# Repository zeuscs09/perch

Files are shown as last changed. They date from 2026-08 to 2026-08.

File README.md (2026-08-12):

<p align="center">
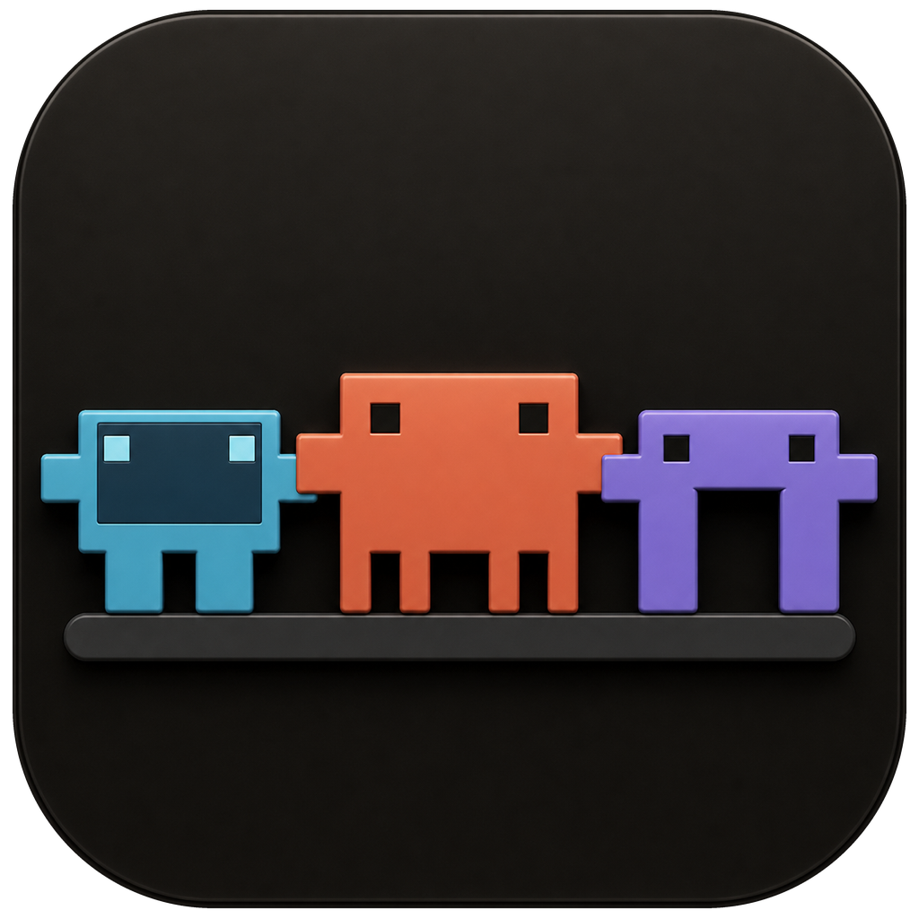
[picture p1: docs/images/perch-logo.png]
  
</p>

<h1 align="center">Perch</h1>

<p align="center">
  <strong>A little screen that perches on your desk</strong> — what your coding agents are
  doing, without giving up a window for it.
</p>

<p align="center">
  
  
  
  
  
  
</p>

<p align="center">
  🌐 <strong>English</strong> · <a href="README.th.md">ไทย</a>
</p>

<p align="center">
  <a href="#what-the-screen-says">What the screen says</a> ·
  <a href="#what-you-need">What you need</a> ·
  <a href="#1-get-the-repository-and-the-swift-compiler">Getting started</a> ·
  <a href="#the-case">The case</a> ·
  <a href="#on-the-go">On the go</a> ·
  <a href="#troubleshooting">Troubleshooting</a>
</p>

<p align="center">
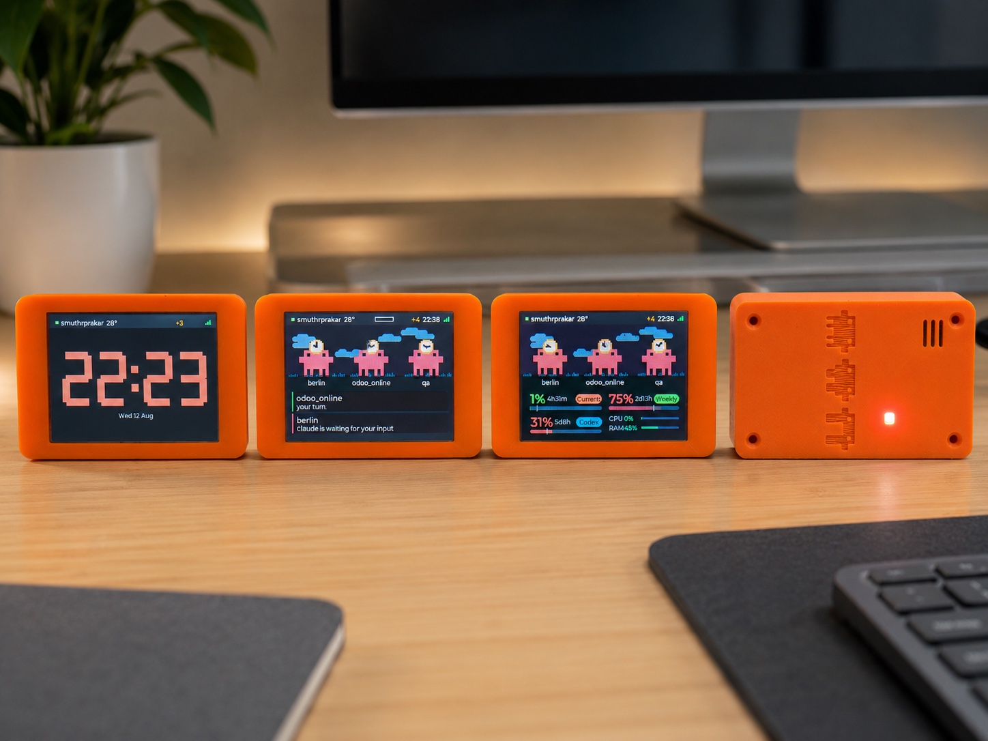
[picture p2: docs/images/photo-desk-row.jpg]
Four Perch units side by side on a desk: the clock, two sessions with status cards, the quota screen, and the back cover with its engraved mascots and status LED
  
</p>

<p align="center"><sub>Left to right: the clock it becomes after 21:00 · sessions that need
you · quota and machine load · the back, with the status LED and the three species engraved.</sub></p>

> **Before you start**
> - **macOS only.** The app that talks to Claude Code is a Swift menu bar app for macOS 14
>   or newer. There is no Linux or Windows build, and the firmware alone does nothing
>   without it.
> - **Unofficial.** A personal hobby project, not affiliated with or endorsed by Anthropic.
>   "Claude" and "Claude Code" belong to them.
> - **As-is.** Flashing firmware overwrites whatever is on the board, and you do it at your
>   own risk. No warranty — see [LICENSE](LICENSE).
> - Reading your quota from claude.ai is optional and needs an account credential. Read
>   [step 5](#5-quota-on-the-board) before you turn it on.

A desk device that shows what your coding agents are doing right now. Blocky little
creatures live on a small screen next to your keyboard — one per session, a different
species per agent: they type when the agent types, wave when a session needs your answer,
and celebrate when a build finishes. The bars at the bottom are your usage quota, the top
strip is the time and the weather, and after 21:00 the whole thing turns into a clock.

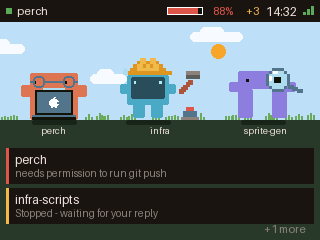
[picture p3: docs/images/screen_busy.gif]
Three sessions working, cards stacked on the right, quota bars at the bottom
 The menu bar panel: session usage, weekly usage, and the board's state

*The board, and the menu bar app that feeds it.*

Nothing leaves your network. A menu bar app on your Mac reads Claude Code's hooks and
pushes a small snapshot to the board over Bluetooth LE — and, if you set up Wi-Fi, over
your own LAN as a sealed fallback when Bluetooth goes quiet. The board never talks to
claude.ai.

## What the screen says

**While a session runs**

| Busy | Waiting for you | Done |
|:--|:--|:--|
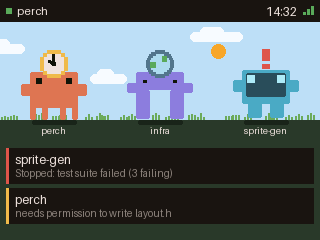
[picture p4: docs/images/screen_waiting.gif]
waiting
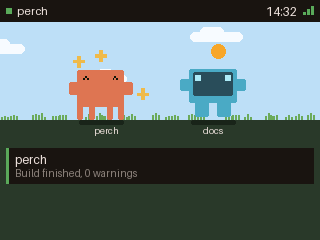
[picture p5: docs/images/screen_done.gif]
done
| busy |  |  |
| Up to three sessions and the tool each one is using. | A session stopped and wants an answer. | The mascot celebrates a finished turn. |

**When nothing is happening**

| Idle | No sessions | Offline |
|:--|:--|:--|
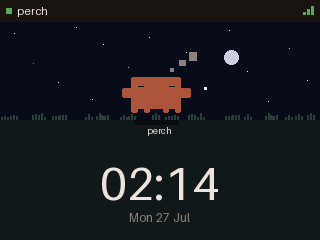
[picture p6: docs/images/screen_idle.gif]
idle
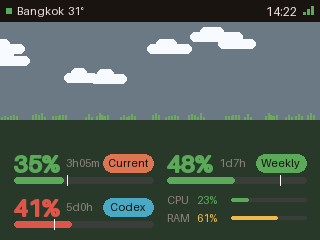
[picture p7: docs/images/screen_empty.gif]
empty
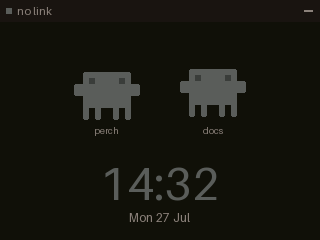
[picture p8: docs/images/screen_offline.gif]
offline
|  |  |  |
| One session, sleeping. Night sky and clock. | The mascot strolls. Clock and date. | The Mac is out of range or the app is not running. |

**Quota**

| Normal | Running hot | Unknown |
|:--|:--|:--|
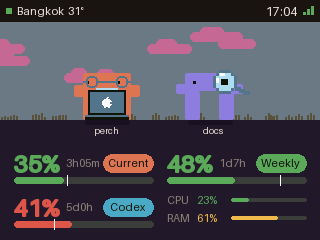
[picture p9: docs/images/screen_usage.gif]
usage
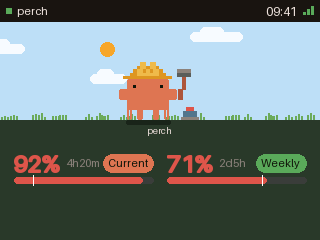
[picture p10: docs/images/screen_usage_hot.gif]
usage hot
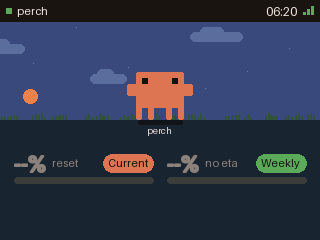
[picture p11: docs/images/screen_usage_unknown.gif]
usage unknown
|  |  |  |
| The current 5-hour window and the weekly one. | Near the limit; the tick marks your pace against the clock. | `--`, never a guess, when no number has arrived. |

**Over Wi-Fi**

| Still live | Nobody feeding it |
|:--|:--|
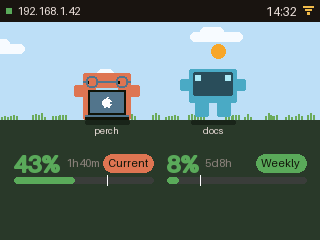
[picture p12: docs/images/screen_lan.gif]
lan
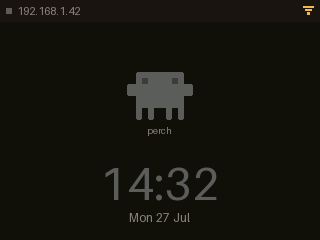
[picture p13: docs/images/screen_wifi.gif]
wifi
|  |  |
| Bluetooth is gone, so the label is the board's IP and the icon is a wave — but the snapshot still arrives, sealed, over the network. | The board is on the network with nothing to show: the Mac is asleep or the app is not running. |

**At night, and when you touch it**

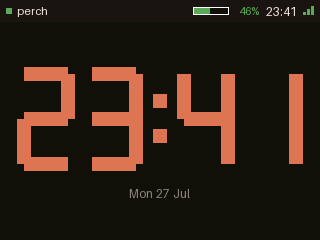
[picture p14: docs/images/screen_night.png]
The screen at night: a large seven-segment clock in the mascot's own orange, the date below it, and nothing else


From 21:00 to 07:00 the screen becomes a clock and nothing else: no mascot, no sky, no grass,
no alerts, and the onboard LED goes dark. Sessions keep running and alerts keep arriving —
they simply wait until morning. This is for a bedroom: a status display that lights up the
room at 3am is a status display you unplug. Touch the screen and it comes back to normal for
15 seconds, then settles again.

The digits are the mascot's own orange rather than white, and not only because it is the
project's colour — a warm colour carries far less blue, which is the part of the spectrum
that disrupts sleep most. Same brightness, different light.

Outside those hours the backlight fades down after a minute of no touching and wakes
instantly when you tap. Tapping also pages to the quota panel.

## Three agents, three species

Perch does not ask which agent you use — it watches for all three and shows whatever it finds.
The silhouettes differ, not just the colours, because from across a room you read a shape long
before you read a colour.

| | Looks like | Found by | Setup |
|:--|:--|:--|:--|
| **Claude Code** | Blocky, four legs, orange | Its hook system | One click in the gear menu |
| **Codex CLI** | A screen on two legs, blue | Reading its rollout files as they are written | **None** |
| **Antigravity** (`agy`) | An arch you can see through, purple | Reading `~/.gemini/antigravity-cli` | **None** |

Codex and Antigravity have no hook system to install into, so Perch reads the files they
already write. Nothing is configured, nothing of theirs is modified, and neither is asked to
report anything — if the tool is on the machine and running, it appears on the screen.

## What you need

**Hardware**

- An **ESP32-2432S028R** board — the "Cheap Yellow Display", 2.8" 320x240, roughly 300 baht.
  Tested against ESP32-D0WD-V3 rev 3.1, 4 MB flash, no PSRAM.
- A **USB data cable** for the board's micro-USB port. Charge-only cables do not enumerate.

<a href="https://s.shopee.co.th/4qEXaCOFvu">Buy the ESP32 2.8" board on Shopee</a>

<sub>That button is a Shopee affiliate link — buying through it costs you nothing extra and
sends a small commission here. Any seller's ESP32-2432S028R works just as well.</sub>

**Mac**

- macOS 14 or newer, with Bluetooth.
- [Claude Code](https://claude.com/claude-code) installed and logged in.

The Mac app is always built from source. The firmware you can either download or build —
step 2 has both routes.

A case is optional — the board works fine bare. If you have a printer or a print shop,
[the case](#the-case) is two parts and needs no supports.

## The case

Two printed parts, no supports, no screws beyond the four that come with the board. The
front is a bezel the board drops into; the back carries the three mascots and lets the
status LED through.

| Part | What it is | |
|---|---|---|
| **[front_case_v4_slot.stl](hardware/case/front_case_v4_slot.stl)** | the bezel — one long slot covers both the USB-C and micro-USB ports | [**⬇ download**](hardware/case/front_case_v4_slot.stl?raw=1) |
| **[back_cover.stl](hardware/case/back_cover.stl)** | the back — mascots engraved on the outside, vents for the LED | [**⬇ download**](hardware/case/back_cover.stl?raw=1) |
| **[PRINT_NOTE.txt](hardware/case/PRINT_NOTE.txt)** | settings that matter, in Thai and worth reading | [**⬇ download**](hardware/case/PRINT_NOTE.txt?raw=1) |

<sub>Click a filename and GitHub renders the STL as a model you can spin before you commit
a print; the download column gives you the file straight away.</sub>

<p align="center">
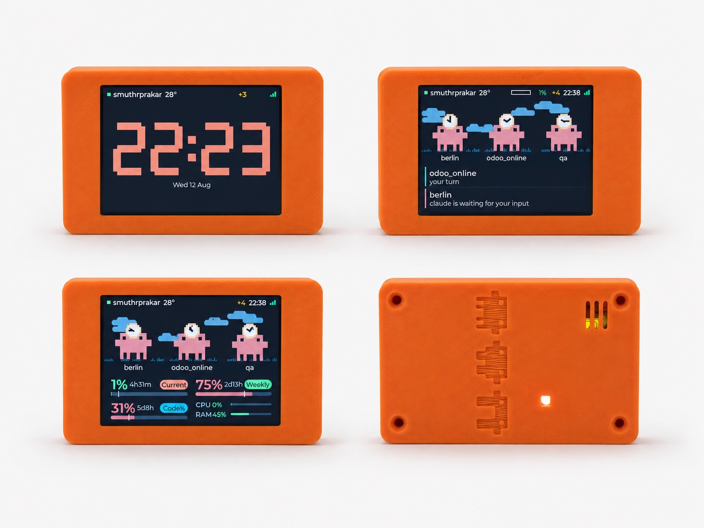
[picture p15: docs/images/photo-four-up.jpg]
Studio view of all four faces: clock, session cards, quota, and the engraved back cover
  
</p>

**Two settings decide whether it looks good**, and neither is the one people reach for
first. Print it in **4–5 perimeters with 5–6 solid top layers** — thin walls let the
screen's backlight glow through the plastic at night, and no amount of infill fixes it
(40% is plenty). A darker filament helps for the same reason.

Print the front face-down on the bed and the back engraving-side up. The engraving floor
is a top surface, so give it those solid layers or it comes out furry.

<p align="center">
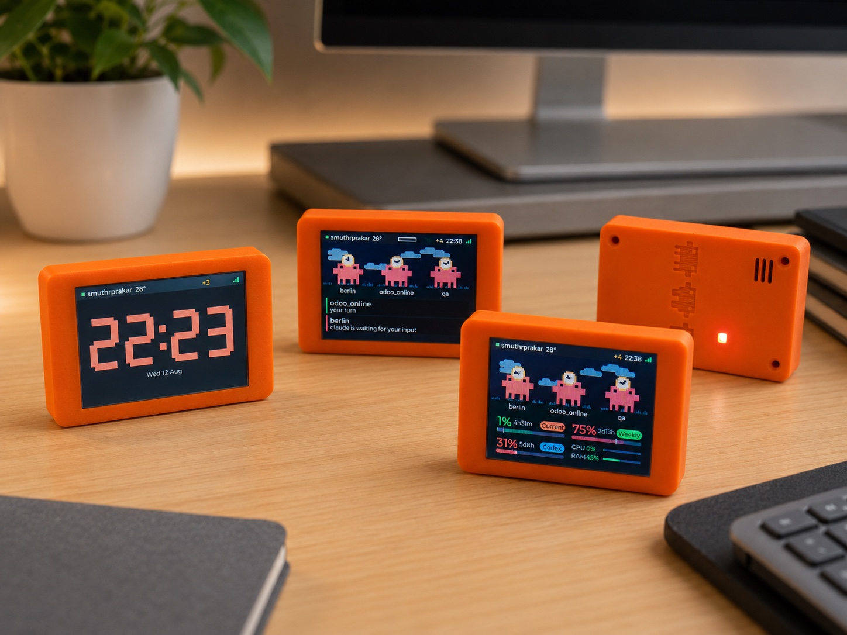
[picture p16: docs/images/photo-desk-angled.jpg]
Three units angled on a desk with the back cover behind them
  
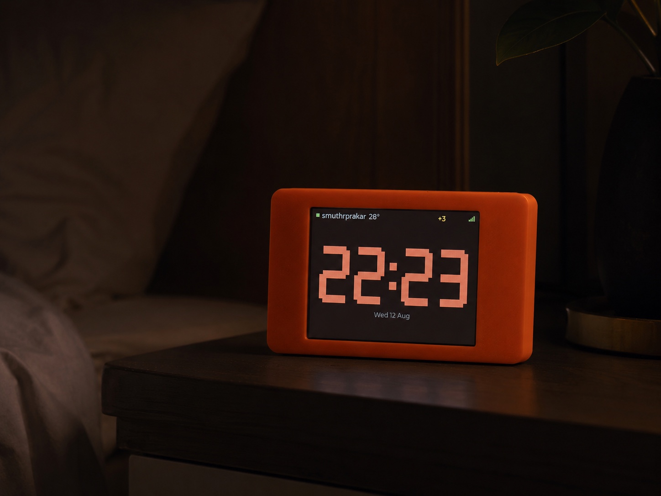
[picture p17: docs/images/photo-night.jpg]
A single unit on a nightstand at night, showing the clock face
  
</p>

<sub>These STLs are what we print and test-fit ourselves. They fit the ESP32-2432S028R
listed above; other boards with the same screen are not guaranteed to match.</sub>

## 1. Get the repository and the Swift compiler

```bash
xcode-select --install
git clone https://github.com/zeuscs09/perch.git
cd perch
```

## 2. Put the firmware on the board

Plug the board in and put its serial port into a variable, so the commands below work
as written:

```bash
PORT=$(ls /dev/cu.usbserial-* | head -1)
echo "$PORT"
```

That should print one path, something like `/dev/cu.usbserial-1420` — the number differs
from board to board and from port to port, which is why nothing below spells it out. If
it prints nothing, see [Troubleshooting](#troubleshooting).

`PORT` only exists in the terminal window you typed it in; if you open a new one, set it
again.

### Option A — flash a ready-made image (no ESP-IDF)

Download `perch-esp32-*.bin` from the
[latest release](https://github.com/zeuscs09/perch/releases/latest). It is one file,
about 1 MB, containing the bootloader, the partition table and the app.

```bash
python3 -m pip install esptool
python3 -m esptool --chip esp32 --port "$PORT" \
    write_flash 0x0 ~/Downloads/perch-esp32-1.0.4.bin
```

That is the whole toolchain: about 10 MB of Python, no compiler. Skip to step 3.

### Option B — build it yourself

Take this route if you want to change the firmware, or if your board turns out to need
different panel settings.

Build tools:

```bash
brew install cmake ninja dfu-util python3
```

ESP-IDF — this is the big one, roughly 2 GB. v5.5 is what this firmware is built and
tested against; the component manifest accepts 5.4 and newer:

```bash
mkdir -p ~/esp && cd ~/esp
git clone -b v5.5 --recursive https://github.com/espressif/esp-idf.git
cd esp-idf && ./install.sh esp32
```

Then, from the repository, load the toolchain into your shell and flash:

```bash
cd firmware
. $HOME/esp/esp-idf/export.sh
idf.py -p "$PORT" flash monitor
```

The `export.sh` line is per-shell and is not permanent; open a new terminal and you run
it again. The first build takes several minutes. If anything here goes wrong, Espressif's
own [getting-started guide](https://docs.espressif.com/projects/esp-idf/en/v5.5/esp32/get-started/)
is the authority.

### Either way

The screen lights up and the board starts announcing itself over Bluetooth as
`perch-3f7a` — the last part comes from its MAC address, so you can tell two boards
apart. With `idf.py monitor` running you can watch it happen; press `Ctrl+]` to leave.

## 3. Install the Mac app

```bash
cd ../host
./Scripts/make-app.sh --install
```

This builds `Perch.app`, copies it to `/Applications`, and launches it. macOS asks
for Bluetooth permission the first time — say yes, or the app can never see the board.

A small mascot icon appears in your menu bar. Click it for the quota panel; click the
gear for settings. The foot of the panel tells you whether the board is connected and
what each session is doing.

The badge next to the icon is your session usage, and it turns red when you are burning
through the window faster than the clock is.

## 4. Connect it to Claude Code

Everything below is in **gear ▸ Settings… ▸ General**:

- **Install hooks in settings.json** — this is the one that matters. It teaches
  Claude Code to tell the app what it is doing. Nothing appears on the board without it.
  Your existing settings are kept, and a backup is written beside the file.
- **Board** — pick your board by name, or leave it on *Any board*.
- **Brightness** — the slider drives the screen's backlight.
- **Weather** — type a city, press Search, pick from the results. The sky above the mascots
  then follows the real one: cloud, rain, fog, and the time of day. Leave it off and the sky
  is a plain gradient that still tracks morning, day, dusk and night.
- **Launch at login** — so it is running before you start work.

Start a Claude Code session in any terminal — or `codex`, or `agy`. Within a second or two
something should start moving.

## 5. Quota on the board

The bars at the bottom of the screen have two independent sources, both optional:

- **Read quota from the statusline** (Settings ▸ General) installs a Claude Code statusline
  that hands the app your current usage. It needs no password, but it only updates while
  Claude Code is running.
- **Set session key…** (Settings ▸ General) lets the app ask claude.ai directly, so the
  number keeps moving even with Claude Code closed. **Refresh quota** then chooses how
  often (Off / 60s / 5 min).

> **About the session key.** It is the `sessionKey` cookie of a logged-in claude.ai
> browser session, and it is a **full-account credential** — anyone holding it can act as
> your account. The app stores it in `~/.perch/session-key` with mode 600 and never
> puts it in a command line, an environment variable, or a log. Take it out at any time
> by deleting that file, and revoke it by logging out of claude.ai in the browser you
> copied it from. If you would rather not, skip this — the statusline route above still
> shows a number.
>
> To get one: in your browser, open claude.ai while logged in → DevTools → Application →
> Cookies → `claude.ai` → copy the value of `sessionKey`.

Taking over the statusline slot never changes what you see: your own statusline command is
handed the same input and its output is printed as is. If you never had one, the app draws
this instead — the same elements, colours, and `~/.claude/statusline-config.txt` as the
statusline that ships with Claude Usage.

The statusline the app draws: directory, branch, model, changed lines, token count, then the 5-hour and weekly quota bars with a pace mark and a reset countdown

## 6. Wi-Fi, so the screen survives Bluetooth (optional)

Bluetooth is the main path and always wins. It also drops — you walk past the board, the
Mac half-sleeps — and until now that left a frozen screen. Put the board on your network
and the app keeps feeding it when Bluetooth has been quiet for ten seconds.

**gear ▸ Settings… ▸ Wi-Fi**, with the board in Bluetooth range:

1. The list fills in as the *board* scans — not your Mac, so what you see is what the
   board can actually reach. It is 2.4 GHz only; a 5 GHz-only network will not appear.
2. Pick a network, type the password, **Connect**. macOS pairs with the board the first
   time; there is no six-digit code to enter.
3. It says `Connected to <name>` with the board's address. The board remembers up to five
   networks and comes back on its own after a power cut.

You do not have to configure anything on the Mac side. The snapshot is sealed with
AES-256-GCM under a key the app generates and pushes to the board over the same encrypted
channel as your Wi-Fi password, and the board is found over mDNS — the address box at the
bottom of the tab is only for networks that filter it.

The board still never talks to claude.ai; your session key never leaves the Mac.

## On the go

Both links so far assume the Mac and the board can reach each other: Bluetooth wants about
ten metres, and the LAN path wants the same network. Step outside either and the screen
stops moving. If you want it on a hotel desk or in a café, there are two routes — at very
different stages of proof.

Public Wi-Fi is not one of them. Captive portals need a browser the board does not have.
Use your phone's hotspot instead, which has no login page. And bring power: the case has
no battery, so a USB power bank is what keeps it alive.

**Route 1 — Tailscale.** Your phone shares a hotspot, the board joins it, the phone runs
Tailscale as a subnet router advertising that hotspot's subnet, and the Mac runs with
`--accept-routes`. The Mac then reaches the board at its hotspot address as though it were
sitting on your LAN — nothing to run, nothing to host. Two catches: **the phone has to be
Android**, because iOS cannot act as a subnet router, and the hotspot subnet must not
collide with your home one. Tested on foot a long way from home, with the screen still
updating.

**Route 2 — a relay you run.** The board dials *out* to a relay, the Mac dials *out* to the
same relay, and they meet in the middle, so NAT stops being a problem for either side. Any
phone's hotspot works and Tailscale is not involved.

The relay holds no key. The payload is sealed with AES-256-GCM before it leaves either
end, so the relay only ever moves ciphertext and needs no TLS of its own — which is what
makes this fit at all: a TLS handshake wants 20–40 KB, the board's lowest measured free
heap is 26.8 KB, and an outbound TCP socket costs 556 bytes. [`relay/perch-relay.py`](relay/perch-relay.py)
is about 140 lines with no dependencies.

```bash
defaults write com.perch.daemon relayHost <your relay's address>
defaults write com.perch.daemon relayPort -int 7333
```

There is no default address, and an empty one disables the route. A relay is somebody's
server; shipping one as a factory default would point every board cloned from this repo at
a machine whose owner never agreed to it.

> **Where route 2 actually stands.** The board half is proven — it dialled out from a phone
> hotspot on a mobile IP, and the address survives reflashing firmware built without it.
> The Mac half has never once executed, because the direct LAN path won every time it was
> tested. The code is written and reads correctly, which is not the same as working. If you
> try it, [issue #1](https://github.com/zeuscs09/perch/issues/1) is where to say what
> happened.

## Troubleshooting

**No `/dev/cu.usbserial-*` when the board is plugged in.**
Usually the cable — many micro-USB cables carry power only. Failing that, the board's
USB-serial chip (CH340) may need a driver on older macOS releases.

**Flashing stops at "Connecting........".**
Hold the **BOOT** button on the board, start `idf.py flash`, and release it once the log
says `Connecting`. Also close any serial monitor still holding the port.

**The screen is on but the colours are wrong, or the image is mirrored.**
Some batches of this board ship a different panel than the one this firmware was measured
against. Run the probe project in `firmware/probe/` to read out what your panel actually
reports, then change the two constants it disagrees with in `firmware/main/pch_lcd.c`:
the `0x36` (MADCTL) value for orientation and mirroring, and `0x20` (inversion off) versus
`0x21` (inversion on) for inverted colours.

**The board never shows up in the Board menu.**
Check that the app has Bluetooth permission in System Settings → Privacy & Security →
Bluetooth, that the board is powered, and that nothing else is connected to it — the
firmware accepts exactly one connection at a time.

**macOS asks for Bluetooth permission again after every rebuild.**
Expected. The app is signed ad-hoc, so each build is a new identity as far as macOS is
concerned. There is no way around it without an Apple Developer ID.

**The mascot never moves.**
The hooks are probably not installed — Settings ▸ General → *Install hooks in
settings.json*. Sessions already open when you install them keep the old settings; start
a new one. *Open log* in the same tab shows what the app is receiving.

**The Wi-Fi list stays empty, or the spinner never stops.**
Wi-Fi is set up over Bluetooth, so the board has to be connected first — the tab says so
when it is not. The list only ever holds 2.4 GHz networks.

**The board is on the network and pings, but the screen still freezes when Bluetooth
goes.**
macOS 15 and newer ask for Local Network permission separately, and a refusal silences
both mDNS and direct connections with no error at all. System Settings ▸ Privacy &
Security ▸ Local Network.

## Known limits

- **macOS only.** The app that talks to Claude Code is a Swift menu bar app; there is no
  Linux or Windows build.
- **No over-the-air updates.** New firmware means plugging the USB cable back in.
- **The speaker is unused.** The board has a speaker pin; nothing is wired up to it yet.
- **Ad-hoc signing.** The app is not notarised, so it is built per-machine rather than
  handed around.

## Credit

Perch is a fork of [TamaClaude](https://github.com/thaitop/tamaclaude) by Uthai Moolpak,
which is where the board bring-up, the rectangle renderer, and the BLE protocol came from.
It was renamed because what it does drifted a long way from raising a virtual pet: it is
now a status display, a clock, and a weather panel that happens to know about your agents.
Fixes that apply to both projects still go upstream as pull requests.

## License

MIT — see [LICENSE](LICENSE).

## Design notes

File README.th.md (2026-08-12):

<p align="center">
  
</p>

<h1 align="center">Perch</h1>

<p align="center">
  <strong>จอเล็กๆ ที่เกาะอยู่บนโต๊ะ</strong> — คอยบอกว่า agent ที่รันอยู่กำลังทำอะไร
  โดยไม่ต้องเสียพื้นที่หน้าจอให้มัน
</p>

<p align="center">
  
  
  
  
  
  
</p>

<p align="center">
  🌐 <a href="README.md">English</a> · <strong>ไทย</strong>
</p>

<p align="center">
  <a href="#จอบอกอะไรบ้าง">จอบอกอะไรบ้าง</a> ·
  <a href="#ของที่ต้องมี">ของที่ต้องมี</a> ·
  <a href="#1-เอา-repo-กับคอมไพเลอร์-swift-มาก่อน">เริ่มใช้งาน</a> ·
  <a href="#เคส">เคส</a> ·
  <a href="#พาออกนอกบ้าน">พาออกนอกบ้าน</a> ·
  <a href="#แก้ปัญหา">แก้ปัญหา</a>
</p>

<p align="center">
  Perch สี่ตัวเรียงกันบนโต๊ะ: หน้าปัดนาฬิกา · การ์ดของ session ที่รอคำตอบ · โควตากับภาระเครื่อง · ฝาหลังที่มีลายมาสคอตกับไฟสถานะ
</p>

<p align="center"><sub>ซ้ายไปขวา: หน้านาฬิกาที่มันกลายเป็นหลังสามทุ่ม · session ที่รอคำตอบจากคุณ ·
โควตากับภาระเครื่อง · ฝาหลังที่มีไฟสถานะและลายสามสายพันธุ์เซาะไว้</sub></p>

> **อ่านก่อนเริ่ม**
> - **ใช้ได้บน macOS เท่านั้น** ตัวที่คุยกับ Claude Code เป็นแอปแถบเมนูภาษา Swift สำหรับ macOS 14 ขึ้นไป
>   ไม่มีตัวสำหรับ Linux หรือ Windows และ firmware เพียงลำพังทำอะไรไม่ได้ถ้าไม่มีแอปนี้
> - **ไม่ใช่ของทางการ** เป็นโปรเจกต์งานอดิเรกส่วนตัว ไม่ได้สังกัดหรือได้รับการรับรองจาก Anthropic
>   ชื่อ "Claude" และ "Claude Code" เป็นของพวกเขา
> - **ใช้ตามสภาพ** การแฟลชจะเขียนทับทุกอย่างที่อยู่บนบอร์ด และคุณทำด้วยความเสี่ยงของตัวเอง
>   ไม่มีการรับประกันใดๆ ดู [LICENSE](LICENSE)
> - การดึงโควตาจาก claude.ai เป็นทางเลือก และต้องใช้ credential ของบัญชี
>   อ่าน [ขั้นที่ 5](#5-โควตาบนจอ) ให้จบก่อนเปิดใช้

อุปกรณ์ตั้งโต๊ะที่บอกว่า agent ที่คุณรันอยู่กำลังทำอะไร ตัวเหลี่ยมๆ อาศัยอยู่บนจอเล็กๆ ข้างคีย์บอร์ด
ตัวละหนึ่ง session และคนละสายพันธุ์ตามแต่ละ agent — พิมพ์ตามตอนมันพิมพ์ โบกมือตอนมี session
รอคำตอบจากคุณ และดีใจตอนบิลด์เสร็จ แถบล่างคือโควตาการใช้งาน แถบบนคือเวลากับสภาพอากาศ
และหลังสามทุ่มทั้งจอจะกลายเป็นนาฬิกา

สาม session กำลังทำงาน การ์ดเรียงทางขวา แถบโควตาด้านล่าง แผงบนแถบเมนู: โควตาของหน้าต่างปัจจุบัน โควตารายสัปดาห์ และสถานะของบอร์ด

*บอร์ด กับแอปแถบเมนูที่ป้อนข้อมูลให้มัน*

ไม่มีอะไรวิ่งออกนอกวงเน็ตของคุณ แอปบนแถบเมนูของ Mac อ่าน hook ของ Claude Code แล้วส่งข้อมูล
ก้อนเล็กๆ ไปที่บอร์ดผ่าน Bluetooth LE — และถ้าตั้ง Wi-Fi ไว้ ก็เดินทางบน LAN ของคุณเองแบบเข้ารหัส
ตอน Bluetooth เงียบ ส่วนบอร์ดไม่เคยคุยกับ claude.ai เลย

## จอบอกอะไรบ้าง

**ตอนมี session ทำงานอยู่**

| กำลังยุ่ง | รอคุณอยู่ | เสร็จแล้ว |
|:--|:--|:--|
| กำลังยุ่ง | รอคุณอยู่ | เสร็จแล้ว |
| มากสุดสาม session พร้อมเครื่องมือที่แต่ละตัวใช้อยู่ | session หยุดแล้วรอคำตอบจากคุณ | มาสคอตดีใจกับเทิร์นที่เพิ่งจบ |

**ตอนไม่มีอะไรเกิดขึ้น**

| ว่าง | ไม่มี session | ออฟไลน์ |
|:--|:--|:--|
| ว่าง | ไม่มี session | ออฟไลน์ |
| มี session เดียวและมันหลับอยู่ ฟ้ากลางคืนกับนาฬิกา | มาสคอตเดินเล่น มีนาฬิกาและวันที่ | Mac อยู่ไกลเกินไป หรือแอปไม่ได้เปิดอยู่ |

**โควตา**

| ปกติ | ใกล้เต็ม | ยังไม่รู้ค่า |
|:--|:--|:--|
| โควตาปกติ | ใกล้เต็ม | ยังไม่รู้ค่า |
| หน้าต่าง 5 ชั่วโมงปัจจุบันกับรายสัปดาห์ | ใกล้ชนเพดาน ขีดเล็กๆ บอกจังหวะการใช้เทียบกับเวลา | ขึ้น `--` ไม่เดาค่าให้ ตอนที่ยังไม่มีตัวเลขมาถึง |

**ตอนเดินบน Wi-Fi**

| ยังทำงานอยู่ | ไม่มีใครป้อน |
|:--|:--|
| บน LAN | อยู่บนเน็ตเฉยๆ |
| Bluetooth หลุดไปแล้ว ป้ายบนแถบจึงเปลี่ยนเป็น IP ของบอร์ดและไอคอนเป็นคลื่น แต่ snapshot ยังเดินทางมาถึงอยู่ เข้ารหัสมาทางเครือข่าย | บอร์ดอยู่บนเน็ตแต่ไม่มีอะไรจะแสดง — Mac Sleep หรือแอปไม่ได้เปิดอยู่ |

**ตอนกลางคืน และตอนที่คุณแตะมัน**

จอตอนกลางคืน: นาฬิกาเจ็ดขีดตัวใหญ่สีเดียวกับลำตัวมาสคอต มีวันที่อยู่ข้างล่าง และไม่มีอะไรอีกเลย

สามทุ่มถึงเจ็ดโมงเช้า จอเหลือแค่นาฬิกา ไม่มีมาสคอต ไม่มีท้องฟ้า ไม่มีสนามหญ้า ไม่มีการเตือน
และไฟ LED บนบอร์ดดับสนิท — session ยังทำงานอยู่และการเตือนยังมาถึงตามปกติ มันแค่รอจนเช้า
ที่เป็นแบบนี้เพราะมันไว้ตั้งในห้องนอน จอบอกสถานะที่ส่องสว่างทั้งห้องตอนตีสามคือจอที่จะถูกถอดปลั๊ก
แตะจอแล้วมันกลับมาเป็นปกติ 15 วินาที แล้วค่อยกลับไปนอนต่อ

ตัวเลขเป็นสีเดียวกับลำตัวมาสคอตแทนที่จะเป็นสีขาว ไม่ใช่แค่เพราะมันเป็นสีประจำโครงการ —
สีอุ่นมีองค์ประกอบสีน้ำเงินน้อยกว่ามาก ซึ่งเป็นช่วงคลื่นที่รบกวนการนอนมากที่สุด
ความสว่างเท่ากัน แต่เป็นแสงคนละแบบ

นอกช่วงนั้น ไฟหลังจอจะหรี่ลงเองหลังไม่มีใครแตะหนึ่งนาที และสว่างขึ้นทันทีที่แตะ
การแตะยังใช้พลิกไปดูหน้าโควตาได้ด้วย

## สาม agent สามสายพันธุ์

Perch ไม่ถามว่าคุณใช้ agent ตัวไหน — มันเฝ้าดูทั้งสามตัวแล้วแสดงตัวที่เจอ
ซิลลูเอ็ตต่างกันไม่ใช่แค่สีต่างกัน เพราะมองจากอีกฝั่งห้อง สายตาอ่าน *รูปทรง* ออกก่อนอ่าน *สี*

| | หน้าตา | ตรวจเจอด้วย | ต้องตั้งค่าไหม |
|:--|:--|:--|:--|
| **Claude Code** | ตัวเหลี่ยม สี่ขา สีส้ม | ระบบ hook ของมัน | กดครั้งเดียวในเมนูเฟือง |
| **Codex CLI** | จอบนสองขา สีฟ้า | อ่านไฟล์ rollout ที่มันเขียนอยู่แล้ว | **ไม่ต้อง** |
| **Antigravity** (`agy`) | ซุ้มโค้งที่มองทะลุได้ สีม่วง | อ่าน `~/.gemini/antigravity-cli` | **ไม่ต้อง** |

Codex กับ Antigravity ไม่มีระบบ hook ให้ติดตั้ง Perch จึงไปอ่านไฟล์ที่มันเขียนไว้อยู่แล้ว
ไม่ต้องตั้งค่าอะไร ไม่แตะของของมันสักไฟล์ และไม่ได้ขอให้มันรายงานอะไรทั้งนั้น —
ถ้าเครื่องมือนั้นอยู่ในเครื่องและกำลังทำงาน มันจะโผล่บนจอเอง

## ของที่ต้องมี

**ฮาร์ดแวร์**

- บอร์ด **ESP32-2432S028R** หรือที่เรียกกันว่า "Cheap Yellow Display" จอ 2.8" 320x240
  ราคาราวๆ 300 บาท ทดสอบกับ ESP32-D0WD-V3 rev 3.1 แฟลช 4 MB ไม่มี PSRAM
- **สาย USB ที่ส่งข้อมูลได้** สำหรับพอร์ต micro-USB ของบอร์ด สายชาร์จอย่างเดียวจะไม่ขึ้นพอร์ต

<a href="https://s.shopee.co.th/4qEXaCOFvu">สั่งซื้อบอร์ด ESP32 2.8 นิ้ว บน Shopee</a>

<sub>ปุ่มนี้เป็นลิงก์ affiliate ของ Shopee — กดซื้อผ่านลิงก์นี้ราคาเท่าเดิม
แต่มีค่าคอมมิชชันเล็กน้อยกลับมาที่โปรเจกต์ ถ้าจะซื้อจากร้านไหนก็ได้เหมือนกัน
ขอแค่เป็น ESP32-2432S028R</sub>

**เครื่อง Mac**

- macOS 14 ขึ้นไป และมี Bluetooth
- ติดตั้ง [Claude Code](https://claude.com/claude-code) และล็อกอินแล้ว

แอปฝั่ง Mac บิลด์เองเสมอ ส่วน firmware เลือกได้ว่าจะโหลดไฟล์สำเร็จรูปหรือบิลด์เอง — ขั้นที่ 2 มีทั้งสองทาง

เคสเป็นของเสริม บอร์ดเปล่าก็ใช้ได้ปกติ ถ้ามีเครื่องพิมพ์หรือร้านรับพิมพ์ [เคส](#เคส) มีสองชิ้น ไม่ต้องใช้ support

## เคส

พิมพ์สองชิ้น ไม่ต้อง support ไม่ต้องใช้สกรูเพิ่มนอกจากสี่ตัวที่ติดมากับบอร์ด ฝาหน้าเป็นกรอบให้บอร์ดวางลงไป
ฝาหลังมีลายมาสคอตกับช่องให้ไฟสถานะลอดออกมา

| ชิ้นส่วน | คืออะไร | |
|---|---|---|
| **[front_case_v4_slot.stl](hardware/case/front_case_v4_slot.stl)** | ฝาหน้า — ช่องพอร์ตเป็นช่องยาวช่องเดียว ครอบทั้ง USB-C และ micro-USB | [**⬇ โหลด**](hardware/case/front_case_v4_slot.stl?raw=1) |
| **[back_cover.stl](hardware/case/back_cover.stl)** | ฝาหลัง — ลายมาสคอตเซาะที่ผิวนอก มีช่องระบายให้ไฟ LED | [**⬇ โหลด**](hardware/case/back_cover.stl?raw=1) |
| **[PRINT_NOTE.txt](hardware/case/PRINT_NOTE.txt)** | ค่าที่ต้องตั้ง อ่านก่อนสั่งพิมพ์ | [**⬇ โหลด**](hardware/case/PRINT_NOTE.txt?raw=1) |

<sub>กดที่ชื่อไฟล์ GitHub จะเรนเดอร์ STL เป็นโมเดลให้หมุนดูก่อนตัดสินใจพิมพ์
ส่วนช่องขวาคือโหลดไฟล์ตรงๆ เลย</sub>

<p align="center">
  ภาพสตูดิโอครบสี่ด้าน: นาฬิกา · การ์ด session · โควตา · ฝาหลังที่เซาะลาย
</p>

**สองค่านี้ตัดสินว่าจะออกมาสวยไหม** และไม่ใช่ค่าที่คนส่วนใหญ่นึกถึงก่อน — ตั้ง **perimeter 4-5 ชั้น
กับ top solid 5-6 ชั้น** เพราะผนังบางจะมีแสงจากจอลอดผ่านเนื้อพลาสติกตอนกลางคืน และเพิ่ม infill ไม่ช่วย
(40% พอแล้ว) ใช้เส้นสีเข้มช่วยได้ด้วยเหตุผลเดียวกัน

วางฝาหน้าคว่ำหน้าจอลงเตียงพิมพ์ ส่วนฝาหลังหงายด้านลายขึ้น — ก้นร่องที่เซาะลายเป็น top surface
ถ้าไม่ให้ solid layer พอ มันจะออกมาเป็นขนๆ

<p align="center">
  สามตัววางเอียงบนโต๊ะ มีฝาหลังตั้งอยู่ด้านหลัง
  ตัวเดียวบนโต๊ะข้างเตียงตอนกลางคืน โชว์หน้านาฬิกา
</p>

<sub>STL ชุดนี้คือชุดที่เราพิมพ์และลองประกอบเอง พอดีกับ ESP32-2432S028R ที่ระบุไว้ข้างบน
บอร์ดอื่นที่ใช้จอเดียวกันไม่รับประกันว่าจะพอดี</sub>

## 1. เอา repo กับคอมไพเลอร์ Swift มาก่อน

```bash
xcode-select --install
git clone https://github.com/zeuscs09/perch.git
cd perch
```

## 2. เอา firmware ลงบอร์ด

เสียบบอร์ดแล้วเก็บชื่อพอร์ตอนุกรมของมันไว้ในตัวแปร เพื่อให้คำสั่งข้างล่างก๊อปไปใช้ได้ตรงๆ:

```bash
PORT=$(ls /dev/cu.usbserial-* | head -1)
echo "$PORT"
```

ควรได้หนึ่งบรรทัด หน้าตาประมาณ `/dev/cu.usbserial-1420` — ตัวเลขท้ายต่างกันไปตามบอร์ดและตามพอร์ตที่เสียบ
ข้างล่างจึงไม่เขียนชื่อพอร์ตตรงๆ สักที่ ถ้าไม่ขึ้นอะไรเลยดูหัวข้อ [แก้ปัญหา](#แก้ปัญหา)

ตัวแปร `PORT` มีอยู่เฉพาะหน้าต่างเทอร์มินัลที่คุณพิมพ์ ถ้าเปิดหน้าต่างใหม่ต้องตั้งใหม่

### ทาง A — แฟลชไฟล์สำเร็จรูป (ไม่ต้องลง ESP-IDF)

โหลด `perch-esp32-*.bin` จาก
[release ล่าสุด](https://github.com/zeuscs09/perch/releases/latest) เป็นไฟล์เดียวราว 1 MB
รวม bootloader, partition table และตัวแอปไว้ครบแล้ว

```bash
python3 -m pip install esptool
python3 -m esptool --chip esp32 --port "$PORT" \
    write_flash 0x0 ~/Downloads/perch-esp32-1.0.4.bin
```

เท่านี้จบ — Python ราว 10 MB ไม่ต้องมีคอมไพเลอร์ ข้ามไปขั้นที่ 3 ได้เลย

### ทาง B — บิลด์เอง

เลือกทางนี้ถ้าอยากแก้ firmware เอง หรือบอร์ดของคุณต้องใช้ค่าจอคนละชุด

เครื่องมือสำหรับบิลด์:

```bash
brew install cmake ninja dfu-util python3
```

ESP-IDF — ตัวใหญ่สุด ราว 2 GB v5.5 คือตัวที่ firmware นี้บิลด์และทดสอบด้วย
ส่วน manifest ของคอมโพเนนต์รับตั้งแต่ 5.4 ขึ้นไป:

```bash
mkdir -p ~/esp && cd ~/esp
git clone -b v5.5 --recursive https://github.com/espressif/esp-idf.git
cd esp-idf && ./install.sh esp32
```

จากนั้นกลับมาที่ repo โหลด toolchain เข้าเชลล์แล้วแฟลช:

```bash
cd firmware
. $HOME/esp/esp-idf/export.sh
idf.py -p "$PORT" flash monitor
```

บรรทัด `export.sh` มีผลเฉพาะเชลล์ที่รัน ไม่ถาวร เปิดเทอร์มินัลใหม่ก็ต้องรันใหม่ บิลด์ครั้งแรกใช้เวลาหลายนาที
ถ้าติดขั้นตอนไหน เอกสาร
[getting started ของ Espressif](https://docs.espressif.com/projects/esp-idf/en/v5.5/esp32/get-started/)
คือตัวจริง

### ไม่ว่าจะทางไหน

จอจะติดและบอร์ดจะเริ่มประกาศตัวบน Bluetooth ในชื่อ `perch-3f7a` — ส่วนท้ายมาจาก MAC address
ของมัน จึงใช้แยกบอร์ดสองตัวออกจากกันได้ ถ้าเปิด `idf.py monitor` ค้างไว้จะเห็นตอนมันเกิดขึ้น
กด `Ctrl+]` เพื่อออก

## 3. ติดตั้งแอปบน Mac

```bash
cd ../host
./Scripts/make-app.sh --install
```

คำสั่งนี้บิลด์ `Perch.app` ก๊อปไป `/Applications` แล้วเปิดให้เลย macOS จะขอสิทธิ์ Bluetooth
ครั้งแรก — ต้องอนุญาต ไม่งั้นแอปจะมองไม่เห็นบอร์ดตลอดไป

ไอคอนมาสคอตเล็กๆ จะโผล่บนแถบเมนู คลิกเพื่อดูแผงโควตา คลิกรูปเฟืองเพื่อตั้งค่า
ท้ายแผงบอกว่าบอร์ดต่ออยู่หรือเปล่า และแต่ละ session กำลังทำอะไร

ตัวเลขข้างไอคอนคือโควตาของหน้าต่างปัจจุบัน และจะเปลี่ยนเป็นสีแดงเมื่อคุณใช้เร็วกว่าที่เวลาเดิน

## 4. ต่อเข้ากับ Claude Code

ทั้งหมดนี้อยู่ใน **เฟือง ▸ Settings… ▸ General**:

- **Install hooks in settings.json** — ตัวที่สำคัญที่สุด มันสอนให้ Claude Code
  บอกแอปว่ากำลังทำอะไรอยู่ ถ้าไม่กดอันนี้จอจะไม่มีอะไรขึ้นเลย ค่าที่คุณตั้งไว้เดิมยังอยู่ครบ
  และมีไฟล์สำรองเขียนไว้ข้างๆ ให้ด้วย
- **Board** — เลือกบอร์ดตามชื่อ หรือปล่อยไว้ที่ *Any board*
- **Brightness** — สไลเดอร์คุมไฟหลังจอ
- **Weather** — พิมพ์ชื่อเมือง กด Search แล้วเลือกจากรายการ ท้องฟ้าเหนือมาสคอตจะเดินตามของจริง
  ทั้งเมฆ ฝน หมอก และช่วงเวลาของวัน ถ้าไม่เปิดใช้ ฟ้าจะเป็นไล่เฉดเรียบๆ ที่ยังเปลี่ยนตาม
  เช้า/กลางวัน/เย็น/กลางคืนอยู่ดี
- **Launch at login** — ให้แอปเปิดรออยู่ก่อนเริ่มงาน

เปิด session ในเทอร์มินัลไหนก็ได้ — จะเป็น Claude Code, `codex` หรือ `agy` ก็ได้
ไม่เกินหนึ่งสองวินาทีจะมีอะไรเริ่มขยับ

## 5. โควตาบนจอ

แถบด้านล่างของจอมีสองท่อที่เป็นอิสระต่อกัน และเป็นทางเลือกทั้งคู่:

- **Read quota from the statusline** (Settings ▸ General) ติดตั้ง statusline ของ Claude Code
  ที่ส่งค่าการใช้งานปัจจุบันให้แอป ไม่ต้องใช้รหัสผ่านใดๆ แต่ค่าจะขยับเฉพาะตอนที่ Claude Code เปิดอยู่
- **Set session key…** (Settings ▸ General) ให้แอปถาม claude.ai ตรงๆ ตัวเลขจึงเดินต่อแม้ปิด Claude Code
  ไปแล้ว จากนั้น **Refresh quota** เลือกความถี่ (Off / 60s / 5 min)

> **เรื่อง session key** มันคือคุกกี้ `sessionKey` ของเบราว์เซอร์ที่ล็อกอิน claude.ai อยู่ และเป็น
> **รหัสผ่านระดับทั้งบัญชี** — ใครถือไปก็ทำอะไรในนามบัญชีคุณได้ แอปเก็บมันไว้ที่
> `~/.perch/session-key` โหมด 600 และไม่เคยใส่มันลงบรรทัดคำสั่ง ตัวแปรสภาพแวดล้อม
> หรือไฟล์ล็อก ถอนออกเมื่อไหร่ก็ได้ด้วยการลบไฟล์นั้น และเพิกถอนตัวคีย์ด้วยการล็อกเอาต์ claude.ai
> จากเบราว์เซอร์ที่คุณก๊อปมา ถ้าไม่สบายใจก็ข้ามไปได้ — ท่อ statusline ด้านบนก็มีตัวเลขให้ดูอยู่แล้ว
>
> วิธีเอามา: เปิด claude.ai ในเบราว์เซอร์ตอนล็อกอินอยู่ → DevTools → Application → Cookies →
> `claude.ai` → ก๊อปค่าของ `sessionKey`

การยึดช่อง statusline ไม่เปลี่ยนสิ่งที่คุณเห็น — คำสั่ง statusline เดิมของคุณได้ข้อมูลก้อนเดิมไปวาด
แล้วผลของมันถูกพิมพ์ออกไปตรงๆ ส่วนคนที่ไม่เคยมี statusline มาก่อน แอปจะวาดแบบนี้ให้ ชิ้นส่วน สี
และไฟล์ตั้งค่า `~/.claude/statusline-config.txt` ชุดเดียวกับ statusline ที่มากับ Claude Usage

statusline ที่แอปวาด: โฟลเดอร์ branch โมเดล จำนวนบรรทัดที่แก้ จำนวน token แล้วต่อด้วยแถบโควตา 5 ชั่วโมงและรายสัปดาห์ พร้อมขีดบอกจังหวะและเวลานับถอยหลังถึงรีเซ็ต

## 6. Wi-Fi เพื่อให้จอรอดตอน Bluetooth หาย (ทางเลือก)

Bluetooth เป็นทางหลักและชนะเสมอ แต่มันก็หลุดได้ — คุณเดินผ่านบอร์ด Mac หลับไปครึ่งตัว
ซึ่งที่ผ่านมาแปลว่าจอค้าง เอาบอร์ดขึ้นเน็ตของคุณแล้วแอปจะป้อนต่อให้เองเมื่อ Bluetooth เงียบครบสิบวินาที

**เฟือง ▸ Settings… ▸ Wi-Fi** ตอนที่บอร์ดยังอยู่ในระยะ Bluetooth:

1. รายการทยอยขึ้นตามที่*บอร์ด*สแกนเจอ ไม่ใช่ที่ Mac เจอ สิ่งที่เห็นจึงเป็นวงที่บอร์ดเข้าถึงได้จริง
   บอร์ดรับได้แค่ 2.4GHz วงที่เป็น 5GHz ล้วนจะไม่โผล่
2. เลือกวง พิมพ์รหัส กด **Connect** ครั้งแรก macOS จะจับคู่กับบอร์ดเอง ไม่มีเลขหกหลักให้กรอก
3. จะขึ้น `Connected to <ชื่อวง>` พร้อมที่อยู่ของบอร์ด · บอร์ดจำได้ห้าวง และกลับขึ้นเน็ตเองหลังไฟดับ

ฝั่ง Mac ไม่ต้องตั้งอะไรเพิ่ม snapshot ถูกเข้ารหัสด้วย AES-256-GCM ด้วยกุญแจที่แอปสุ่มขึ้นเอง
แล้วผลักไปบอร์ดทางช่องที่เข้ารหัสอยู่แล้ว — ช่องเดียวกับรหัส Wi-Fi ของคุณ ส่วนการหาบอร์ดใช้ mDNS
ช่องกรอกที่อยู่ตรงท้ายแท็บมีไว้เผื่อเน็ตที่กรอง multicast เท่านั้น

บอร์ดยังไม่คุยกับ claude.ai อยู่ดี และ session key ไม่เคยออกจาก Mac

## พาออกนอกบ้าน

ทางเดินทั้งสองทางที่ผ่านมาตั้งอยู่บนสมมติฐานเดียวกัน คือ Mac กับบอร์ดต้องหากันเจอ — Bluetooth ขอราวสิบเมตร
ส่วนทาง LAN ขอให้อยู่วงเดียวกัน ก้าวออกจากสองอย่างนี้เมื่อไหร่จอก็หยุดขยับ ถ้าอยากเอาไปวางบนโต๊ะโรงแรม
หรือในคาเฟ่ มีสองทาง แต่ระดับความมั่นใจต่างกันมาก

**Wi-Fi สาธารณะไม่ใช่หนึ่งในนั้น** เพราะหน้า login (captive portal) ต้องใช้เบราว์เซอร์ซึ่งบอร์ดไม่มี
ให้ใช้ hotspot จากมือถือแทน มันไม่มีหน้า login และอย่าลืมไฟเลี้ยง — เคสไม่มีที่ใส่แบต ต้องพก power bank

**ทางที่ 1 — Tailscale** มือถือปล่อย hotspot บอร์ดเกาะ แล้วให้มือถือรัน Tailscale เป็น subnet router
ประกาศ subnet ของ hotspot นั้น ส่วน Mac เปิด `--accept-routes` จากนั้น Mac จะเห็นบอร์ดที่ที่อยู่ใน hotspot
เหมือนอยู่วง LAN บ้านเลย ไม่ต้องรันเซิร์ฟเวอร์อะไรเอง ติดสองข้อ: **มือถือต้องเป็น Android** เพราะ iOS
เป็น subnet router ไม่ได้ และ subnet ของ hotspot ต้องไม่ชนกับวงที่บ้าน — ทางนี้ทดสอบด้วยการเดินออกไปไกลมาก
แล้วจอยังเดินอยู่

**ทางที่ 2 — relay ที่เรารันเอง** บอร์ดวิ่ง *ออก* ไปหา relay ฝั่ง Mac ก็วิ่ง *ออก* ไปที่ relay ตัวเดียวกัน
แล้วมาเจอกันตรงกลาง NAT จึงไม่เป็นปัญหาของทั้งสองฝั่ง ใช้ hotspot มือถือรุ่นไหนก็ได้ ไม่ต้องยุ่งกับ Tailscale

**relay ไม่ถือกุญแจอะไรเลย** payload ถูกปิดผนึกด้วย AES-256-GCM ตั้งแต่ก่อนออกจากปลายทั้งสอง relay จึงเห็นแต่
ข้อมูลที่ถอดไม่ได้ และไม่ต้องมี TLS ของตัวเอง — ซึ่งเป็นเหตุผลที่เรื่องนี้ทำได้จริง เพราะ TLS handshake
ขอ 20-40 KB ส่วน heap ว่างต่ำสุดที่วัดได้บนบอร์ดคือ 26.8 KB และซ็อกเก็ต TCP ขาออกกินแค่ 556 ไบต์
ตัว [`relay/perch-relay.py`](relay/perch-relay.py) ยาวราว 140 บรรทัด ไม่มี dependency

```bash
defaults write com.perch.daemon relayHost <ที่อยู่ relay ของคุณ>
defaults write com.perch.daemon relayPort -int 7333
```

ไม่มีที่อยู่เริ่มต้น และค่าว่างคือปิดทางนี้ทิ้ง — relay คือเซิร์ฟเวอร์ของใครสักคน การใส่ที่อยู่ไว้เป็นค่าโรงงาน
แปลว่าบอร์ดของทุกคนที่ clone repo นี้ไปจะวิ่งไปหาเครื่องนั้นโดยเจ้าของไม่ได้ตกลงด้วย

> **ทางที่ 2 ยืนอยู่ตรงไหนจริงๆ** ฝั่งบอร์ดพิสูจน์แล้ว — มันวิ่งออกจาก hotspot มือถือบน IP มือถือได้จริง
> และค่าที่ตั้งไว้อยู่รอดข้ามการ flash เฟิร์มแวร์ที่ไม่มีธงนี้ **ส่วนฝั่ง Mac ยังไม่เคยถูกรันเลยสักครั้ง**
> เพราะทาง LAN ตรงชนะทุกครั้งที่ทดสอบ โค้ดเขียนไว้แล้วและอ่านดูเข้าท่า ซึ่งไม่ใช่เรื่องเดียวกับใช้ได้จริง
> ถ้าใครลองแล้วเป็นยังไง เขียนไว้ที่ [issue #1](https://github.com/zeuscs09/perch/issues/1) ได้เลย

## แก้ปัญหา

**เสียบบอร์ดแล้วไม่มี `/dev/cu.usbserial-*`**
ส่วนใหญ่เป็นที่สาย — สาย micro-USB จำนวนมากต่อแต่ไฟ ไม่ต่อข้อมูล ถ้าไม่ใช่สาย ชิป USB-serial
ของบอร์ด (CH340) อาจต้องลงไดรเวอร์บน macOS รุ่นเก่า

**แฟลชแล้วค้างที่ "Connecting........"**
กดปุ่ม **BOOT** บนบอร์ดค้างไว้ สั่ง `idf.py flash` แล้วปล่อยตอนล็อกขึ้นคำว่า `Connecting`
และปิด serial monitor ที่ยังจับพอร์ตอยู่ด้วย

**จอติดแต่สีเพี้ยน หรือภาพกลับด้าน**
บอร์ดรุ่นนี้บางล็อตมาพร้อมจอคนละตัวกับที่ firmware นี้วัดค่าไว้ ให้รันโปรเจกต์ probe ใน
`firmware/probe/` เพื่ออ่านว่าจอของคุณตอบอะไรจริง แล้วแก้ค่าสองตัวที่ไม่ตรงใน
`firmware/main/pch_lcd.c` — ค่าของคำสั่ง `0x36` (MADCTL) สำหรับทิศทางและการกลับด้าน
และ `0x20` (ปิด inversion) กับ `0x21` (เปิด inversion) สำหรับสีที่กลับกัน

**บอร์ดไม่โผล่ในเมนู Board สักที**
เช็กว่าแอปได้สิทธิ์ Bluetooth ใน System Settings → Privacy & Security → Bluetooth
ว่าบอร์ดมีไฟเข้า และไม่มีอะไรอื่นต่ออยู่กับมัน — firmware รับการเชื่อมต่อได้ทีละหนึ่งเท่านั้น

**macOS ขอสิทธิ์ Bluetooth ใหม่ทุกครั้งที่บิลด์**
เป็นเรื่องปกติ แอปเซ็นแบบ adhoc ทุกการบิลด์จึงเป็นคนละตัวตนในสายตา macOS
ไม่มีทางเลี่ยงถ้าไม่มี Apple Developer ID

**มาสคอตไม่ขยับเลย**
น่าจะยังไม่ได้ติดตั้ง hook — Settings ▸ General → *Install hooks in settings.json*
session ที่เปิดค้างอยู่ก่อนหน้าจะยังใช้ค่าเดิม ให้เปิด session ใหม่ ส่วน *Open log* ในแท็บเดียวกัน
จะบอกว่าแอปได้รับอะไรมาบ้าง

**รายการ Wi-Fi ว่างเปล่า หรือสปินเนอร์หมุนไม่หยุด**
การตั้ง Wi-Fi เดินทางบน Bluetooth บอร์ดจึงต้องต่ออยู่ก่อน — ถ้าไม่ต่อ ในแท็บจะบอกไว้แล้ว
และรายการมีแต่วง 2.4GHz เท่านั้นเสมอ

**บอร์ดอยู่บนเน็ตและ ping ผ่าน แต่พอ Bluetooth หลุดจอก็ยังค้าง**
macOS 15 ขึ้นไปขอสิทธิ์ Local Network แยกอีกตัว และถ้าถูกปฏิเสธ ทั้ง mDNS และการต่อไปหา IP ตรงๆ
จะเงียบไปโดยไม่มี error ให้เห็นเลย ดูที่ System Settings ▸ Privacy & Security ▸ Local Network

## ข้อจำกัดที่รู้อยู่

- **macOS เท่านั้น** แอปที่คุยกับ Claude Code เป็นแอปแถบเมนูภาษา Swift ยังไม่มีตัวสำหรับ Linux หรือ Windows
- **ไม่มีอัปเดตผ่านอากาศ** firmware ตัวใหม่แปลว่าต้องเสียบสาย USB อีกครั้ง
- **ลำโพงยังไม่ได้ใช้** บอร์ดมีขาลำโพงมาให้ แต่ยังไม่ได้ต่ออะไรเข้าไป
- **เซ็นแบบ adhoc** แอปไม่ได้ notarise จึงเป็นของที่บิลด์ทีละเครื่อง ไม่ใช่ของที่ส่งต่อกันได้

## เครดิต

Perch แยกตัวออกมาจาก [TamaClaude](https://github.com/thaitop/tamaclaude) ของ Uthai Moolpak
ซึ่งเป็นที่มาของการปลุกบอร์ด ตัววาดสี่เหลี่ยม และโพรโทคอล BLE

ที่เปลี่ยนชื่อเพราะสิ่งที่มันทำห่างจาก "เลี้ยงสัตว์เลี้ยงเสมือน" ไปไกลมากแล้ว
ตอนนี้มันคือจอบอกสถานะ นาฬิกา และแผงพยากรณ์อากาศ ที่บังเอิญรู้ว่า agent ของเรากำลังทำอะไรอยู่

ส่วนที่แก้แล้วใช้ได้กับทั้งสองโครงการยังส่งกลับไปเป็น pull request ให้ต้นทางเหมือนเดิม

## สัญญาอนุญาต

MIT — ดู [LICENSE](LICENSE)

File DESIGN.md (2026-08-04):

# Perch (CYD) — ข้อตกลงการออกแบบ

อุปกรณ์ตั้งโต๊ะที่แสดงสถานะ Claude Code session แบบเรียลไทม์ผ่านมาสคอต Claude
ฮาร์ดแวร์: ESP32-2432S028R ("Cheap Yellow Display")

เอกสารนี้บันทึก **สภาพปัจจุบัน + เหตุผลที่มองไม่เห็นจากโค้ด** เท่านั้น
ประวัติว่าอะไรเคยเป็นอะไรอยู่ใน git log — ไม่ต้องเขียนซ้ำที่นี่
เขียนเพิ่มเมื่อ *กลับคำ* ข้อตกลงเดิม หรือเจอข้อจำกัดที่โค้ดไม่ได้บอก

## ตัดสินใจแล้ว

| หัวข้อ | ผล |
|---|---|
| Firmware | ESP-IDF เขียนใหม่ทั้งหมด (ไม่ fork upstream) |
| Transport | BLE (NimBLE) เป็นทางหลัก + WiFi station เป็นทางสำรองบน LAN (ดู "WiFi") |
| จอ | ILI9341 320x240 แนวนอน |
| กราฟิกสแตก | LVGL v9 + custom draw widget 1 ตัวต่อ 1 slot |
| มาสคอต | ตัวละคร Claude สีส้ม `#D97757` บล็อคสี่เหลี่ยม |
| ผลิตกราฟิก | สคริปต์ Python generate แบบ procedural |
| รูปแบบ asset | rect list `{x,y,w,h,color}` — ไม่มีบิตแมป ไม่มี sprite pipeline |
| สื่อสถานะ | props (ตามเครื่องมือ) + eye state/ลำตัว (ตามอารมณ์) แยก 2 มิติ |
| ฝั่ง Mac | Swift binary เดียว: `--hook` / `--daemon` / menu bar app |
| tool → animation | daemon แปล (config file แก้ได้) firmware รู้แค่ enum คงที่ |
| โปรโตคอล | JSON snapshot ก้อนเดียว เขียนเข้า GATT characteristic |
| สถานะว่าง | มาสคอตนอน + นาฬิกา (ความสว่างคงที่ — ไม่หรี่อัตโนมัติ) |
| BLE หลุด | มาสคอตเปลี่ยนเป็นสีเทา (ไม่มีไอคอน ไม่มีข้อความ) |
| เกณฑ์เตือน | `Notification`/`StopFailure` = การ์ดแดง · `Stop` ที่เงียบเกิน ~45 วิ = การ์ด `done` |
| Slot | สูงสุด 3 ระยะห่างคงที่ 106px ยกทั้งกลุ่มไว้กึ่งกลาง เกินนับ "+N" แต่ alert ยังทะลุถึงได้ |
| Dev loop | Python เรนเดอร์จอทั้งใบเป็น PNG/GIF · layout constants gen จากไฟล์เดียว |
| โควตา | สองแหล่ง: ท่อ statusline (ไม่ต้องมี credential) + ท่อ poll (`sessionKey`) |
| พื้นที่ล่าง | ลำดับ: การ์ด > โควตา > นาฬิกาใหญ่ · การ์ดสูงสุด 2 ใบ ที่เหลือเป็น "+N more" · หลุดลิงก์ = เหลือนาฬิกา |
| ท้องฟ้า | ฟ้า 22..119 + พื้นดิน 120..240 (ครึ่งจอ) · กอหญ้าเกาะเส้นขอบฟ้าแถวเดียว |
| ช่วงเวลา | 4 ช่วงกระโดดที่ขอบ: night 19–05 · dawn 05–07 · day 07–17 · dusk 17–19 |
| แหล่งเวลา | parse ชั่วโมงจาก `snapshot.clock` ที่มีอยู่แล้ว — ไม่มีอะไรเพิ่มบนสาย BLE |
| ฟ้าตอนหลุดลิงก์ | ไม่วาดเลย กลับเป็นพื้น `bg` เรียบ — clock ที่ค้างไม่ใช่เวลาจริงอีกต่อไป |

## v1 scope

**อยู่ใน**: hooks → daemon → BLE → มาสคอตขยับตามเครื่องมือ · multi-session 3 ตัว ·
notification card · auto-reconnect · RGB LED กระพริบ · macOS menu bar app · config ผ่าน BLE ·
นาฬิกา sync จาก host

**ไม่อยู่ใน**: simulator SDL2 · เสียง · microSD · OTA · flash encryption

touch เคยอยู่ในรายการนี้ — **กลับคำแล้ว** แต่เอาแค่ "มีนิ้วไหม" ไม่เอาพิกัด: มันตอบสอง
คำถามที่คุ้มค่าทันที (หรี่จอตอนไม่มีใครดูเพื่อยืดแบต และเรียกดูแผงโควตาที่ปกติโผล่เฉพาะ
ตอนไม่มีการ์ด) โดยไม่ต้องคาลิเบรตและไม่ต้องมีปุ่มบนจอ ดูหัวข้อ "การแตะจอ"

WiFi เคยอยู่ในรายการนี้ — **กลับคำแล้ว** เพราะ BLE หายทันทีที่เดินออกจากโต๊ะ ทำให้จอค้าง
ทั้งที่ Mac ยังทำงานอยู่ ดูหัวข้อ "WiFi" ว่าเปิดแค่ไหนและไม่เปิดอะไร

**ยังไม่ได้ทำ**: เก็บสถานะข้ามการรีสตาร์ท daemon · ปรับ session timeout จากเมนู ·
แจกแบบ notarized (ต้องมีบัญชีนักพัฒนา)

## WiFi

**บอร์ดไม่เคยยิง claude.ai เอง** — WiFi มีไว้ให้ Mac ส่ง snapshot ผ่าน LAN เมื่อ BLE
ไกลเกินไป ไม่ใช่ให้บอร์ดไปดึงโควตาเอง เหตุผลคือ `sessionKey` เป็น credential เต็มบัญชี
ส่วนแฟลชบนบอร์ดไม่ได้เข้ารหัสและดัมพ์ออกได้ด้วยสาย USB (`esptool read_flash`) การย้าย
กุญแจไปไว้ที่นั่นคือการเปลี่ยนของที่หายแล้วต้องเปลี่ยนรหัสผ่านให้กลายเป็นของที่หยิบไปได้

ผลที่ตามมาที่ต้องยอมรับ: **Mac หลับ = จอค้างเหมือนเดิม** ทั้ง BLE และ LAN เงียบพร้อมกัน
ไอคอนบนแถบบนบอกสถานะนี้ตรงๆ แทนที่จะปล่อยให้ภาพเก่าดูเหมือนของสด

| หัวข้อ | ผล |
|---|---|
| ใครสแกนหาเครือข่าย | บอร์ด ไม่ใช่ Mac — ESP32 รับได้แค่ 2.4GHz และตั้งอยู่คนละที่กับ Mac รายการของ Mac จะมีวงที่บอร์ดเข้าไม่ได้ปนมา และ CoreWLAN ยังต้องขอสิทธิ์ Location เพิ่มอีกตัว |
| รายการเดินทางยังไง | หนึ่ง SSID ต่อหนึ่ง notification ปิดท้ายด้วย `{"t":"ap_end"}` — ไม่มี reassembly ไม่มีหมายเลขชิ้น ไม่มี timeout ให้พัง |
| คำสั่งเดินทางยังไง | config characteristic ซึ่งประกาศ `BLE_GATT_CHR_F_WRITE_ENC` — รหัส WiFi ของผู้ใช้ผ่านทางนั้น การจับคู่เป็น Just Works (บอร์ดไม่มีปุ่มให้ยืนยันเลขหกหลัก) กันคนดักฟังผ่านๆ ได้ ไม่กัน MITM ที่อยู่ตรงนั้นพอดีตอนกด Connect |
| จำได้กี่วง | 5 เลือกตัวที่สัญญาณแรงที่สุดในบรรดาที่จำไว้ เต็มแล้วตัวเก่าสุดหลุด |
| ต่อไม่ติด | ลองใหม่เรื่อยๆ backoff 1→60 วิ ไม่มีการเลิก — บอร์ดอยู่บนโต๊ะทั้งวันและไม่มีใครมากดปุ่ม |
| แฟลชไม่เข้ารหัส | ยอมรับ ไม่เปิด flash encryption: มัน burn eFuse ถาวรและทำให้ flash ผ่าน USB ยุ่ง ซึ่งเป็นช่องอัปเดตเดียวที่มี (ไม่มี OTA) ของที่เสียหากบอร์ดหาย = รหัส WiFi กับ PSK ที่เพิกถอนได้ |
| IRAM | `CONFIG_ESP_WIFI_IRAM_OPT=n` + `..._RX_IRAM_OPT=n` — IRAM ของ ESP32 มีก้อนเดียวและ BLE controller จองไปเกือบหมด ไม่ปิดสองตัวนี้แล้วลิงก์ไม่ผ่าน (`iram0_0_seg overflowed`) |

### ทางเดินที่สอง: snapshot บน LAN

BLE ยังเป็นทางหลักเสมอ ทาง LAN เปิดต่อเมื่อ BLE เงียบเกิน **10 วินาที** — การหลุดสั้นๆ
เกิดเป็นปกติ (เดินผ่านตัวเครื่อง, Mac หลับครึ่งหนึ่ง) และ CoreBluetooth ต่อกลับเองได้
การกระโดดไป LAN ทุกครั้งแปลว่าเปิดปิดซ็อกเก็ตทั้งวันเพื่อสิ่งที่หายเองอยู่แล้ว

| หัวข้อ | ผล |
|---|---|
| ใครเปิด server | บอร์ด (พอร์ต 7333) Mac เป็นฝ่ายต่อเข้า — Mac ย้ายที่/เปลี่ยน IP บ่อยกว่าบอร์ดที่นั่งอยู่บนโต๊ะ |
| หาบอร์ดยังไง | ที่อยู่ที่ผู้ใช้กรอกเอง → mDNS `_perch._tcp` → IP ล่าสุดที่บอร์ดรายงานมาทาง BLE · สามชั้นเพราะ mDNS เป็นสิ่งแรกที่หายเมื่อมี VLAN แขกหรือเราเตอร์กรอง multicast |
| รูปเฟรม | `[4B len BE][12B nonce][ciphertext][16B tag]` AES-256-GCM · nonce = ศูนย์ 4 ไบต์ + ตัวนับ 8 ไบต์ BE |
| ทำไมต้องเข้ารหัสบน LAN ตัวเอง | WPA2 ปิดแค่ช่วงอากาศ ทุกเครื่องบนเราเตอร์เดียวกันอ่านและ**เขียน**ได้ · snapshot มีชื่อโปรเจกต์กับชื่อไฟล์อยู่ข้างใน และช่องที่เขียนอะไรลงจอบนโต๊ะได้โดยไม่ต้องพิสูจน์ตัวคือช่องที่ไม่ควรมี |
| กุญแจมาจากไหน | Mac สุ่ม 32 ไบต์เก็บที่ `~/.perch/lan-key` (mode 600) แล้วผลักไปบอร์ดทาง config characteristic ที่บังคับเข้ารหัสอยู่แล้ว — ที่เดียวกับรหัส WiFi · ไม่ให้ผู้ใช้ตั้งเอง เพราะรหัสที่คนตั้งเองสั้นพอให้เดาได้ทุกครั้ง |
| รู้ได้ไงว่ากุญแจตรงกัน | บอร์ดส่งลายนิ้วมือ (8 hex แรกของ SHA-256) มากับสถานะ WiFi · ไม่ตรงเมื่อไร Mac ผลักของใหม่ไปเองทันที ผู้ใช้ไม่มีทางรู้ว่าตัวเลขสองชุดนี้ต่างกันอยู่ |
| กันเล่นซ้ำ | ตัวนับใน nonce ต้องมากกว่าตัวที่รับไปแล้วเสมอ · **บอร์ดบอกเลขนั้นให้ Mac ตอนรับสาย** (คำทักทาย 13 ไบต์) Mac จึงไม่ต้องเก็บไฟล์ตัวนับเอง — ไฟล์แบบนั้นหายเมื่อไรก็แปลว่าต่อไม่ได้อีกจนกว่าจะเปลี่ยนกุญแจ ซึ่งเป็นความพังที่ไม่มีอาการให้เห็น · คำทักทายไม่ได้ถูกยืนยันตัว แต่การโกหกมันทำได้แค่ดันตัวนับให้สูงขึ้น ไม่เปิดทางให้เฟรมเก่าผ่าน |
| จด NVS ทุกกี่เฟรม | ทุก 256 (`FLOOR_STRIDE`) ไม่ใช่ทุกเฟรม — snapshot เดินทางทุกไม่กี่วินาที การเขียน flash ทุกครั้งกินอายุเซกเตอร์หมดในไม่กี่เดือน ราคาคือหลังไฟดับตัวนับกระโดดไปข้างหน้าไม่เกิน 256 |
| เฟรมยืนยันตัวไม่ผ่าน | ตัดสาย ไม่ใช่ข้ามเฟรมนั้น — ความยาวที่อ่านผิดไปหนึ่งไบต์ทำให้ทุกเฟรมหลังจากนั้นเพี้ยนหมด และ Mac ต่อกลับเองพร้อมรับคำทักทายใหม่ ตัวนับจึงซิงก์ตัวเองโดยไม่มีใครต้องทำอะไร |
| เพดานขนาด | คง 500 ไบต์เท่า BLE — สายเส้นเดียวสองทางเดินที่บีบข้อความคนละเกณฑ์แปลว่าจอแสดงคนละอย่างขึ้นกับว่าตอนนั้นเดินทางไหน |
| ทิศทาง | ทางเดียว (Mac → บอร์ด) ยกเว้นคำทักทาย · ผลสแกน WiFi กับสถานะยังเดินทางบน BLE เท่านั้น เพราะมันมีความหมายก็ต่อเมื่อผู้ใช้กางหน้าตั้งค่าอยู่ ซึ่งเป็นตอนที่ BLE ต้องติดอยู่แล้ว |
| จอบอกอะไร | เหลือแต่ WiFi = ป้ายบนแถบเปลี่ยนจากชื่อบอร์ดเป็น **IP** — เป็นตอนเดียวที่ผู้ใช้ต้องใช้เลขนั้น (Mac หาไม่เจอ ต้องกรอกเอง) และเป็นตอนที่เขาอ่านจากหน้าจอ Mac ไม่ได้แล้ว |
| Local Network | `NSLocalNetworkUsageDescription` + `NSBonjourServices` ใน Info.plist · macOS 15 ขึ้นไปขออนุญาตแยกจาก Bluetooth และการขาดคีย์ทำให้ทั้ง Bonjour และการต่อไปหา IP ตรงๆ เงียบไปโดยไม่มี error |

## ฮาร์ดแวร์ (วัดจากบอร์ดจริง)

ESP32-D0WD-V3 rev 3.1 · 4MB flash · ไม่มี PSRAM · พอร์ต `/dev/cu.usbserial-*`
MAC 2 ไบต์ท้ายคือชื่อที่บอร์ดใช้โฆษณาบน BLE

ผลตรวจจอด้วย `firmware/probe/`:

```
MADCTL          0x28   = MV | BGR   -> แนวนอน 320x240 origin มุมบนซ้าย
ลำดับสี         BGR    ไม่ใช่ RGB
Inversion       ปิด    (INVOFF)
COLMOD          0x55   16 bit/pixel
```

```
TFT (SPI2):   MOSI 13  MISO 12  SCLK 14  CS 15  DC 2  RST -1  BL 21   [ยืนยันแล้ว]
RGB LED:      R 4   G 16   B 17          (active low)                  [ยืนยันแล้ว]
Touch XPT2046 (SPI3):     CLK 25  MOSI 32  MISO 39  CS 33  IRQ 36     [ยืนยันแล้ว]
microSD:      CS 5  MOSI 23  MISO 19  SCK 18                          [ไม่ใช้]
Speaker:      GPIO 26 (DAC1)                                          [v2]
```

RAM ที่เหลือจริงตอนทำงาน (BLE + WiFi + LAN + mDNS + LVGL ขึ้นครบ อยู่บนทาง LAN สิบนาที):

```
idf.py size      DRAM static เหลือ 24060 · IRAM เหลือ 22105
esp_get_free_heap_size()          ~30 KB
esp_get_minimum_free_heap_size()  ~23 KB   <- ก้นจริง ถึงตอนนาทีที่ 3 แล้วไม่ลงอีก
```

**กรอบที่ต้องคิดคือ 23KB ไม่ใช่ 61KB ที่ `heap_init` โฆษณาตอนบูต** — WiFi กับ LAN จอง
หลังบรรทัดนั้น ตัวเลขตอนบูตจึงมองโลกในแง่ดีเกินจริงเกือบสามเท่า ของที่จองก้อนโตกว่านี้
ต้องวัดใหม่ ไม่ใช่เดาจาก `idf.py size` อย่างเดียว · `main.c` จึงพ่น `heap`/`min` นาทีละ
บรรทัดไว้ถาวร: ที่รั่วช้าๆ ไม่มีอาการอะไรเลยจนกว่าจะจองไม่ผ่านแล้วบอร์ดรีบูตทิ้ง

**เลขรุ่นชิปพิสูจน์ไม่ได้ และไม่จำเป็นต้องพิสูจน์** — จอล็อกการอ่าน ID (`0x04`, `0xD3`,
`0xDA/DB/DC` คืนศูนย์) มีแต่ `0x0A` ที่ตอบ `0x98` ซึ่งเหมือนกันทั้ง ILI9341 และ ST7789
พฤติกรรมชี้ไป ILI9341 (inversion ต้องปิด ส่วน ST7789 เกือบทั้งหมดต้องเปิด)
**firmware ใช้ค่าคอนฟิกด้านบน ไม่ใช่เลขรุ่น**

## การแตะจอ

รู้แค่ "มีนิ้วไหม" ไม่รู้ว่าแตะตรงไหน — และนั่นเป็นการตัดสินใจ ไม่ใช่ข้อจำกัด

พิกัดไม่ได้ตอบคำถามที่บอร์ดนี้ถามเพิ่มเลย แต่พาการคาลิเบรต ปุ่มบนจอ 2.8 นิ้ว และ
โอกาสชนกับ SPI ของจอเข้ามาทั้งชุด ส่วน "มีคนอยู่ตรงหน้าไหม" ตอบได้ด้วยขาเดียว

**แตะหนึ่งครั้งได้สองอย่างพร้อมกัน** ซึ่งเป็นสองสิ่งที่คนเดินมาถึงโต๊ะอยากได้พร้อมกันพอดี:

1. **ปลุกไฟหลัง** — สว่างทันทีไม่ไล่ขึ้น (คนที่เพิ่งแตะกำลังรอดู)
2. **เรียกดูแผงโควตา 8 วินาที** — ปกติแผงนี้โผล่เฉพาะตอนไม่มีการ์ดค้าง ซึ่งเป็นจังหวะ
   ที่ผู้ใช้เลือกไม่ได้ อยากรู้ว่าเหลือโควตาเท่าไรตอนไหนก็ต้องรอให้การ์ดหมดไปเอง

### กับดักที่เสียเวลาไปกับมัน

**XPT2046 ไม่ปล่อยสัญญาณ PENIRQ มาตั้งแต่เปิดเครื่อง** มันปล่อยเมื่ออยู่ในโหมด
power-down ที่เปิด PENIRQ ซึ่งเกิดหลังจบการแปลงค่าที่สั่งด้วย `PD1=PD0=0` เท่านั้น
ถ้าไม่เคยส่งคำสั่งอะไรเลย ขาจะค้างสูงตลอดกาลและการแตะเงียบสนิท (วัดได้ `low=0/50`
ทุกรอบไม่ว่าจะแตะหรือไม่) จึงต้องส่ง `0x90` ครั้งเดียวตอนบูตเพื่อปลุกชิป —
เป็นเหตุผลเดียวที่โมดูลนี้ต้องแตะ SPI เลย หลังจากนั้นอ่านแต่ขา GPIO

**GPIO 36 ไม่มี pull-up ในชิป** (ขา 34-39 ของ ESP32 ไม่มีทั้ง pull-up และ pull-down)
ต้องพึ่งตัวบนบอร์ด มีตัวตรวจตอนบูตที่ร้องออกมาถ้าขาลอย

### จอไม่หรี่จนกว่าจะแตะติดสักครั้ง

อย่าดับสิ่งที่ตัวเองเปิดคืนไม่ได้ บอร์ดที่ pull-up หายหรือคนละล็อตที่ไม่มีตัวควบคุมสัมผัส
จะได้จอที่หรี่แล้วสว่างกลับไม่ได้ ซึ่งแยกไม่ออกจากเครื่องพัง การรอให้เห็นการแตะจริง
ก่อนคือการพิสูจน์ว่ามีทางกลับ

## ตัดสินใจเชิงเทคนิค

- **NimBLE** ไม่ใช่ Bluedroid — เล็กกว่า และต้องการแค่ BLE peripheral
- **ไม่มี OTA ใน v1** — partition เป็น factory app ก้อนเดียว + NVS ได้ app เต็ม ~3.5MB
  จาก 4MB (มี OTA จะเหลือ slot ละ ~1.7MB) แฟลชผ่าน USB อยู่แล้วตอนพัฒนา
- **LVGL partial buffer** 2 ก้อน ก้อนละ 1/10 จอ (~15KB) ไม่ใช่ full framebuffer 150KB
- **daemon truncate ทุก string** ก่อนส่ง ให้ snapshot พอดี 1 MTU — ไม่มี chunking
- **ฟอนต์บนบอร์ดไม่มี em dash และไม่มีอักขระไทย** — daemon ต้องกรองข้อความให้เหลือ
  เฉพาะชุดอักขระที่ฟอนต์มีจริงก่อนส่ง (`Text.swift`) ไม่งั้นได้กล่องสี่เหลี่ยม

## ภาพบนจอ

หลักที่ใช้ตัดสินทุกข้อ: เรนเดอร์จอ 320x240 จริงแล้วดู ไม่ตัดสินจากการคิดเอา

**สัดส่วน**

- **สัดส่วนตัวมาสคอตมาจากตาราง 12 x 8 ช่องของภาพอ้างอิงตรงๆ** ช่องละ 1.5 unit
  (ลำตัว 8x8 · แขนข้างละ 2x2 · ตา 1x1 · ขากว้าง 1 สูง 2 ที่ช่อง 0/2/5/7) — เดิมเป็นตัวเลข
  ที่ปรับทีละส่วนจนลำตัวกว้างเกินสัดส่วน (82% ของซิลลูเอ็ต แทนที่จะเป็น 67%) และแขนสั้นเกินครึ่ง
  ทุกค่าจึงต้องมาจาก `CELL` ไม่ใช่ตัวเลขดิบ ไม่งั้นความเพี้ยนกลับมาสะสมอีก
  · **ข้อเดียวที่จงใจเบี่ยงคือแขน: 1.5 ช่อง ไม่ใช่ 2** — ที่ 4 px/unit แขนเต็มสองช่องยื่นออก
  12 px ต่อข้าง อ่านเป็นแขนยาวเก้งก้าง ไม่ใช่ตอแขนแบบต้นฉบับ (ต้นฉบับถูกดูที่ขนาดใหญ่กว่านี้มาก)
- ซิลลูเอ็ต 16.5 unit + พื้นที่ prop ถึง 23.4 unit ที่ `unit_px = 4` = 95.6px ใน slot 106px
  prop ที่ล้นเกินนี้จะไปตกบนพื้นหลัง slot ถัดไปแล้วอ่านเป็นของตัวข้างๆ · ที่โตได้แค่นี้เพราะ
  **แนวนอนคือด้านที่ตัน ไม่ใช่แนวตั้ง** — ช่อง prop ที่ถือกิน 6.2 unit ตายตัว โตกว่านี้ต้องแลกกับมัน
- **3 slot ไม่ใช่ 4** — 4 ตัวบนจอ 320px แปลว่าตัวละไม่เกิน 80px ซึ่งเล็กเกินกว่าจะดูออก
  จากอีกฝั่งโต๊ะ ทั้งที่ session ที่ 4 ถูกนับ "+N" ให้อยู่แล้ว · `unit_px = 4` คือค่าสูงสุด
  ที่ยังวาง 3 ตัวเรียงได้ และ outline 0.34 unit ยังปัดเป็น 1px
- **slot ยกทั้งกลุ่มไว้กึ่งกลาง** ระยะห่างคงที่ 80px ไม่ยืดหดตามจำนวน
  สิ่งที่ต้องนิ่งคือ **ลำดับซ้าย→ขวา** ไม่ใช่พิกัดสัมบูรณ์ การจัดกลุ่มกึ่งกลางไม่เคยสลับลำดับ
- **ไม่มีเส้นคั่น slot และไม่สลับสีพื้นหลัง slot** — เส้นตั้งเต็มความสูงอ่านเป็นเสาและตัดฉาก
  ผืนเดียวเป็นสามชิ้น ส่วนพื้นหลังสลับสีทำให้ prop อ่านเป็นของ slot ข้างๆ
  หน้าที่กันความสับสนตกเป็นของ **เงาใต้เท้า** ซึ่งบอกว่าแต่ละตัวยืนตรงไหน
- **เส้นขอบฟ้าอยู่กลางจอพอดี (y=120)** — ฟ้าสูง 98px เหนือกรอบวาดมาสคอตโล่ง 28px
  คือทางที่ดวงอาทิตย์เดินโดยไม่โดนบัง (`arc_peak` 82)

**มาสคอต**

- **แยก mood (ตา/ลำตัว) ออกจาก prop (ของที่ถือ) เป็นคนละมิติ** — นี่คือสิ่งที่ทำให้
  11 สถานะแยกออกจากกันได้ทั้งหมดโดยไม่ต้องวาดทีละท่า
- `waiting` = นาฬิกาเหลือง · `alert` = "!" แดง — คนละความหมาย ("รอคุณตอบ" ≠ "พัง")
  ต้องต่างทั้งรูปทรงและสี · `celebrate` ตาเป็น `^ ^` ไม่ใช่ขีดแบน (ซ้ำตาหลับของ `sleeping`)
- **กะพริบตาเดินด้วยนาฬิกาที่ช้ากว่าลูปอนิเมชัน** (`cycle` แยกจาก `phase`) 1 เฟรมทุก 4 ลูป
  ≈ 4.3 วิ — กะพริบทุกวินาทีอ่านเป็นกระวนกระวาย
- **ทุกชิ้นตั้งฉาก** — เส้นทแยงบางๆ ที่ความละเอียดนี้เละเป็นขั้นบันได
- **แว่นขยาย: กระจกกับวงแหวนต้องผ่านทรานส์ฟอร์มชุดเดียวกัน** — กระจกวาดก่อนตา ส่วนวงแหวน
  วาดหลังตา จึงอยู่คนละท่อนของ `build()` แต่มันคือของชิ้นเดียวกัน · กระจกเคยถูก `_squashed()`
  ตามลำตัวขณะที่วงแหวน (เป็น prop) ไม่ถูกยุบ ท่าที่ squash > 0 จึงดันกระจกลง ~1.5px
  แล้วเห็นเนื้อลำตัวโผล่ใต้ขอบบนของวง · **ขนาดเลนส์กับความหนาขอบต้องลงตารางพิกเซลทั้งคู่
  รวมถึงมุมที่ตัด `s/4` และ `s/4 - t`** ไม่งั้นบันไดมุมของสองชิ้นเหลื่อมกันเป็นร่อง
- **ลูกโลก (`searching`) อยู่บนหัว 6.5 unit และลอยนิ่งไม่เด้งตามลำตัว** — ของที่ถือข้างตัว
  อ่านเป็นของที่วางอยู่ข้างๆ ไม่ใช่สิ่งที่มาสคอตกำลังทำ · ตัวเด้งผ่านลูกที่ลอยนิ่งจึงอ่านเป็น
  ลูกโลกลอยจริง · ทรงกลมประกอบจากแถบแนวนอน 13 แถบ (0.5 unit) กว้างตามสมการวงกลม
  **วัดที่กึ่งกลางแถบ ไม่ใช่ขอบ** (วัดที่ขอบได้โดมแบน) · ฟ้า/เขียวคือรหัสสีที่ไม่ต้องอธิบาย
  · ทวีปที่ล้นขอบเล็มเฉพาะส่วนที่ล้น ไม่ซ่อนทั้งก้อน (ก้อนที่หายวับอ่านเป็นกะพริบ)
  · **ลูกมีขอบสี `steel` หนา 2 px** — น้ำสี `glass` (#A8D8EA) กับฟ้ากลางวัน (#B8DCF5)
  ห่างกันไม่ถึงหนึ่งสเต็ป ลูกโลกจึงกลืนหายไปทั้งลูกตอนกลางวัน · แก้ด้วยการเปลี่ยนสีน้ำไม่ได้
  เพราะฟ้ามีสี่ช่วงตั้งแต่ #0B0F1A ถึง #B8DCF5 ไม่มีสีเดียวที่ตัดกับทั้งสี่ · ขอบเข้มกับไส้สว่าง
  ตัดกันคนละทาง อย่างน้อยหนึ่งอย่างจึงเห็นเสมอ (ไส้ได้ 12.5:1 กับกลางคืน ขอบได้ 3.4:1 กับ
  กลางวัน) — **prop ทุกชิ้นที่ลอยอยู่บนฟ้าต้องมีคู่เข้ม/สว่างแบบนี้ ไม่ใช่สีเดียว** · ขอบเป็น
  `steel` ไม่ใช่ `ink`: สีหมึกบนลูกฟ้าอ่อนอ่านเป็นเส้นขีดดำ ไม่ใช่ขอบของทรงกลม และขอบ 1 px
  ขาดๆ หายๆ ตามขั้นบันไดของแถบ ต้อง 2 px = ความสูงของแถบพอดี ขอบจึงหนาเท่ากันทุกด้าน
- **`conducting` (prop `crew`, priority 22)** — subagent ยิง hook ด้วย `session_id` เดียวกับพ่อ
  สล็อตพ่อจึงกระพริบเป็นงานที่ไม่ใช่ของมัน · `subagents > 0` ชนะ tool ทั้งหมด แต่แพ้
  `error`/`waiting` · **priority ต้อง > tool (20)** เพราะ session ที่คุม subagent เงียบสนิท
  ถ้าเท่ากันจะแพ้ tie-break ที่ `lastActivity` แล้วหลุดจอ · ตัวนับต้องรีเซ็ตที่
  `Stop`/`SessionStart`/`SessionEnd`/`UserPromptSubmit` — `SubagentStop` ที่หายไปตอน
  daemon ไม่ได้รันจะทำให้ท่าค้างตลอดกาล · prop เป็นมาสคอตจิ๋วสองตัว ไม่ใช่ไม้กำกับวง
  (สารคือ "มีหลายตัวทำงานอยู่" ไม่ใช่อุปมา)
- **`beacon` (priority 20)** — `LSP` และ `mcp__*` ไม่ได้อ่านดิสก์และไม่ได้ค้นเว็บ
  แต่กำลัง **รอบริการอื่นตอบ** ซึ่งค้างนานที่สุด · เสาอากาศ **บนหัว** (สัญญาณต้องออกจาก
  ตัวมาสคอตเอง) · คลื่นแผ่ออก **ด้านข้าง** ไม่ซ้อนขึ้นบน — เหนือหัวมีที่แค่ 5.6 unit
  แนวนอนมีเหลือเฟือ · ยิ่งไกลสันยิ่งสูง จึงอ่านเป็นวงที่กว้างขึ้น ไม่ใช่ขีดสามขีดยาวเท่ากัน
  · ชั้นโผล่สะสม 1→2→3 แล้ววนใหม่ ชั้นที่ยังไม่ถึงคิวไม่วาดเลย · สีเหลืองสีเดียวทั้งชุด
  (หลายสีอ่านเป็นของหลายชิ้น) · ไฟยอดเสาไม่กะพริบ (จังหวะอยู่ที่คลื่นแล้ว)
  · ยกมือค้างสองข้างเป็นสองท่อน (`arm_up` + `arm_out`) — nub ที่เลื่อนขึ้นเฉยๆ
  อ่านเป็น "ไหล่สูง" และการโยกอ่านเป็นโบกมือ
- **`entering`/`leaving` ใช้ `phase` เป็นความคืบหน้า 0→1 ไม่ใช่ลูปวน**
- **ไม่มี session = มาสคอตเดินเล่น** — เดินจากนอกจอซ้ายไปขวา 34 px/วิ แล้ววนใหม่
  หยุดทำท่า 2.5 วิ กลางทาง วนสี่ท่า (celebrate/thinking/searching/waiting)
  ตำแหน่งหยุดวนสามค่า (0.34/0.5/0.66) — จำนวนไม่เท่ากันจึงไม่จับคู่ซ้ำ ·
  คำนวณจาก `cycle + phase` ที่เดินอยู่แล้ว ไม่ต้องมี state เพิ่ม และไม่ต้องพึ่ง BLE

**ฉากและสี**

- **ฟ้ากลางวันต้องข้ามความสว่างของมาสคอตไปให้พ้น** — มาสคอตอยู่ที่ luminance 0.27
  กราฟ contrast มีก้นบึ้งตรงนั้น (`#7FB4D9` = 0.43 ได้แค่ 1.5:1) `#B8DCF5` (0.67) ได้ 2.2:1
  และทำให้เมฆต้องเป็นสีขาว
- **dawn กับ dusk อยู่คนละวงศ์สี** — เช้า = น้ำเงินคราม · เย็น = แดงอมม่วง
  ทั้งคู่ยาวช่วงละ 2 ชม. และไม่มีวันปรากฏพร้อมกัน ตัวแยกจึงต้องเป็นสีล้วนๆ
  ไม่ใช่ความสว่างที่ต่างกัน · เมฆแยกสีตามด้วย ไม่ใช้สีร่วม
- **ดวงอาทิตย์ขึ้น/ตกที่ขอบจอพอดี (`arc_pad = 0`)** — ให้โผล่พ้นขอบแล้วดวงหายไปนอกจอ
  ตลอด 05:00–05:55 และ 18:05–19:00 ซึ่งเป็นช่วงเดียวที่ต้องเห็นดวงติดขอบฟ้า
- **พื้นดินเข้มทุกช่วง (luminance ~0.04) สีเขียวไปอยู่ที่กอหญ้า** — พื้นดินกินถึงก้นจอ
  ซึ่งมีเลข % และนาฬิกาใหญ่วางทับ ถ้าพื้นเป็นเขียวหญ้าตัวเลขจะจม · กอสูงไม่เท่ากัน
  (วน 3..6 px) กอสูงเท่ากันหมดอ่านเป็นรั้ว · ก้านหนา 2px เว้น 1px — ก้าน 1px หายไปเลย
  บนแผงจริงทั้งที่เห็นชัดบน preview ที่ขยาย 3 เท่า
- **เงาใต้เท้าขนาดคงที่ ไม่ยุบตามความสูง** — เงาที่ยุบตามกลายเป็นสิ่งที่ต้องมอง แทนที่จะ
  ทำให้มองตัวละครถูก · เกาะกึ่งกลาง *ลำตัว* ไม่ใช่กึ่งกลาง slot (`build_centered`
  จัดกึ่งกลางกรอบที่รวม prop) · แยกสีตามช่วงเวลา — ค่าที่เข้มพอสำหรับกลางคืน
  กลายเป็นรูดำบนพื้นกลางวัน

**พื้นที่ล่าง**

- **นาฬิกาใหญ่กลางจอตอนไม่มีการเตือน** — นี่คือสภาพที่จอเป็นอยู่เกือบตลอดเวลา
  ปล่อยว่างแล้วอ่านเหมือนอุปกรณ์พัง
- **สีการ์ดแยกตาม "ต้องมือคนไหม" ไม่ใช่ "มีอะไรเกิดขึ้นไหม"** — `Notification` กับ
  `StopFailure` เป็น `.alert` (แดง) เพราะไม่มีคนแล้วเดินต่อไม่ได้จริง · แต่ `Stop`
  ที่เงียบครบ 45 วิ เป็น `.done` (`"your turn"`) เพราะเทิร์นจบเฉยๆ ไม่มีอะไรค้างให้ตอบ
  ตอนแรกใบนี้เป็น `.alert` เหมือนกัน ผลคือทุกเทิร์นที่ลุกจากโต๊ะได้การ์ดแดง จนแดงเลิกแปลว่า
  "ต้องมือคน" · ท่ามาสคอตยังเป็น `waiting` ทั้งสองทาง — "ถึงตาคุณ" กับ "ต้องตอบเดี๋ยวนี้"
  ต่างกันที่ความเร่ง ไม่ใช่ว่าใครถือลูกอยู่
- **การ์ด 2 ใบ + `m` (จำนวนที่เกิน)** — ใบที่ 3 ดันแผงล่างชนป้ายชื่อโปรเจกต์
  แต่การตัดทิ้งเงียบๆ ทำให้ "ไม่มีอะไรค้างแล้ว" กับ "ยังค้างแต่จอไม่พอ" หน้าตาเหมือนกัน
  · `m` นับรวมใบที่ `Snapshot.encoded` ตัดเพราะ MTU ล้นด้วย — เหตุผลที่การ์ดหายไป
  ไม่สำคัญกับคนอ่านจอ
- **แถบโควตาสองชั้น** (เลข % + เวลารีเซ็ตบรรทัดเดียวกัน แล้วแถบ) = 40px ต่อแถว
  เลข % ยังฟอนต์ 24 ซึ่งเป็นเหตุผลเดียวที่แถวนี้มีอยู่ · แผงที่เตี้ยกว่าพื้นที่จัดกลางแนวตั้ง
  ไม่ชิดบน — ก้นจอที่โล่งเป็นแถบอ่านเป็น "ของหาย" ไม่ใช่การตัดสินใจ
- **มีการ์ด = โควตาย่อขึ้นแถบบน** — แถบ 34x6px + `52%` เฉพาะหน้าต่าง 5 ชม.
  **ไม่มีป้าย `5h`** (บนแถบมีค่าเดียว) countdown ตัดทิ้ง — ตอนมีการ์ดสิ่งที่ต้องทำคือจัดการ
  notification ไม่ใช่วางแผนโควตา · ทั้งชุดหลบตำแหน่งเมื่อ `+N` โผล่

## แผงโควตา

**ที่มาของตัวเลข — สองทาง ไม่ใช่ทางเดียว**

1. **ท่อ statusline** — Claude Code ป้อน JSON เข้า stdin ของคำสั่ง `statusLine` ทุกครั้งที่
   render และมี `rate_limits.five_hour` / `.seven_day` (`used_percentage` 0–100 กับ
   `resets_at` epoch) ไม่ต้องมี credential ไม่ยิงเน็ต ไม่ต้องมี timer
2. **ท่อ poll** — `perch --usage-poll` ยิง `/api/organizations/<org>/usage` ด้วย
   `sessionKey` ตามรอบที่ menu bar ถือไว้

**การกลับคำ** — เอกสารเดิมเขียนว่าท่อ statusline คือ *แหล่งเดียว* และ "ไม่มี sessionKey
ไม่ยิงเน็ต" ซึ่งไม่จริงอีกต่อไป เหตุผลเดิมยังถูก แต่เราเจอสิ่งที่มันทำไม่ได้: statusline เป็น
**event-driven ล้วน** จึงเงียบตอน session ว่าง ซึ่งคือสภาพที่จอบนโต๊ะเจอเกือบตลอดเวลา
ปิด Claude Code ทิ้งไว้แล้วตัวเลขค้าง — และค้างแบบที่แยกไม่ออกจากค่าที่ยังถูก
ทางแก้เดียวคือถามต้นทางเอง ซึ่งต้องมี credential
ท่อ statusline ยังอยู่เพราะไม่มีอะไรให้หมดอายุ: ผู้ใช้ที่ไม่เคยตั้ง key ก็ยังเห็นตัวเลข
และวันที่ key หมดอายุ ค่าที่ Claude Code ป้อนเข้ามายังถูกต้อง **สองอันทำคนละหน้าที่
และเป็นสวิตช์คนละตัว** — ตั้ง key สำเร็จแล้วไม่ auto-uninstall statusline
(การถอนอัตโนมัติคือการแตะ `settings.json` ของผู้ใช้โดยไม่ได้สั่ง)

**"ไม่แตะ Keychain" ยังไม่กลับคำ** — สิทธิ์เข้าถึงรายการใน Keychain ผูกกับลายเซ็นแอป
และแอปนี้เซ็น adhoc: บิลด์ใหม่ = cdhash ใหม่ = Keychain เด้งถามรหัสเครื่องทุกครั้งที่อัปเดต
แลกกับความปลอดภัยที่มากกว่าไฟล์ 600 เฉพาะกรณีที่ผู้บุกรุกอ่านไฟล์ในบ้านผู้ใช้ได้แต่รันโค้ด
ในนามผู้ใช้ไม่ได้ ซึ่งแคบมาก · ถ้าวันหนึ่งมี Developer ID จริง ข้อนี้ควรกลับคำเป็นอันดับแรก

ข้อจำกัดของท่อ statusline: `rate_limits` มีเฉพาะบัญชี Pro/Max และเฉพาะหลัง API response
แรกของ session · แต่ละหน้าต่างหายไปอิสระต่อกันได้

**ทางเดินของข้อมูล**
```
Claude Code --stdin--> ~/.perch/statusline.sh --.
                                   |                  \
                          (ส่งต่อให้ statusline เดิม)   >--> ~/.claude/.statusline-usage-cache
                                                      /                  |
claude.ai /api/.../usage --payload--> UsageWriter ---'        daemon อ่าน --> "u" --> บอร์ด
```

**กฎของ cache**

- **ไม่รู้ ≠ ศูนย์** (ADR-0001 ของ `esp32-claude-quota`) — `-1` คือไม่รู้ `0` เป็นค่าจริง
  ไม่เคยมีข้อมูลเลย → ซ่อนแผงทั้งอันกลับไปเป็นนาฬิกา (โครงเปล่าดูเหมือนอุปกรณ์พัง)
  มีทีละตัว → แถวที่ขาดเป็น `--` · countdown ถึง 0 → เปอร์เซ็นต์เป็น `--` ทันที
- **ห้ามเขียนค่าที่เก่ากว่าทับ** — invariant: **ภายในหน้าต่างเดียวกัน (`resets_at` ตรงกัน)
  เปอร์เซ็นต์เพิ่มอย่างเดียว** ค่าที่ต่ำกว่าจึงเก่ากว่าเสมอ พอหน้าต่างหมุน `resets_at` เปลี่ยน
  ค่าที่ลดลงกลายเป็นค่าที่ถูก · คีย์ของเจ้าของร่วม (`PROFILE_NAME`, `COST_*`) ต้องรอด
- **ไม่มี TTL** — เปอร์เซ็นต์ขยับได้ก็ต่อเมื่อผู้ใช้เรียก Claude ค่าเก่าจึง *คือ* ค่าที่ถูก
  สิ่งเดียวที่ทำให้หมดอายุคือ `resets_at` ที่ผ่านไปแล้ว
- **ลิงก์หลุด = พื้นที่ล่างว่างทั้งแถบ ทั้งการ์ดและโควตาหาย เหลือนาฬิกา**
  (`shown_card_count()` / `usage_shown()` ใน `pch_ui.c` ↔ `Screen.shown_cards()` /
  `.shown_usage()` ใน `gen/screen.py`) **การกลับคำ** — เดิมทั้งคู่ยังอยู่ โดยอ้างว่า
  countdown เดินด้วยนาฬิกาบอร์ดเองจึงยังจริง แต่นั่นตอบแค่ครึ่งเดียว: countdown จริงก็จริง
  ส่วน*เปอร์เซ็นต์*ซึ่งเป็นตัวเลขที่คนอ่านมาจาก host และไม่มีใครยืนยันแล้วว่ายังจริง —
  ผู้ใช้อาจสั่งงาน Claude จากเครื่องอื่น หรือแอปฝั่ง Mac ตายไปนานแล้ว "ไม่ขยับ" กับ
  "ขยับแต่บอร์ดไม่รู้" แยกกันไม่ออกบนจอ · ตอนหลุด สิ่งเดียวที่จอยืนยันได้คือเวลาที่ค้างอยู่
  (ซึ่งหรี่เป็นเทาเพื่อบอกว่าเป็นเวลาล่าสุดที่รู้ ไม่ใช่ตอนนี้) จอจึงเทาทั้งใบตามที่ README โฆษณา
  ไม่ใช่เทาครึ่งใบโดยมีตัวเลขสีสดที่เชื่อไม่ได้ค้างอยู่ท่อนล่าง
- **ทางเข้าที่สอง ไม่ใช่ตัวเขียน cache ตัวที่สอง** — payload จาก API (รูปแบบดูที่
  `docs/claude-usage-api.md`) เข้าทาง `UsageWriter.ingestAPI` ซึ่งอยู่ใน enum เดียวกับ
  ทางเข้าของ statusline และจบที่ `merge`/`write` ชุดเดียวกัน กฎ "เพิ่มอย่างเดียว"
  ต้องมีเจ้าของคนเดียว · กับดักที่เทสต์ปักไว้: `utilization` เป็น float แต่ `percent` เป็น int
  จึง **ปัด** ทั้งคู่ ไม่ตัดทิ้ง (16.6 ไม่งั้นได้ 16 ทางหนึ่ง 17 อีกทางหนึ่ง) · เวลาต้องผ่าน
  formatter ตัวเดิมก่อนเขียนเสมอ เพราะ `…:00Z` กับ `…:00.482Z` คือหน้าต่างเดียวกัน
  แต่คนละสตริง แล้ว merge จะนึกว่าหน้าต่างหมุน · เปอร์เซ็นต์ที่ไม่มี `resets_at` ที่อ่านออก
  ถูกทิ้งทั้งบาน · `weekly_scoped` เป็น limit ราย model ไม่ใช่ของทั้งบัญชี
- **เขียนไฟล์เดียวกับ Claude Usage.app** คีย์ชุดเดิม เวลา ISO8601 — สคริปต์ statusline
  ที่ผู้ใช้จูนไว้อ่านต่อได้ · เขียนแบบ temp + rename ไม่มีใครอ่านเจอไฟล์ครึ่งๆ
- **ยึดช่อง `statusLine.command` แต่ไม่เปลี่ยนสิ่งที่ผู้ใช้เห็น** — สคริปต์เขียน cache แล้วส่ง
  JSON ก้อนเดิมต่อให้คำสั่งเดิมแล้วพิมพ์ผลออกไป · ทุกทางจบด้วย `exit 0` · ติดตั้งซ้ำต้อง
  กู้คำสั่งเดิมจาก `PREV=` ในตัวสคริปต์ ไม่งั้นการอัปเกรด = ลบ statusline ของเขาทิ้งเงียบๆ
  · `refreshInterval: 10`
- **ไม่มีคำสั่งเดิมให้ส่งต่อ = เราวาดเอง และวาดให้เต็ม** (`StatuslineRender`) — เดิมทางนี้พิมพ์
  แค่ `5h 12% · 7d 30%` ซึ่งทำให้คนที่ยังไม่เคยตั้ง statusline รู้สึกว่าการเปิด "Read quota
  from the statusline" คือการแลกช่องไปได้ของที่ด้อยกว่า · ที่ port มาคือ `statusline-command.sh` ของ
  Claude Usage.app **ทั้งใบ** (ไอคอน เกรเดียนต์ 10 ขั้น ขีด pace 6 ขั้น รูปแบบเวลา) เพราะ
  ครึ่งใบแปลว่ามีสองหน้าตาในโลกให้ผู้ใช้เทียบแล้วสงสัย · **อ่าน
  `~/.claude/statusline-config.txt` ไฟล์เดียวกับสคริปต์นั้น** ไม่สร้างไฟล์ตั้งค่าของตัวเอง —
  คนที่ย้ายมาจากสคริปต์นั้นตั้งค่าไว้แล้ว และไฟล์ที่สองแปลว่าต้องตั้งสองที่ให้ตรงกันตลอดไป ·
  เทสต์ปักไว้ว่าทุกชิ้นและทุกโหมดสีต้องได้ผลเท่าสคริปต์ต้นทาง ต่างได้อย่างเดียวคือ escape
  ปิดสีที่โหมดขาวดำของสคริปต์นั้นพ่นทิ้งไว้เปล่าๆ · ตัวเลขที่เก่ากว่า 5 นาทีอ่านว่า `~` ตามเดิม
  (เราไม่มีทางยิงเน็ตแทนตรงนี้ — ไม่ถือ credential) · `git` ถูกเรียกจริงเพื่อหา branch และ
  จำนวนบรรทัด ไม่ใช่อ่าน `cost.total_lines_*` จาก payload: payload นับสิ่งที่ *session นี้* แก้
  แต่บรรทัดสถานะควรบอกว่า *ต้นไม้ทำงาน* ต่างจาก HEAD แค่ไหน · ทุกคำสั่งใส่
  `--no-optional-locks` เพราะมันวิ่งทุก 10 วินาทีระหว่างที่ผู้ใช้กำลังพิมพ์คำสั่ง git อยู่

**ท่อ poll**

- **ตัวยิงเป็นโปรเซสอายุสั้น ไม่ใช่ daemon** — อ่าน key → หา org → ยิง → `ingestAPI` →
  พิมพ์บรรทัดสรุป → `exit` · ไม่ต้องมี supervision ไม่มี backoff ไม่มี crash loop
  ไม่มีลูกกำพร้า และ credential อยู่ใน RAM แค่ช่วงยิง · เหตุผลที่ *ไม่* เอาไปไว้ใน daemon:
  daemon เปิดค้างทั้งวันเพื่อคุย BLE ถ้ามันถือ key ด้วย credential จะอยู่ในโปรเซสที่อายุ
  ยืนที่สุดในเครื่องตลอดเวลา ทั้งที่ใช้จริงวินาทีเดียวต่อนาที และวันที่ key หมดอายุ
  วิธีแก้จะกลายเป็นการรีสตาร์ทตัวที่ต่อบอร์ดอยู่
- **`sessionKey` คือ credential เต็มบัญชี** — ไฟล์ `~/.perch/session-key` mode 600
  เท่านั้น (group/other อ่านได้ = ปฏิเสธพร้อมบอกวิธีแก้) · ไม่เคยผ่าน argv (`ps` เห็น)
  ไม่เคยผ่าน env · **อ่านใหม่ทุกรอบ ไม่ cache** เพราะวิธีแก้ต้องเป็นแค่การ paste ทับไฟล์
  · ห้าม log request/header ทุกกรณี ข้อความ error สร้างจาก status code ล้วนๆ
  · org id ถูก validate (ปฏิเสธ `/` และ `..`) ก่อนต่อเข้า URL เสมอ แม้มาจาก response
  ของเราเอง — ปลายทางเป็นของคนอื่น
- **แอปเป็นคนเขียนไฟล์ key** — ช่องกรอกแบบปิดบัง แล้วสร้าง temp ด้วย 600 แล้ว rename
  ไม่ใช่เขียนก่อน `chmod` ทีหลัง (ช่วงระหว่างสองคำสั่งคือช่วงที่ credential เปิด)
  · ต้องลบไฟล์เดิมก่อน rename เพราะ `replaceItemAt` คัดลอกสิทธิ์ของไฟล์เดิมกลับมา
- **exit code แยกชนิดความล้มเหลว** — `2` key ถูกปฏิเสธ (401/403) · `3` ไฟล์ key ใช้ไม่ได้ ·
  `1` อย่างอื่น (5xx, เน็ตหลุด, timeout) · ล้มเหลวแบบไหนก็ **ไม่ลบไม่แตะ cache เดิม**
- **หยุดยิงเมื่อ key พัง ไม่หยุดเมื่อเน็ตพัง** — exit `2` เป็นอันเดียวที่ *ล็อก* (ยิงต่อก็ได้ 401
  เหมือนเดิมทุกนาที) ตั้ง key ใหม่แล้วปลดล็อกและยิงทันที · exit `3` เป็นแค่ป้ายบอกอาการ
  ตัวที่กันคือการอ่านสภาพไฟล์จริงทุกรอบ ผู้ใช้ที่ `chmod 600` เองข้างนอกจึงกลับมายิงได้
  โดยไม่ต้องเปิดปิดแอป — ล็อกที่ปลดได้ทางเดียวคือกับดัก · เครื่องตื่นจาก sleep ยิงทันที
  หนึ่งรอบ ไม่รอครบรอบถัดไป
- **ตัวจับเวลาอยู่ที่ menu bar ตัวเดียว** — `UsagePoller` ถูกป้อน `tick(now:)` จากนาฬิกา
  วินาทีละครั้งที่มีอยู่แล้ว ไม่มี timer ตัวที่สอง ตรรกะทั้งอันจึงเป็นฟังก์ชันของเวลาที่ส่งเข้ามา
  เทสต์ครบทุกกิ่งได้โดยไม่ต้องรอ · ลูกทีละตัว ลูกที่ไม่จบใน **30 วินาที** ถูกฆ่า (TERM แล้ว
  KILL) · ปิดแอป = ฆ่าลูกก่อนตาย · ลูกที่ถูกฆ่ายังพูดทีหลังได้ จึงมีเลขรุ่นกำกับ
- **รอบสามค่า: `Off` / `60s` (ตั้งต้น) / `5 min`** — หน้าต่าง 5 ชม. ขยับราวหนึ่งเปอร์เซ็นต์
  ต่อสามนาที ถี่กว่า 60 วิ คือการยิงเพิ่มเพื่อได้ค่าเดิม · `Off` เป็นค่าที่ผู้ใช้เลือกได้จริง
  จึงต้องแยกจาก "ยังไม่เคยเลือก" ไม่งั้นแอปที่เพิ่งติดตั้งจะกลายเป็น `Off` เงียบๆ
- **สถานะจากลูกมาทาง stdout ทางเดียว ไม่มีไฟล์สถานะตัวที่สอง** — รวมถึงตอนล้มเหลว
  และรวมถึงรายการ org (บรรทัด `org <id> <ชื่อ>` นำหน้าบรรทัดสรุป) ลูกตายทุกรอบ
  อะไรที่มันรู้จึงต้องพูดตอนยังมีชีวิต · รายการ org ไปกับความล้มเหลวด้วย (`Failure.orgs`)
  ไม่งั้นการพินไว้ที่ org ที่หายไปจะล็อกตัวเอง · id จาก stdout ยัง validate ซ้ำ
- **พินคือพินในลูก การถอยเป็นการตัดสินใจของพ่อ** — `PERCH_ORG_ID` ถูกใช้ตามนั้นเสมอ
  ไม่ถูกแทนเงียบๆ ด้วยตัวแรก · การถอยไปตัวแรกเมื่อตัวที่เลือกหายจากบัญชีอยู่ที่ menu bar
  ซึ่งเห็นรายการทั้งอัน · org เดียว = ซ่อนเมนูทั้งอัน · ติ๊กอ่านจากตัวที่ยิงจริง ไม่ใช่ค่าที่จำไว้

**การเริ่ม session เอง**

**การกลับคำ** — เดิม host *อ่าน* อย่างเดียว: `--usage-poll` ไปหยิบตัวเลขมา และ daemon
ไม่เคยใช้โควตาแทนผู้ใช้เลยสักหน่วย สวิตช์ **Auto-start a session when idle** กลับคำข้อนั้น
เพราะสิ่งที่ผู้ใช้ซื้อไปคืออุปกรณ์ที่บอกสถานะได้ แต่พอไม่มีหน้าต่าง 5 ชม. เปิดอยู่ (เช้าวันใหม่
หรือปล่อยเครื่องทิ้งไว้เกินห้าชั่วโมง) ก็ไม่มีอะไรให้อ่าน — ปลายทางไม่มีตัวเลข ไม่ใช่ท่อพัง
ทางเดียวที่จะมีตัวเลขคือมี session และวิธีเดียวที่ผู้ใช้ทำได้คือเปิดเทอร์มินัลเอง ซึ่งกลับหัว
กลับหางกับเหตุผลที่มีจอนี้อยู่บนโต๊ะ

**ปิดโดยปริยาย** — การอ่านโควตาไม่มีราคา การเปิด session มี แอปที่อัปเกรดแล้วเริ่มคุยกับ
Claude เองเงียบๆ คือการใช้เงินของผู้ใช้โดยไม่ได้ขอ ด้วยเหตุผลเดียวกันนี้ ราคาต่อครั้งถูกกด
ให้ต่ำที่สุด: `-p` one-shot, model ถูกที่สุด (หน้าต่าง 5 ชม. นับรวมทุกโมเดล มีแต่
`weekly_scoped` ที่แยกตามโมเดล) และปิด MCP ทั้งหมด ซึ่งเป็นก้อนที่ใหญ่ที่สุดของค่าเปิด
session · **hooks ไม่ปิด** — เป็นทางเดียวที่ daemon จะรู้ว่ามี session อยู่ และการที่มาสคอต
ขยับคือครึ่งหนึ่งของเหตุผลที่ฟีเจอร์นี้มีอยู่

**รั้วสองชั้น ไม่ใช่ชั้นเดียว** — การเย็นตัวห้านาทีหลังลูกจบ *และ* หนึ่งครั้งต่อหนึ่งหน้าต่าง
อย่างแรกอย่างเดียวยังลองใหม่ชั่วนิรันดร์เมื่อ session เริ่มไม่ขึ้นจริง อย่างหลังอย่างเดียวยังยิงรัว
ได้ในช่วงก่อนที่รอบ poll จะรายงานหน้าต่างใหม่ (นานได้ถึงหนึ่งรอบเต็ม) · "หนึ่งครั้งต่อหน้าต่าง"
เขียนเป็น state machine (ยิงแล้ว → ต้องเคยเห็นหน้าต่าง → หน้าต่างหายไป → ยิงได้อีก)
ไม่ใช่การเทียบ `resets_at` ข้าม seam ซึ่งจะเป็นกฎสำเนาที่สองของ "มีหน้าต่างไหม" —
กฎนั้นมีเจ้าของแล้วคือ `MenuBadge.from(usage) == nil` และตัวยิงรับ `[UsageSnap]?`
ก้อนเดียวกับที่แบดจ์กินด้วยเหตุผลนี้

**ล็อกเฉพาะสิ่งที่คนเท่านั้นที่แก้ได้** — เส้นแบ่งเดียวกับที่ `PollBlock` ใช้กับ session key:
หา `claude` ไม่เจอ กับ ลูกที่จบเพราะยังไม่ได้ login คือสองอย่างที่ยิงอีกกี่รอบก็ได้ผลเดิม
จึงหยุดยิงและขึ้นบรรทัดในท้าย popover ส่วนเน็ตสะดุด/timeout/แยกไม่ออก ไม่หยุดอะไร ·
สิ่งที่แยกสองกลุ่มนี้ออกจากกันคือ*ข้อความ*ที่ลูกพ่นตอนตาย ไม่ใช่ exit code — `claude` ใช้ 1
กับทุกอย่างที่ผิดพลาด รายการ marker จึงต้องแคบไว้ก่อน (marker ที่กว้างเกินเปลี่ยนความ
ล้มเหลวชั่วคราวให้เป็นล็อกถาวรที่ผู้ใช้ต้องมาปลดเอง ส่วนที่แคบไปแค่ยิงซ้ำอีกไม่กี่รอบ) ·
รอบที่ไม่สำเร็จคืนกติกา "หนึ่งครั้งต่อหน้าต่าง" กลับเป็น *ยิงได้* ด้วย เพราะรอบที่ล้มไม่ได้เปิด
หน้าต่างอะไรไว้ให้รอ — การปล่อยให้ค้างคือการให้ความล้มเหลวชั่วคราวหนึ่งครั้งฆ่าฟีเจอร์นี้
ถาวรพอๆ กับล็อก แต่เงียบกว่า · ปิดสวิตช์แล้วเปิดใหม่คือคำสั่ง "แก้แล้ว ลองอีกที" ที่ล้างทั้ง
ล็อก การเย็นตัว และกติกาหนึ่งครั้งต่อหน้าต่าง ไม่ใช่แค่ล็อก (ล็อกที่ปลดแล้วแต่ยังรอหน้าต่าง
ที่จะไม่มีวันมา คือล็อกตัวที่สองที่ปลดไม่ได้)

**`claudePath` ไม่มี UI โดยตั้งใจ** — `defaults write com.perch.daemon claudePath <path>`
*แทนที่* รายการที่ไล่หาทั้งอัน ไม่ใช่ถูกเติมต่อท้าย คนที่ต้องใช้มันคือคนที่ติดตั้งไว้นอกสี่ที่ที่รู้จัก
ซึ่งพบน้อยเกินกว่าจะกินที่ถาวรในเมนูที่คนอื่นทั้งหมดต้องอ่านผ่าน · ด้วยเหตุผลเดียวกัน path
ที่ไล่หามาแล้วอยู่ใน tooltip ของบรรทัดในแผง ไม่ใช่ในตัวบรรทัด

**บนสาย BLE**

- **ส่ง "วินาทีที่เหลือ" ไม่ใช่เวลารีเซ็ต** — `"u":[[35,10800],[48,111600]]` บอร์ดนับถอยเอง
  countdown จึงเดินถูกตอน BLE หลุด และ daemon ไม่ต้องยิงใหม่ทุกนาที · ปัดลงเป็นนาที
  ไม่งั้น snapshot ต่างกันทุกวินาทีแล้วบอร์ดโดนยิงวินาทีละครั้ง
- **ขีด pace มาฟรี** — ความยาวหน้าต่างเป็นค่าคงที่ (18000 / 604800 วิ) บอร์ดหา
  `elapsed = window - remaining` เองได้ · ขีดอยู่ขวาของเนื้อแถบ = ใช้ช้ากว่าเวลา ·
  ซ้าย = เร็วเกินไป — 35% ไม่มีความหมายจนกว่าจะรู้ว่าผ่านไปกี่เปอร์เซ็นต์ของหน้าต่าง

**สีและเกณฑ์**

- **สามขั้นบนจอ**: <60 เขียว · 60–85 เหลือง · >85 แดง · **แซง pace = แดงทันที**
  (`pct > elapsed/window`) เพราะ "60% ตอนเหลือเวลาอีกครึ่ง" เป็นปัญหาคนละแบบกับ
  "60% ตอนหมดเวลาพอดี" — สีบอก *ว่ามีปัญหา* ขีดบอก *ว่าห่างแค่ไหน* ทั้งคู่จึงต้องอยู่
- **ไม่มี card ไม่มี LED จากโควตา** — card จะไปบังแผงโควตาเอง (ย้อนแย้ง) และ LED
  ที่แปลว่า "Claude ต้องการคุณ" อยู่แล้วจะมีสองความหมายจนแยกไม่ออก
- **ป้าย pill สีคงที่ต่อหน้าต่าง** — Current ส้ม (clay) · Weekly เขียว (good)
  สีไม่ตามระดับการใช้: ถ้าทั้งแถวเป็นสีเดียวตอนวิกฤต สีจะหยุดเป็นสัญญาณ ·
  รางใช้ `gray_dark` ไม่ใช่ `bg_slot` ซึ่งกลืนพื้นจอ

## ฝั่ง Mac (Swift)

ตารางไฟล์กับหน้าที่อยู่ใน `CLAUDE.md` — ที่นี่เก็บเฉพาะเหตุผล

**snapshot** — คีย์สั้นเพราะต้องพอดี 500 ไบต์ (MTU 517 หัก header แล้วเผื่อ)
```json
{"c":"14:32","d":"Mon 27 Jul","o":0,
 "s":[{"p":"perch","s":"building"}],
 "n":[{"t":"perch","b":"allow Bash?","k":"alert"}]}
```

**GATT UUID** — firmware ต้องใช้ชุดเดียวกัน
```
service  7A9B0001-4C1E-4B6D-9E2A-1D5C3F0A0001
state    ...0002   daemon เขียน snapshot ลงตัวนี้ (write with response)
config   ...0003   ความสว่าง ฯลฯ
event    ...0004   บอร์ดแจ้งกลับ — สงวนไว้ v2
```

**invariant ของ daemon**

- **เกินโควตาแล้วหด `n`** (body ก่อน แล้ว title แล้วตัดใบล่างทิ้ง) แต่ไม่เคยตัด `s`
  — session คือสิ่งที่จอนี้มีไว้แสดง
- **encode ด้วย `sortedKeys` เสมอ** ไม่งั้นการเทียบว่า "เปลี่ยนไหม" จริงทุกครั้ง
  แล้วบอร์ดโดนยิงทุกวินาที
- **ทุกท่าอยู่บนจออย่างน้อย 5 วิ (`Timings.minPose`)** — Read/Edit จบใน ~100 มิลลิวินาที
  ถ้าเปลี่ยนท่าทันที ท่านั้นสั้นกว่าหนึ่งเฟรมของบอร์ด (tick 1 วิ + ดีเลย์ BLE) ผู้ใช้จะเห็นแต่
  `thinking` · ท่าที่ถูกข้ามหายไปเลย **ไม่เข้าคิว** — คิวทำให้มาสคอตเล่าอดีตช้ากว่าความจริง
  เรื่อยๆ เมื่อเครื่องมือยิงรัว · ข้อยกเว้น: priority สูงกว่า (error/waiting) แทรกได้ทันที
  และ entering/leaving ไม่ถูกหน่วงเพราะมีนาฬิกาของตัวเอง
- **นอนชนะการทวงถาม** — Stop แล้วเงียบเกิน 45 วิ ขึ้น `waiting` แต่ครบ 5 นาทีเปลี่ยนเป็นนอน
  ท่ายืนทวงตลอดกาลไม่สื่ออะไรเพิ่ม · การเตือนยังอยู่ในรูปการ์ดซึ่งเป็นคนละช่องทาง
- **เกิน 3 ตัว: เลือกด้วยความสำคัญ แต่วาดตามลำดับเกิด** — ตัวที่ตกจอคือตัวที่เงียบสุด
  และเก่าสุด ลำดับซ้าย→ขวาของตัวที่เหลือไม่เคยสลับ
- **session หายจากจอเมื่อ process ของมันตาย ไม่ใช่เมื่อ `SessionEnd` มา** — ปิดหน้าต่าง
  terminal ทิ้งคือทางออกที่ผู้ใช้ใช้จริงที่สุด และทางนั้น Claude Code โดน SIGHUP ก่อนได้ยิง
  hook ผลคือ session ผีค้างจอจนครบ `evict` (1 ชม.) แล้วไปกิน slot ของตัวเป็น · `--hook`
  จึงไต่สายบรรพบุรุษของตัวเองหา process ของ Claude Code แล้วแนบมากับทุกเหตุการณ์ ให้
  `prune()` เป็นคนถาม kernel ว่ายังอยู่ไหม (`ProcessTree`) — `evict` เหลือไว้เป็นตาข่ายรอง
  - **ไต่หาไม่เจอ = "ไม่รู้" ไม่ใช่ "ตายแล้ว"** hook ถูกเรียกผ่านเชลล์และผู้ใช้ครอบ wrapper
    อะไรไว้ก็ได้ ถ้าเดาผิดไปคว้า wrapper ที่ตายทันทีหลัง hook จบ session ที่ยังทำงานอยู่จะ
    หายจากจอทุกครั้ง — ผิดทางนี้แก้ไม่ได้ด้วยการรอ ต่างจากการค้างนานเกินไป
  - **ตัวระบุตัวตนคือคู่ (pid, เวลาเกิด)** PID ถูกใช้ซ้ำได้ในไม่กี่นาทีบนเครื่องที่ spawn
    process ถี่ (ซึ่ง Bash tool ทำอยู่ตลอด) เทียบแค่เลขแล้ว session ที่ตายไปจะฟื้นขึ้นจอ
  - **ห้ามระบุ Claude Code ด้วยชื่อ process** ตัวติดตั้งหลักวาง executable ไว้ที่
    `~/.local/share/claude/versions/<version>` ชื่อไบนารีจึงเป็นเลขเวอร์ชันและเปลี่ยนทุก
    การอัปเดต · ที่นิ่งคือคอมโพเนนต์ `claude` ในพาธ และต้องเทียบทั้งคอมโพเนนต์ ไม่ใช่
    `contains` เพราะไบนารีของเราเองอยู่ใน `perch/`
- **hook ต้องคืน 0 เสมอ** แม้ daemon ไม่ทำงาน — hook ที่พังทำให้ session ผู้ใช้พังตาม
  ซึ่งแย่กว่าจอไม่ขยับมาก
- **ไม่ใช้ `testTarget`** — เครื่องที่มีแค่ Command Line Tools จะ build ชุดเทสต์ผ่าน
  แต่ไม่รันมันเลยและยัง exit 0 ซึ่งอันตรายกว่าไม่มีเทสต์

**การแจกจ่ายและสิทธิ์**

- **daemon ต้องรันจาก `.app` bundle จริง** — TCC บน macOS 26 ไม่ยอมรับ `__info_plist`
  ที่ฝังในไบนารี Mach-O เปล่า ผลคือ CoreBluetooth เงียบสนิท (ไม่มี callback ไม่มี error)
  และพอเรียกจาก Terminal ที่มีสิทธิ์ถามได้จริง มันยิง SIGABRT ทิ้งทั้งโปรเซส
  (`__TCC_CRASHING_DUE_TO_PRIVACY_VIOLATION__`)
- **ลายเซ็นเป็น adhoc** — สิทธิ์ TCC ผูกกับ cdhash บิลด์ใหม่ = ถามสิทธิ์ Bluetooth ใหม่
  การแจกให้เครื่องอื่นต้องมี Developer ID + notarization
- **บันเดิลชื่อ `Perch.app` ส่วนไบนารีข้างในยังชื่อ `perch`** — ชื่อบันเดิลคือ
  สิ่งที่ผู้ใช้เห็นใน Finder ส่วนชื่อไบนารีคือสิ่งที่ผู้ใช้พิมพ์ · ที่ห้ามเปลี่ยนตามคือ
  bundle id (`com.perch.daemon`), `~/.perch`, และชื่อ BLE ที่เฟิร์มแวร์ประกาศ
  (`BLETransport.deviceName`) — สองอันหลังเป็นสัญญากับของที่อยู่นอกแอป
- **การเปลี่ยนชื่อบันเดิลทำให้ hook กับ statusline ตายเงียบ** — ทั้งคู่เก็บ *พาธเต็ม*
  ของไบนารีลง `settings.json` ตอนกดติดตั้ง ไม่ได้ค้นหาแอปตอนรัน · ไม่ทำ self-heal เพราะ
  แอปที่ไปเขียนทับ `settings.json` เองตอนเปิดโดยไม่ได้ถูกสั่งคือแอปที่แก้ไฟล์ของผู้ใช้
  ตามใจตัวเอง · `make-app.sh --install` จึงลบ `/Applications/perch.app` ตัวเก่าทิ้ง
  (สองบันเดิลที่รันได้จะแย่ง socket กัน) แล้วบอกให้กดติดตั้งซ้ำหนึ่งครั้ง
- **เมนูบาร์ *เป็น* daemon เอง** ไม่ใช่ตัวสั่ง daemon อีกตัว — สิทธิ์ Bluetooth ผูกกับ `.app`
  ที่ปล่อยผ่าน LaunchServices แยกโปรเซสเมื่อไรได้ daemon ที่ต่อบอร์ดไม่ได้ทันที
- **`-v` และ `-psn_...` ต้องไม่ถูกอ่านเป็นโหมด** — LaunchServices แถม `-psn_0_12345`
  แอปที่ปฏิเสธอาร์กิวเมนต์ที่ไม่รู้จักจะตายทันทีที่ดับเบิลคลิก
- **เลือกบอร์ดจากเมนูของแอป ไม่ใช่หน้า Bluetooth ของ macOS** — BLE peripheral ที่เป็น
  GATT ล้วนไม่โผล่ในหน้าตั้งค่าเลย ระบบเปิดทางให้เฉพาะแอปที่สแกนเองผ่าน CoreBluetooth
  · บอร์ดโฆษณาชื่อ `perch-<MAC 2 ไบต์ท้าย>` เพื่อแยกหลายบอร์ดในห้องเดียวกัน
  · daemon สแกนต่อแม้ต่อบอร์ดได้แล้ว ไม่งั้นสลับไปตัวอื่นไม่ได้จนกว่าจะถอดปลั๊ก

**ไอคอนแถบเมนู**

- **คือแถบโควตา 5 ชม. ไม่ใช่โลโก้** — โลโก้กินพื้นที่ถาวรเพื่อบอกแค่ว่า "แอปยังรันอยู่"
  · แถบ 35x11 + `42%` ตัวเลขความกว้างคงที่ (ไม่งั้นไอคอนขยับทุกครั้งที่เปลี่ยนหลัก)
- **มีขีด pace ด้วย ไม่ใช่มีแต่สี** — `MenuBadge` เก็บ `pace` เป็น *ตำแหน่ง* ไม่ใช่ bool
  (สีคำนวณกลับจากตำแหน่งได้ แต่ตำแหน่งคำนวณกลับจากสีไม่ได้)
- **สองสถานะ ไม่ใช่สามขั้น** — ปกติเป็น template ขาวดำ (ระบบกลับสีให้) · ตอนเตือนเลิกเป็น
  template แล้ววาดแดงตรงๆ · ไอคอน 16 px ที่เหลือบครึ่งวินาทีมีคำถามเดียวคือ
  "ต้องช้าลงไหม" จึงใช้ **แซง pace เป็นเกณฑ์เดียว ไม่มีเกณฑ์เปอร์เซ็นต์ตายตัว** —
  90% ตอนเหลือเวลาอีกนิดเดียวคือโควตาที่ใช้ตามแผนพอดี สีแดงที่ขึ้นทุกครั้งที่ใกล้หมด
  หน้าต่างจะหยุดเป็นสัญญาณ · ไม่รู้ countdown = เทียบ pace ไม่ได้ = ไม่เตือน
- **ตอนเตือน แดงเฉพาะ *ขีด pace*** — สิ่งที่ผิดปกติคือความสัมพันธ์ระหว่างเนื้อแถบกับขีด
  ภาพที่แดงทั้งอันไม่ชี้ว่าให้มองตรงไหน แถมกลืนตัวเลข · หมึกที่เหลือต้องเลือกเองจาก
  appearance ของ *ปุ่ม* ไม่ใช่ของแอป (แถบเมนูมืดได้ทั้งที่แอปสว่าง) และธีมต้องเป็น
  ส่วนหนึ่งของกุญแจ "วาดไปแล้วหรือยัง" ไม่งั้นสลับธีมแล้วหมึกค้าง
- **ขีดเจาะเป็นร่องโปร่งตรงที่พาดผ่านเนื้อแถบ** (หมึกทับหมึกมองไม่เห็น) แต่วาดด้วยหมึก
  ตรงที่อยู่บนรางว่าง · เส้นขอบวาดท้ายสุด ไม่งั้นร่องทำให้กรอบขาดเป็นสองท่อน
  · บนจอบอร์ดใช้วิธีล้นขอบแทน เพราะที่นั่นวาดทับพื้นทึบ ไม่มี alpha ให้เจาะ
- **แถบมีเส้นขอบทึบ** — พื้นหลังแถบเมนูคือวอลเปเปอร์ของผู้ใช้ รางที่จางพอจะไม่แย่งสายตา
  ก็จางพอจะหายไปกับภาพข้างหลัง · เนื้อแถบเว้นจากขอบ 1.5 px ทั้งสี่ด้าน
- **มุมมน 2.5 ไม่ใช่ครึ่งความสูง** — pill อ่านเหมือนปุ่ม ส่วนนี่คือเครื่องวัด และปลายที่โค้ง
  จนกลมทำให้ 3% แรกกับสุดท้ายกินพื้นที่ไม่เท่ากับ 3% ตรงกลาง
- **ตอนเมนูเปิด แบดจ์กลับไปเป็น template แม้กำลังเตือน** — ระบบถมพื้นปุ่มด้วยสีเน้น
  แดงบนน้ำเงินอ่านไม่ออก และนั่นคือสถานะที่ผู้ใช้มองนานที่สุดตอนมันแดง (เขากดเพราะมันแดง)
- **ไม่รู้โควตา → เครื่องวัด (`gauge...50percent`, template) ไม่ใช่ `0%` ไม่ใช่แถบเปล่า** —
  `0%` ที่เดาเอาคือคำโกหกที่ผู้ใช้เชื่อทันที ส่วนแถบเปล่าดูเหมือนแอปพัง · countdown
  ถึงศูนย์นับเป็น "ไม่รู้" ด้วย · ที่ตรงนี้จะกลายเป็นแถบโควตาทันทีที่รู้ตัวเลข ไอคอนแทน
  จึงเป็นเครื่องมือชนิดเดียวกันที่เข็มยังไม่ขยับ ไม่ใช่ `desktopcomputer` ที่พูดถึงจอ
  **กลับคำ**: เคยใช้ `NSApplication.shared.applicationIconImage` ย่อลง ด้วยเหตุผลว่าตรา
  ของแอปพูด "แอปอยู่ แต่ยังไม่รู้ตัวเลข" ตรงกว่าสัญลักษณ์ที่ยืมความหมายมา — แต่โลโก้
  มีแสงเงาและรายละเอียด ที่ 16 px เหลือก้อนส้มที่บอกอะไรไม่ได้ แถมไม่ใช่ template
  จึงไม่กลับสีตามธีม สิ่งที่ผู้ใช้เห็นจริงชนะเหตุผลเรื่องความหมาย
- **ไม่หรี่ไอคอนตอนต่อบอร์ดไม่ติด** — โควตาไม่ได้มาจากบอร์ด การหรี่ทำให้ข้อมูลที่ยังถูก
  ดูเหมือนใช้ไม่ได้ · สถานะบอร์ดอยู่ที่ท้าย popover

## แผง popover

- **คลิกไอคอนได้ popover ไม่ใช่เมนู · เฟืองเหลือแค่ "Settings…" กับ "Quit"** — แผงมีแต่
  ของที่ต้อง *มอง* ของที่ต้อง *ตั้งค่า* อยู่ในหน้าต่างตั้งค่า
  · **กลับคำ**: เดิมเฟืองเด้ง `NSMenu` เต็มใบ เพราะติ๊กถูก/submenu/slider ได้มาฟรี
  แต่หน้า Wi-Fi ต้องมีรายชื่อที่ยาวไม่แน่นอน ช่องรหัสผ่านที่ต้องพิมพ์ และสถานะที่ขยับเอง
  ระหว่างที่ผู้ใช้มองอยู่ — เมนูปิดตัวเองทุกครั้งที่คลิก ทั้งสามอย่างจึงอยู่ในเมนูไม่ได้
  เมื่อต้องมีหน้าต่างอยู่ดี การมีสวิตช์กระจายสองที่แย่กว่าการย้ายมาไว้ที่เดียว
  (`PreferencesWindowController`) · ของที่หายไปพร้อมเมนู: ความรู้เรื่องความกว้าง `NSMenu`
  และแถวสไลเดอร์ที่ต้องยืดเอง — ทั้งหมดเป็นราคาของเมนู ไม่ใช่ของฟีเจอร์
- **popover เป็น `.applicationDefined` แล้วปิดเองด้วยตัวดักคลิก** — `.transient` ปิดตัวเอง
  เมื่อได้เหตุการณ์นอกหน้าต่าง ซึ่งรวมถึงตอนเมนูเฟืองของมันเองกำลัง track อยู่
  แผงจึงหายไปใต้เมนูของตัวเอง
- **การ์ดใช้เกณฑ์สีสามขั้นของบอร์ด ไม่ใช่สองสถานะของแถบเมนู** — ที่นี่มีที่ให้ไล่สีและผู้ใช้
  กำลังมองอยู่จริง · ฝั่ง host **คัดลอก** `warn_pct`/`crit_pct` จาก `tools/layout.toml`
  ด้วยมือ — ตัวสร้าง TOML→Swift เพื่อค่าสองค่าคือเครื่องจักรที่ต้องดูแลมากกว่าค่าที่มันดูแล
  คอมเมนต์อ้างชื่อคีย์ต้นทางไว้แทน · สูตร pace อยู่ที่ `UsageReader.elapsedPercent`
  ที่เดียว เพราะแบดจ์กับการ์ดต้องได้ตัวเลขเดียวกันเสมอ
- **แต่ *สี* บนการ์ดเป็นสีระบบ ไม่ใช่พาเลตต์ของบอร์ด** — พาเลตต์ใน `layout.toml` จูนมา
  สำหรับ TFT ที่หรี่ไฟหลัง บนพื้นดำของ popover อ่านเป็นสีขุ่น · `systemGreen/Orange/Red`
  ตามธีมและการตั้งค่าการเข้าถึงให้เอง · สิ่งที่ต้องตรงกันคือ *เกณฑ์ที่เลือกสี* ไม่ใช่ค่า RGB
- **ชื่อการ์ดบรรทัดบน คำอธิบายบรรทัดล่าง weekly ใช้ pill แทนคำอธิบาย** — ชื่อกับคำอธิบาย
  ในบรรทัดเดียวกันแย่งกันเป็นสิ่งที่อ่านก่อน และบีบเปอร์เซ็นต์จนไม่ชิดขวาเวลาชื่อยาว
- **ขีด pace อยู่บนแถบเสมอ ไม่ใช่เฉพาะตอนแซง** · วาดด้วยสีข้อความทับตรงๆ ได้
  ไม่ต้องเจาะร่องอย่างบนแถบเมนู เพราะพื้นหลังเป็นพื้นทึบของแผง
- **เวลารีเซ็ตบอกทั้งสัมพัทธ์และสัมบูรณ์** — `Resets in 2h24m (Today 23:00)` อันแรกตอบ
  "อีกนานไหม" อันหลังตอบ "ตอนนั้นคือเมื่อไรของวัน" · weekly ไกลถึงเจ็ดวัน
  `Today/Tomorrow` จึงไม่พอ ต้องมีชื่อวันและวันที่
- **บรรทัดอายุของค่ามีหน่วยวินาที** ต่างจากที่อื่นในแอป — คำถามที่ทำให้ฟีเจอร์นี้เกิดคือ
  "เลขนี้ค้างหรือเปล่า" คำตอบระดับนาทีแค่ย้ายความสงสัยจากบอร์ดมาไว้บนเมนูบาร์
  และตัวเลขที่เดินทุกวินาทีเป็นหลักฐานว่าแผงยังมีชีวิต · อยู่ *ใต้การ์ด* ไม่ใช่ท้ายแผง
  เพราะเป็นคำอธิบายของตัวเลขที่อยู่เหนือมัน
- **สองบรรทัดที่พูดคนละเรื่อง** — "key หมดอายุ" (ต้องลงมือ กดที่บรรทัดเพื่อใส่ key ใหม่)
  กับ "ค่านี้อายุเท่าไร" ยุบเป็นบรรทัดเดียวเมื่อไร ผู้ใช้จะแยกไม่ออกว่า "เก่า" แปลว่าต้องทำ
  อะไรหรือไม่ต้องทำอะไร — ค่าเก่ายังถูกได้เสมอในโดเมนนี้
- **ไม่มีแถวสถานะระบบ** — แถวที่เขียนว่า "ปกติ" เกือบทุกวันจะกลายเป็นสิ่งที่สายตาข้าม
  พอถึงวันที่มันไม่ปกติก็ไม่มีใครอ่าน · สิ่งที่ต้องลงมือมีบรรทัดของตัวเองเฉพาะตอนที่ต้องลงมือ
  (`PanelText.keyProblem`) ส่วนสิ่งที่ตั้งค่าได้อยู่หลังเฟืองพร้อมเครื่องหมายถูก ซึ่ง *คือ*
  ความจริง ไม่ใช่สำเนา · บรรทัดอายุของค่าตอบ "ท่อยังเดินอยู่ไหม" ได้ตรงกว่าแถวที่บอกว่า
  ท่อ *ควร* จะเดิน · ข้อยกเว้นเดียวคือบรรทัดบอร์ด เพราะเป็นสถานะของอุปกรณ์คนละที่กับแอป
- **หน้าตั้งค่าอ่านสถานะจริงทุกครั้งที่เปิด ไม่ใช่จำไว้ตอนสร้างหน้าต่าง** — ติ๊กสองอัน
  (statusline, launch at login) แก้จากข้างนอกได้โดยแอปไม่รู้เรื่อง และหน้าต่างมีอายุยืน
  กว่าเมนูที่ถูกสร้างใหม่ทุกครั้ง · ตัว controller ไม่รู้จัก BLE ไฟล์ หรือ `UserDefaults`
  เลย ทุกอย่างเข้าออกผ่าน closure เพื่อให้ที่เก็บสถานะจริงยังมีที่เดียว
- **หน้า Wi-Fi ยกเรื่อง client isolation ขึ้นมาก่อนที่จะพัง** — เน็ตโรงแรม/ออฟฟิศให้บอร์ด
  ขึ้นเน็ตได้ตามปกติแล้วเงียบทีหลัง อาการนั้นอ่านเหมือนบั๊กของเรา ไม่ใช่ของเน็ต
- **ลิงก์โปรเจกต์อยู่ในหน้าตั้งค่า ไม่ใช่บนแผง** — เคยวางไว้ท้ายแผงแล้วผิดกฎข้อแรกของหมวดนี้:
  แผงมีแต่ของที่ต้อง *มอง* ลิงก์เป็นของที่ *กด* และไม่ใช่สถานะของอะไรเลย · ชื่อรายการ
  *คือ* ปลายทาง (`github.com/zeuscs09/perch` ไม่ใช่คำว่า "GitHub") — แอปนี้ขอ
  credential เต็มบัญชีจากผู้ใช้ ลิงก์ที่ซ่อนปลายทางไว้หลังคำสวยๆ เป็นท่าเดียวกับที่ผู้ใช้ควรระวัง
- **ไม่มีค่าเลยทั้งสองหน้าต่าง → ซ่อนการ์ดทั้งช่อง เหลือแต่บรรทัดอายุ** · หน้าต่างที่รู้ใบเดียว
  ยังโชว์ทั้งคู่ โดยใบที่ไม่รู้เขียน `--%` สีจาง ไม่ใช่ `0%` สีเขียว
- **ปุ่ม refresh เป็นทางออกฉุกเฉิน — ยิงหนึ่งรอบ แล้วเย็นตัว 10 วินาที** — endpoint นี้
  ไม่มีเอกสาร ปุ่มที่กดรัวได้จะทำลายเหตุผลที่เราตัดตัวเลือก 30 วินาทีทิ้ง · ทางปกติคือ
  *การเปิดแผง* เอง (`RefreshControl.wantsPoll`) ซึ่งเป็นสัญญาณความตั้งใจที่ชัดพอ ·
  เย็นตัวนับจากตอน *จบ* ไม่ใช่ตอนเริ่ม ไม่งั้นรอบที่ช้ากว่าสิบวินาทีจะไม่มีการเย็นตัวเลย ·
  เกณฑ์ตอนเปิดดูสองอย่าง: ค่าล่าสุดที่ *กลับมา* (`UsageReader.stamp`) กับรอบล่าสุดที่
  *ออกไป* (`UsagePoller.lastStarted`) — รอบที่ล้มเหลวไม่เคยขยับอันแรก ถ้าดูแต่อันแรก
  การเปิดปิดแผงตอนเน็ตล่มจะยิงลูกทุกครั้งที่ชำเลืองดู
- **`Off` และ key ที่หมดอายุไม่ปิดปุ่ม** — `Off` สั่งว่าแอปอย่ายิง *เอง* ไม่ได้ห้ามผู้ใช้ดูค่าใหม่
  · `UsagePoller` มีสองประตู: `pollNow` (นาฬิกา เคารพทุกกฎ) กับ `refreshNow` (คน ข้าม `Off`
  และข้ามล็อก) เหลือแค่ "ลูกวิ่งอยู่แล้ว" กับ "ไม่มีไฟล์ key" ที่ยังกันทั้งคู่
- **การเย็นตัวเป็นวินัยของ *ปุ่ม* ไม่ใช่ของ poller** — ถ้านับรอบอัตโนมัติด้วย ที่ 60 วินาที
  ปุ่มจะกดไม่ได้หนึ่งในหกของเวลาโดยไม่มีใครเข้าใจว่าทำไม · `MenuBarApp` จำเองว่ารอบไหน
  เป็นของปุ่ม และตั้งค่านั้นจาก `isRunning` ไม่ใช่ตั้ง `true` ดื้อๆ
- **กำลังยิง = ตัวหมุนแทนที่ปุ่ม ไม่ใช่ปุ่มที่จางลง** — ปุ่มจางอ่านได้ว่า "กดไม่ได้ตอนนี้"
  ซึ่งเป็นภาพเดียวกับตอนเย็นตัว · ทั้งคู่ยืนในกรอบขนาดคงที่ ไม่งั้นหัวแผงขยับทุกครั้ง
- **ตัวสลับ org อยู่หลังลูกศรข้างชื่อที่หัวแผง ไม่อยู่ในเมนูเฟือง** — ที่สลับสองที่แปลว่าผู้ใช้
  ต้องจำว่าอันไหนคืออันจริง · ลูกศรโผล่เมื่อมีมากกว่าหนึ่ง org เท่านั้น · ยังไม่ได้ตั้ง key =
  หัวแผงเป็นชื่อแอป ไม่ใช่ชื่อที่ค้างมาจาก key ตัวก่อน

**autolayout ของ popover** (สามข้อนี้แก้ปัญหาเดียวกันคนละด้าน)

- **`NSPopover` โตตาม autolayout ได้เอง แต่ไม่หดกลับ** — ต้องตั้ง `preferredContentSize`
  จาก `fittingSize` ทุกครั้งที่เนื้อในเปลี่ยน (ไม่ใช่ทุกวินาที — แผงวาดใหม่ทุกวินาที
  แต่ขนาดเปลี่ยนนานๆ ครั้ง) ไม่งั้นแถวที่หายไปกลายเป็นช่องว่างท้ายแผง
- **ขอบล่างของแผงและของการ์ดหักได้ (priority 999) ส่วนขอบบนเป็นข้อบังคับ** — ความสูงจริง
  ของเนื้อในเปลี่ยนได้ทีหลัง (การ์ดโผล่, ลูกศร org มาถึงหลัง poll แรก) ในจังหวะที่กรอบ
  ยังเตี้ยกว่าเนื้อใน · ถ้าขอบล่างเด็ดขาด สิ่งที่ยอมหักคือระยะห่างระหว่าง view — หัวแผง
  กับการ์ดใบแรกทับกัน · ปล่อยให้ขอบล่างหักแล้วส่วนเกินล้นไปโดนตัดที่ `root.clipsToBounds`
  ซึ่งอ่านว่า "ยังไม่นิ่ง" · `resize()` จัด layout ซ้ำทันทีในเฟรมเดียวกันหลังตั้งขนาด
- **ทุกบรรทัดต้านการบีบด้วย `required` และ stack ทุกชั้นไม่ยืดตามกรอบ** — 999 ยังชนะ
  แรงต้านการบีบตามค่าปริยายของ `NSTextField` (750) กรอบที่เตี้ยกว่าจึงกดแถวจนสูงเป็นศูนย์
  หัวการ์ดหายไปทั้งแถวโดยที่การ์ดยังดูปกติ · ทางกลับกัน กรอบที่สูงเกิน (popover ที่ยังไม่หด)
  ถูก `NSStackView` แจกส่วนเกินให้ arranged view ทั้งหมด การ์ดใบแรกจึงพองเป็นช่องว่าง ·
  แก้ที่เดียว: `compressionResistance` ของทุกบรรทัด + `hugging`/`clippingResistance`
  แนวตั้งของ stack ทุกชั้นเป็น `required`
- **แผงต้องถมไฮไลต์ให้ปุ่มบนแถบเมนูเอง** — การถมมาฟรีกับ `statusItem.menu` เท่านั้น
  และแบดจ์ต้องวาดใหม่ตอนถูกถม (ภาพที่ไม่ใช่ template อ่านไม่ออกบนพื้นสีเน้น)
- **แผงที่เปิดค้างมีนาฬิกาของตัวเองที่หยุดที่ `popoverDidClose` ที่เดียว** — อ่าน cache
  จากดิสก์ทุกวินาทีเพื่อข้อความที่ไม่มีใครมองคือเผาแบต · ทางปิดมีหลายทาง จึงรวมไว้จุดเดียว
- **ขอบการ์ดใช้ `tertiary` ไม่ใช่ `separatorColor`** — `separatorColor` จูนมาสำหรับพื้นสว่าง
  บนพื้นดำของ popover มันจางจนการ์ดสองใบอ่านเป็นข้อความสี่ก้อนที่ไม่รู้ว่าก้อนไหนคู่กัน
  · พื้นการ์ดช่วยไม่ได้เพราะจงใจจางเพื่อไม่ให้เป็นกล่องซ้อนกล่อง
- **รางของแถบในการ์ดใช้ `tertiary` ไม่ใช่ `quaternary`** — รางวาดบนพื้นการ์ดที่จางอยู่แล้ว
  อีกที ระดับจางที่สุดซ้อนบนของจางกลืนไปกับพื้น แล้วเนื้อแถบอ่านเป็นขีดลอยๆ ที่ไม่รู้ว่า
  ยาวเทียบกับอะไร · บนแถบเมนูไม่มีปัญหานี้เพราะมีเส้นขอบทึบบอกขอบเขตอยู่แล้ว

## ฝั่ง firmware (ESP-IDF v5.5)

```
firmware/main/pch_lcd.c      SPI + init ILI9341 ตามผลวัด + ไฟหลัง PWM (LEDC)
firmware/main/pch_rects.c    rect list ในพิกัด unit + ขอบ + กรอบรวม
firmware/main/pch_props.c    prop ทั้ง 9 ชิ้น  (พอร์ตตรงจาก tools/gen/props.py)
firmware/main/pch_mascot.c   mood + สถานะ + การจัดกึ่งกลาง (พอร์ตจาก mascot.py)
firmware/main/pch_model.c    JSON snapshot -> struct (cJSON)
firmware/main/pch_ui.c       หน้าจอทั้งใบด้วย LVGL 9.2 (โครงเดียวกับ screen.py)
firmware/main/pch_ble.c      NimBLE GATT server 3 characteristic + bonding
firmware/main/pch_wifi.c     WiFi station: สแกน จำเครือข่าย ต่อใหม่เอง (ดูหัวข้อ "WiFi")
firmware/main/pch_lan.c      TCP 7333 + AES-GCM + mDNS — ทางเดินที่สองของ snapshot
firmware/main/pch_led.c      RGB LED กะพริบตอนมีการเตือนใหม่
firmware/main/main.c        ประกอบทุกอย่าง + ลูปหลัก
```

`idf.py -p /dev/cu.usbserial-XX flash monitor` — บิลด์ได้ ~900KB ใน partition 3MB

- **มาสคอตวาดด้วย `LV_EVENT_DRAW_MAIN` ต่อ slot** ไม่ใช่ canvas — canvas เต็มจอกิน 150KB
  ซึ่งบอร์ดไม่มีให้ ส่วน draw callback วาดลงบัฟเฟอร์บางส่วนของ LVGL โดยตรง
- **ฉากท้องฟ้าเป็น object ผืนเดียวที่สร้างก่อนใครเพื่อน** — LVGL เรียงชั้นตามลำดับสร้าง
  · เมฆอยู่ในผืนเดียวกัน ไม่ใช่ object แยก: แถบฟ้า 320x98 น้อยกว่าที่ 3 slot วาดใหม่
  ทุกเฟรมอยู่แล้ว จึงไม่ต้องแลกความซับซ้อนกับอะไรเลย
- **ฟ้าวาดใหม่เมื่อภาพเปลี่ยนจริง ไม่ใช่ทุกเฟรม** — เมฆขยับ 4 px/วิ (4 ครั้ง/วิ) ส่วนลูปหลัก
  เดิน 16 เฟรม/วิ · `lv_obj_invalidate_area` เฉพาะแถบฟ้า พื้นดินกับหญ้าวาดใหม่เมื่อ
  ช่วงเวลาเปลี่ยนเท่านั้น
- **ตารางดาว/หญ้า/เมฆ generate เป็น C array จาก `layout.toml`** — ถ้าแต่ละฝั่งสุ่มเอง
  ภาพบน preview จะไม่ใช่ภาพบนบอร์ด แล้ว preview ก็หมดประโยชน์
- **เงาใต้เท้าวาดเป็นแคปซูล ไม่ใช่วงรี** — `lv_draw_rect` clamp radius ที่ครึ่งด้านสั้น
  ฝั่ง preview จึงต้องใช้ `rounded_rectangle` ตาม ไม่ใช่ `ellipse` ที่สวยกว่าแต่คนละรูป
- **ปิด `LV_USE_TEXTAREA` ไม่ได้** — spinbox ใน LVGL 9.2 พึ่งมันแบบ `#error`
- **`pch_model_parse` เขียนทับ snapshot เดิมทีเดียวตอนท้าย** — JSON พังกลางทางต้องไม่ทิ้ง
  ภาพครึ่งๆ
- **สถานะที่ firmware ไม่รู้จักตกเป็น `idle`** ไม่ใช่ค้างจอ — daemon อาจใหม่กว่า firmware
- **ชื่ออุปกรณ์อยู่ใน scan response ส่วน adv บรรจุ service UUID 128 บิต** — ทั้งคู่ไม่พอ
  ใน 31 ไบต์ และฝั่ง Mac สแกนด้วย UUID จึงต้องเป็นตัวที่อยู่ใน adv
- **`pch_lan.c` เปิด server ตามการมี IP ไม่ใช่ตามการมีกุญแจ** — บอร์ดที่รับสายแล้วปฏิเสธ
  ทุกเฟรมบอกฝั่ง Mac ได้ว่ากุญแจไม่ตรง ส่วนบอร์ดที่ไม่รับสายเลยแยกไม่ออกจากบอร์ดที่ตาย
- **สายใหม่ชนะสายเก่าเสมอ** — Mac ที่เพิ่งกลับจากหลับทิ้งซ็อกเก็ตค้างไว้ฝั่งบอร์ด ซึ่ง TCP
  ยังไม่รู้ว่าตายจนกว่า keepalive จะครบ ระหว่างนั้นจอค้างโดยไม่มีเหตุผลให้เห็น
- **mDNS ไม่ได้อยู่ในแกนของ IDF v5 แล้ว** — ต้องดึง `espressif/mdns` ผ่าน
  `main/idf_component.yml` การบิลด์ครั้งแรกจึงต้องมีเน็ต

**ยืนยันบนบอร์ดจริงแล้ว**: บูตผ่าน จอ init สำเร็จ NimBLE ขึ้น ไม่มี watchdog
**ยังไม่ได้ยืนยัน**: ภาพบนจอ (ต้องมองด้วยตา) · BLE จับคู่กับ daemon จริง · RGB LED

## เครื่องมือฝั่ง Python

```
tools/layout.toml          ต้นทางเดียวของค่าคงที่ layout + จานสี
tools/gen/rects.py         ชนิดข้อมูล rect list + การแปลง (เลื่อน/สะท้อน/ย่อ/ทำขอบ)
tools/gen/mascot.py        โครงร่างมาสคอต, mood, ตาราง state -> (mood, prop)
tools/gen/props.py         prop ทั้ง 9 ชิ้น + กรอบวาดมาตรฐาน
tools/gen/screen.py        ประกอบจอ 320x240 ทั้งใบ
tools/gen/render.py        rect list -> ภาพ (บีบสีเป็น RGB565 ให้ตรงกับจอจริง)
tools/preview.py           สร้าง out/states.png, out/anim/*.gif, out/screen_*.png|gif
tools/export_layout.py     layout.toml -> firmware/main/layout.h
tools/make_icon.py         โลโก้ PNG + rect list -> host/Resources/AppIcon.icns
```

**เคยกลับคำครึ่งหนึ่ง แล้วกลับมาอีกที: ไอคอนทุกขนาดมาจาก rect list** — รอบแรก
`make_icon.py` เรนเดอร์มาสคอตท่า `idle` จาก `gen/mascot.py` ทุกขนาด · รอบสองเปลี่ยนให้
ขนาดใหญ่ใช้ PNG วาดมือ ด้วยเหตุผลที่ยังมีน้ำหนักอยู่: rect list ทำได้แค่ silhouette แบนสีเดียว
ซึ่งพอดีกับจอ 320x240 ที่บีบเป็น RGB565 อยู่แล้ว แต่ไอคอนบน Dock ไปนั่งข้างไอคอนที่มีวัสดุ
และแสงเงา — มาสคอตบนจอกับตราของแอปเป็นคนละงาน

**ราคาที่ตกลงจ่ายไว้ถึงกำหนดชำระพอดีตอนที่ไม่มีใครจ่ายได้** ราคานั้นเขียนไว้ตรงๆ ว่า
"มาสคอตเปลี่ยนแล้วไอคอนใหญ่ไม่เปลี่ยนตาม ต้องวาด PNG ใหม่เอง" แล้ววันที่โครงการเปลี่ยนชื่อ
จาก TamaClaude เป็น Perch ก็มาถึง: PNG นั้นเป็นทั้งงานศิลป์ของต้นทางและเป็นภาพของคอนเซ็ปต์
ที่เลิกไปแล้ว (ทามาก็อตจิ) มันจึงค้างอยู่บนหัว README โดยไม่มีใครสังเกต จนเห็นในหน้า repo บนมือถือ

**ทางออกไม่ใช่การเลือกข้าง แต่เป็นการแยกเป็นสองขั้น** — `tools/make_logo.py` สร้าง *ต้นแบบ*
แบนจาก `gen/mascot.py` (`perch-logo-reference.png`, คอมมิตไว้) แล้วโมเดลสร้างภาพลงวัสดุ
และแสงเงาให้เป็น `perch-logo.png` ที่ใช้จริง · รูปทรงจึงยังผูกกับ rect list และตามมาสคอตทัน
ส่วนความมีวัสดุที่ทำให้มันยืนอยู่ข้างไอคอนอื่นบน Dock ได้ก็ไม่ต้องเสียไป
· ขั้นที่สองสร้างซ้ำจากโค้ดล้วนไม่ได้ จึงคอมมิตผลลัพธ์ไว้ ไม่ใช่คอมมิตแค่สคริปต์

**ภาพคือสามสายพันธุ์เกาะคอนเดียวกัน ไม่ใช่ตัวเดียว** — ตรงกับสิ่งที่จอแสดงจริงหลังจากที่
Codex กับ Antigravity มีรูปทรงของตัวเอง · แต่ **วัดแล้วที่ 32 px สามตัวเละเป็นก้อนสีเดียวกัน**
`≤64 px` จึงเหลือตัวเดียว ซึ่งเป็นเหตุผลที่ `.icns` เก็บภาพแยกต่อขนาดตั้งแต่แรก
· ทั้งสองชุดใช้พื้นหลัง คอน และสีชุดเดียวกัน จุดตัดจึงอ่านเป็น "เพื่อนมาเพิ่ม" ไม่ใช่ "ของคนละใบ"
· คอนใช้สีเทาเข้ม ไม่ใช่เฉดของสีดิน — เคยลองแล้วมันกลืนไปกับตัวมาสคอตจนอ่านเป็นเงาใต้เท้า

**แต่ `.icns` เก็บภาพแยกต่อขนาดได้ ขนาดเล็กจึงไม่ใช่โลโก้ที่ย่อลง** — แสงเงา ฟองคำพูด
และหัวใจในโลโก้ละลายเป็นก้อนส้มที่ 16 px ของพวกนี้ไม่ได้เล็กลง มันกลายเป็นฝ้าที่ทำให้
ของที่เหลืออ่านยากขึ้น · **≤ 64 px วาดใหม่จาก rect list ตัวเดิม** เหลือแค่ตัวเครื่องสีส้ม
จอมืด มาสคอตหนึ่งตัว · **≥ 128 px ใช้ PNG** — จุดตัดอยู่ที่พิกเซลจริง ไม่ใช่ชื่อไฟล์
(`icon_16x16@2x` คือ 32 px)
- **วงคาดครีมหายต่ำกว่า 64 px** — ไม่ใช่เพราะมองไม่เห็น แต่เพราะกินที่: ส้ม→ครีม→ดำ
  สามชั้นที่ 16 px เหลือจอกว้าง 6 px ให้มาสคอตทั้งตัว
- **ตาวาดด้วยสีจอ ไม่ใช่ `PAL.ink`** — ที่ขนาดนี้ตาคือรูที่เห็นจอทะลุ หมึกที่ต่างจากพื้นจอ
  นิดเดียวกลายเป็นขอบเทาหนึ่งพิกเซลรอบรูแทนที่จะเป็นรู
- **ขอบ 10% เท่ากันทั้งสองชุด** — เคยให้ชุดเล็กบางกว่า (6%) เพื่อแลกเนื้อภาพ แต่ผู้ใช้
  เลื่อนขนาดไอคอนใน Finder ผ่านจุดตัด 64→128 แล้วเห็นไอคอนกระโดดขนาด อ่านเหมือน
  ภาพผิดมากกว่าภาพคมขึ้น · ที่ 16 px การปัดเศษทำให้ 6% กับ 10% ได้จอกว้างเท่ากันอยู่ดี
- **วาดที่ 8 เท่าแล้วย่อ** — ขอบมนที่วาดตรงๆ ที่ 16 px ได้ขอบหยัก ไม่ใช่ขอบมน

## ความเสี่ยงที่ยังเปิดอยู่

- **Python preview ≠ ของจริง** — พิสูจน์ได้แค่การออกแบบ ไม่ได้พิสูจน์ renderer ฝั่ง C
  บรรเทาด้วย `layout.toml` → `layout.h` แต่ยังไม่ได้ทดสอบครบบนบอร์ด
- **ฟอนต์ preview ≠ ฟอนต์บนบอร์ด** — ระยะห่างตัวอักษรและจุดที่ข้อความขาดจะไม่ตรงเป๊ะ

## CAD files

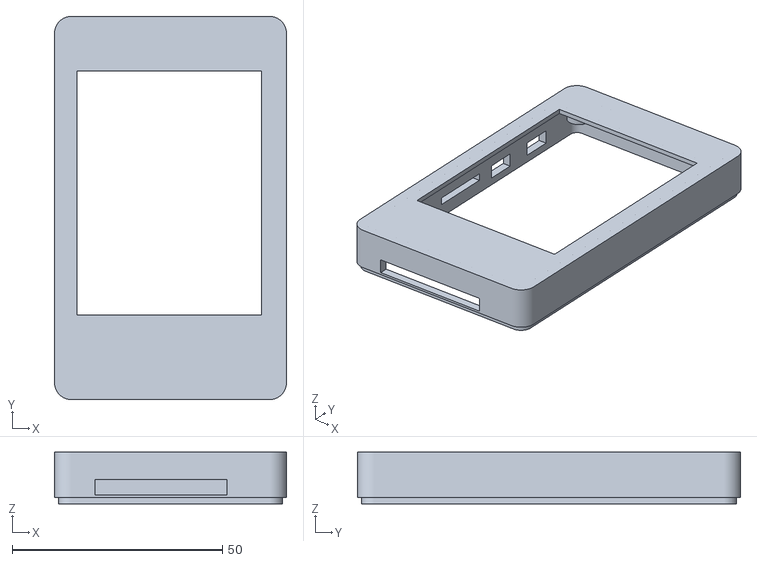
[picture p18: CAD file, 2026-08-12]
hardware/case/front_case_v4_slot.stl
55.2 x 91.2 x 12.3

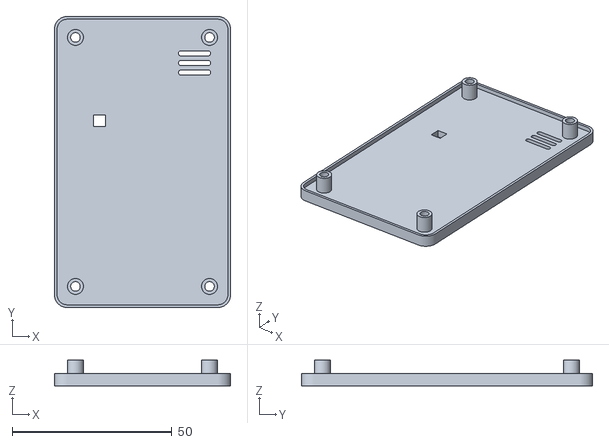
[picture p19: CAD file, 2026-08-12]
hardware/case/back_cover.stl
55.2 x 91.2 x 8.00

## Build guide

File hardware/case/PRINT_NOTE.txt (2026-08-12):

Perch case — 2 ชิ้น พิมพ์ชิ้นละ 1 อัน

  front_case_v4_slot.stl  ฝาหน้า (ช่องพอร์ตเป็นช่องยาวช่องเดียว)
  back_cover.stl       ฝาหลัง (มีลายตัวการ์ตูนเซาะไว้ที่ผิวนอก)

  * ไม่ใช้ back_plate_v2 / battery_box ในรอบนี้

วัสดุ    PLA หรือ PETG
Layer    0.2 mm
Support  ไม่ต้อง ทั้ง 2 ชิ้น

  ** ขอเน้นสองข้อนี้ (กันแสงจากจอลอดออกมาตอนกลางคืน) **

Walls / perimeters   4-5 ชั้น   <-- สำคัญที่สุด
Top/bottom solid     5-6 ชั้น
Infill               40% พอ ไม่ต้อง 100%
สี                   ยิ่งเข้มยิ่งดี (ส้มอ่อนโปร่งแสง)

การวางชิ้น
  front_case_v2  คว่ำหน้าจอลงเตียง
  back_cover     คว่ำผิวที่มีลายลงเตียง เสาชี้ขึ้น
                 (ลายเป็นร่องลึก 0.6 mm อยู่บนผิวที่แนบเตียง ไม่ต้อง support)

ประกอบ  ฝาหลังมีริมหนา 0.85 mm สวมเข้าไปในบ่าของฝาหน้า
        ยึดด้วยสกรูเดิม 4 ตัวผ่านเสากลาง

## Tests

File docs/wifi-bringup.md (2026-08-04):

# Wi-Fi bring-up — checklist ที่ต้องทำด้วยมือ

`perchtest` ครอบได้แค่ตรรกะล้วน (การประกอบคำสั่ง การอ่านรายงาน การเรียงรายการ) ส่วนที่เหลือ
ต้องมีบอร์ดจริง วิทยุจริง และเราเตอร์จริง — ไล่ตามลำดับนี้หลังแตะ `pch_wifi.c`, `pch_ble.c`
หรือหน้า Wi-Fi ในแอป

## เตรียม

```bash
cd firmware && idf.py -p /dev/cu.usbserial-XX flash monitor
cd host && ./Scripts/make-app.sh --install     # Bluetooth ใช้ได้เฉพาะจาก .app
```

รอบแรกหลังเปลี่ยน firmware ที่แตะ BLE: macOS ถืออะไรค้างไว้จาก bond เดิม ให้ปล่อยให้
`BLE_GAP_EVENT_REPEAT_PAIRING` จัดการเอง — **อย่า**ไปหาบอร์ดใน System Settings ▸ Bluetooth
เพราะ peripheral ที่เป็น GATT ล้วนไม่โผล่ที่นั่นตั้งแต่แรก

## ไล่ทีละข้อ

1. **บูตแล้วไม่มีอะไรพัง** — `idf.py monitor` ต้องไม่มี `Guru Meditation`, ไม่มี watchdog,
   ไม่มี `E (xxx) wifi:` ซ้ำถี่ · จอต้องขึ้นภาพเหมือนเดิมทุกอย่าง
2. **ไอคอนลิงก์** — มุมขวาบนข้างนาฬิกา: BLE ต่ออยู่ = แท่งไต่ขึ้นสีเขียว · ปิด Bluetooth ที่ Mac
   = เปลี่ยนเป็นขีดจางหรือคลื่นเหลือง (เหลืองเมื่อบอร์ดยังอยู่บนเน็ต) เทียบกับ
   `out/screen_busy.png` และ `out/screen_wifi.png`
3. **เปิดหน้าตั้งค่า** — เมนูบาร์ ▸ เฟือง ▸ Settings… ▸ แท็บ Wi-Fi · รายการต้องเริ่มโผล่ทีละ
   บรรทัดภายในไม่กี่วินาที และสปินเนอร์ต้องหยุดเอง (ไม่ใช่หมุนค้าง = ไม่ได้รับ `ap_end`)
4. **รายการเป็นของบอร์ด ไม่ใช่ของ Mac** — วงที่เป็น 5GHz ล้วนต้อง **ไม่** อยู่ในรายการ
   ถ้าโผล่แปลว่าใครสักคนไปดึงจาก CoreWLAN
5. **จับคู่ตอนกด Connect** — ครั้งแรกที่เขียน config characteristic macOS จะ pair เอง
   (ไม่มีกล่องให้กรอกเลข) · ถ้า log บอร์ดขึ้น `encryption change: 0` แปลว่าเข้ารหัสสำเร็จ
   ค่าอื่นแปลว่าล้ม แล้วคำสั่งจะไม่ถึง firmware เลย
6. **รหัสถูก** — สถานะบนหน้าต่างต้องไป `Connecting…` แล้วเป็น `Connected to <ssid>` พร้อม IP
   ที่ ping จาก Mac ได้จริง (`ping <ip>`) — ping ไม่ผ่านทั้งที่ต่อติด = AP กัน client คุยกัน
   ซึ่งเป็นเน็ตที่ใช้กับ M2 ไม่ได้
7. **รหัสผิด** — พิมพ์ผิดตั้งใจหนึ่งครั้ง: ต้องได้ `wrong password` ไม่ใช่ `not in range`
   และบอร์ดต้องลองใหม่เองเรื่อยๆ โดยจอไม่ค้างและ BLE ไม่หลุด
8. **จำข้ามรีบูต** — ถอดสายจ่ายไฟแล้วเสียบใหม่: บอร์ดต้องกลับขึ้นเน็ตเองโดยไม่ต้องเปิดแอป
9. **ลืมเครือข่าย** — เลือกแถวที่ขึ้นว่า `saved` แล้วกด Forget: ต้องหลุดทันที และหลังรีบูต
   ต้องไม่กลับมาต่อเอง
10. **จำหลายวง** — ตั้งค่าสองเครือข่าย (เช่น เราเตอร์บ้าน + hotspot มือถือ) แล้วปิดตัวที่แรงกว่า
    บอร์ดต้องย้ายไปอีกตัวเองภายในเวลาของ backoff (ไม่เกินหนึ่งนาที)
11. **ทั้งสองวิทยุพร้อมกัน** — ระหว่างที่ต่อ WiFi อยู่ ให้ Claude Code ทำงานจริงสักรอบ:
    มาสคอตต้องขยับตามปกติ ไม่มี snapshot หาย และ log ไม่มี `notify failed`

## ทางเดินที่สอง (LAN)

ข้อ 1–11 ต้องผ่านก่อน ทั้งหมดนี้ต้องมีบอร์ดอยู่บนเน็ตเดียวกับ Mac

12. **กุญแจถูกผลักไปเอง** — ต่อ BLE ครั้งแรกหลังแฟลช: log ของแอป (`Open log`) ต้องมี
    `pushing the lan key to the board (xxxxxxxx)` และ log บอร์ดต้องมี `key set (xxxxxxxx)`
    ด้วยเลขชุดเดียวกัน · ผลักซ้ำทุกครั้งที่เปิดหน้าตั้งค่า = ลายนิ้วมือไม่ตรง ให้ดูว่า
    `pch_lan_key_fingerprint` กับ `LanKey.fingerprint` แฮชของอย่างเดียวกันจริงไหม
13. **ประกาศตัวบน mDNS** — `dns-sd -B _perch._tcp` บน Mac ต้องเห็นชื่อบอร์ด ·
    ไม่เห็นแต่ข้อ 14 ยังผ่านก็ยอมรับได้ (เราเตอร์กรอง multicast) แต่ต้องรู้ตัว
14. **สลับทางจริง** — ปิด Bluetooth ที่ Mac ค้างไว้: ภายใน ~10 วินาที ท้าย popover ต้อง
    เปลี่ยนเป็น `Board connected over Wi-Fi` และจอต้องยัง **สด** (การ์ดกับแผงโควตาไม่หาย
    มาสคอตไม่เป็นสีเทา) ป้ายบนแถบเป็น IP และไอคอนเป็นคลื่น · เร็วกว่า 10 วิ = grace ไม่ทำงาน
15. **หนึ่งเฟรมต่อการเปลี่ยนแปลง ไม่ใช่ต่อวินาที** — ระหว่างอยู่บน LAN ให้ดู log บอร์ด:
    `snapshot ...` ต้องโผล่ตอนสถานะเปลี่ยนหรือนาทีเปลี่ยนเท่านั้น ถ้ามาทุกวินาทีแปลว่า
    การเทียบ "เปลี่ยนไหม" พังอีกรอบ (คีย์ JSON ไม่ได้เรียง)
16. **กลับขึ้น BLE** — เปิด Bluetooth คืน: ท้าย popover กลับเป็น `Board connected` ทันที
    log บอร์ดต้องมี `mac disconnected` (Mac ปล่อยสาย ไม่ใช่ทิ้งค้าง)
17. **ตัวนับข้ามการรีบูตของ Mac** — ระหว่างอยู่บน LAN ให้ปิดแอปแล้วเปิดใหม่: ต้องกลับมา
    ส่งได้เองโดยไม่ต้องแตะ BLE เลย (บอร์ดบอกเลขตัวนับให้ตอนรับสาย) · ถ้าจอค้างและ log
    บอร์ดขึ้น `replayed counter` แปลว่าคำทักทายไม่ได้ถูกอ่าน
18. **ของปลอมเข้าไม่ได้** — `nc <ip> 7333` แล้วพิมพ์อะไรก็ได้: บอร์ดต้องตัดสายทันที
    (`frame did not authenticate` หรือ `frame length ... out of range`) และจอต้องไม่ขยับ
19. **กรอกที่อยู่เอง** — ใส่ IP ลงช่องล่างสุดของแท็บ Wi-Fi แล้วปิด Bluetooth: ต้องต่อได้
    เหมือนเดิมโดยไม่พึ่ง mDNS · ล้างช่องแล้วต้องกลับไปหาเอง
20. **RAM ยังเหลือ** — `idf.py monitor` หลังอยู่บน LAN สักสิบนาที: ไม่มี
    `heap_caps_malloc failed` และไม่มีการรีบูตเอง · DRAM static เหลือ ~24KB เท่านั้น
    (ดู `idf.py size`) ทาง LAN กับ mDNS เป็นสองตัวที่กินเพิ่มล่าสุด

## ที่ที่มักพังก่อนใคร

- **ลิงก์ไม่ผ่านตอนบิลด์** (`iram0_0_seg overflowed`) — สวิตช์ IRAM ใน `sdkconfig.defaults`
  หายไป ดู DESIGN.md หัวข้อ "WiFi"
- **สปินเนอร์หมุนค้าง** — notification หายเพราะไม่ได้ subscribe (`s_event_subscribed`)
  หรือยิงรัวเกินจน NimBLE ทิ้ง ดูหน่วง 20 ms ใน `emit_scan_results`
- **`heap_caps_malloc` คืน NULL ตอนบูต** — WiFi กินก้อนใหญ่ก่อน LVGL ได้บัฟเฟอร์ DMA
  ให้ลดจำนวนบัฟเฟอร์ WiFi ใน `sdkconfig.defaults` ไม่ใช่ลดบัฟเฟอร์วาดจอ
- **ทาง LAN ไม่เคยขึ้นเลยทั้งที่ ping ผ่าน** — macOS 15 ขึ้นไปขออนุญาต Local Network
  แยกต่างหาก ถูกปฏิเสธแล้วทั้ง Bonjour และการต่อไปหา IP ตรงๆ เงียบไปโดยไม่มี error
  ดูที่ System Settings ▸ Privacy & Security ▸ Local Network
- **`the board rejected us — check the key`** ซ้ำๆ — ลายนิ้วมือสองฝั่งไม่ตรง ให้ต่อ BLE
  หนึ่งครั้งแล้วเปิดหน้าตั้งค่า แอปจะผลักกุญแจใหม่ให้เอง (ข้อ 12)

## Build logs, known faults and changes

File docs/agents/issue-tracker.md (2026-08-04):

# Issue tracker: GitHub

Issues and PRDs for this repo live as GitHub issues. Use the `gh` CLI for all operations.

## Conventions

- **Create an issue**: `gh issue create --title "..." --body "..."`. Use a heredoc for multi-line bodies.
- **Read an issue**: `gh issue view <number> --comments`, filtering comments by `jq` and also fetching labels.
- **List issues**: `gh issue list --state open --json number,title,body,labels,comments --jq '[.[] | {number, title, body, labels: [.labels[].name], comments: [.comments[].body]}]'` with appropriate `--label` and `--state` filters.
- **Comment on an issue**: `gh issue comment <number> --body "..."`
- **Apply / remove labels**: `gh issue edit <number> --add-label "..."` / `--remove-label "..."`
- **Close**: `gh issue close <number> --comment "..."`

Infer the repo from `git remote -v` — `gh` does this automatically when run inside a clone.
For this repo that resolves to `zeuscs09/perch`.

## Pull requests as a triage surface

**PRs as a request surface: no.** _(Set to `yes` if this repo treats external PRs as feature requests; `/triage` reads this flag.)_

When set to `yes`, PRs run through the same labels and states as issues, using the `gh pr` equivalents:

- **Read a PR**: `gh pr view <number> --comments` and `gh pr diff <number>` for the diff.
- **List external PRs for triage**: `gh pr list --state open --json number,title,body,labels,author,authorAssociation,comments` then keep only `authorAssociation` of `CONTRIBUTOR`, `FIRST_TIME_CONTRIBUTOR`, or `NONE` (drop `OWNER`/`MEMBER`/`COLLABORATOR`).
- **Comment / label / close**: `gh pr comment`, `gh pr edit --add-label`/`--remove-label`, `gh pr close`.

GitHub shares one number space across issues and PRs, so a bare `#42` may be either — resolve with `gh pr view 42` and fall back to `gh issue view 42`.

## When a skill says "publish to the issue tracker"

Create a GitHub issue.

## When a skill says "fetch the relevant ticket"

Run `gh issue view <number> --comments`.

## Wayfinding operations

Used by `/wayfinder`. The **map** is a single issue with **child** issues as tickets.

- **Map**: a single issue labelled `wayfinder:map`, holding the Notes / Decisions-so-far / Fog body. `gh issue create --label wayfinder:map`.
- **Child ticket**: an issue linked to the map as a GitHub sub-issue (`gh api` on the sub-issues endpoint). Where sub-issues aren't enabled, add the child to a task list in the map body and put `Part of #<map>` at the top of the child body. Labels: `wayfinder:<type>` (`research`/`prototype`/`grilling`/`task`). Once claimed, the ticket is assigned to the driving dev.
- **Blocking**: GitHub's **native issue dependencies** — the canonical, UI-visible representation. Add an edge with `gh api --method POST repos/<owner>/<repo>/issues/<child>/dependencies/blocked_by -F issue_id=<blocker-db-id>`, where `<blocker-db-id>` is the blocker's numeric **database id** (`gh api repos/<owner>/<repo>/issues/<n> --jq .id`, _not_ the `#number` or `node_id`). GitHub reports `issue_dependencies_summary.blocked_by` (open blockers only — the live gate). Where dependencies aren't available, fall back to a `Blocked by: #<n>, #<n>` line at the top of the child body. A ticket is unblocked when every blocker is closed.
- **Frontier query**: list the map's open children (`gh issue list --state open`, scoped to the map's sub-issues / task list), drop any with an open blocker (`issue_dependencies_summary.blocked_by > 0`, or an open issue in the `Blocked by` line) or an assignee; first in map order wins.
- **Claim**: `gh issue edit <n> --add-assignee @me` — the session's first write.
- **Resolve**: `gh issue comment <n> --body "<answer>"`, then `gh issue close <n>`, then append a context pointer (gist + link) to the map's Decisions-so-far.

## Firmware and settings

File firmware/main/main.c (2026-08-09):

// perch — จอแสดงสถานะ Claude Code บนบอร์ด CYD
//
// เส้นทางข้อมูล: BLE write -> staging (mutex) -> ลูปหลัก -> LVGL -> SPI -> จอ
// LVGL ไม่ปลอดภัยกับหลายเธรด ทุกการแตะ UI จึงเกิดในลูปหลักที่เดียว
#include <string.h>

#include "cJSON.h"
#include "pch_ble.h"
#include "pch_lan.h"
#include "pch_lcd.h"
#include "pch_dim.h"
#include "pch_led.h"
#include "pch_night.h"
#include "pch_touch.h"
#include "pch_mascot.h"
#include "pch_model.h"
#include "pch_ui.h"
#include "pch_face.h"
#include "pch_wifi.h"
#include "esp_log.h"
#include "esp_system.h"
#include "esp_timer.h"
#include "freertos/FreeRTOS.h"
#include "freertos/semphr.h"
#include "freertos/task.h"
#include "layout.h"
#include "lvgl.h"
#include "nvs_flash.h"

static const char *TAG = "main";

// โหมดทดลองใบหน้า — บิลด์ด้วย `idf.py -DPCH_FACE=1 build` ค่าปกติคือปิด
// ตั้งใจให้เป็นธงคอมไพล์ ไม่ใช่ค่ารันไทม์ เพราะโหมดนี้ไม่คืนค่าและกินจอทั้งใบ
#ifndef PCH_FACE
#define PCH_FACE 0
#endif
#ifndef PCH_RELAYTEST
#define PCH_RELAYTEST 0
#endif
// ตั้งที่อยู่ relay ตอนบูตครั้งเดียวสำหรับการพัฒนา ค่าจะถูกจดลง NVS จึงอยู่ต่อแม้ flash
// ตัวที่ไม่มีธงนี้ทับ — ของจริงมาทาง BLE
//
//   idf.py -DPCH_RELAY_BOOTSTRAP=1 -DPCH_RELAY_HOST=\"1.2.3.4\" -DPCH_RELAY_PORT=7333
//
// **ไม่มีที่อยู่จริงเป็นค่าเริ่มต้น** — relay คือเซิร์ฟเวอร์ของใครสักคน การฝังไว้ใน repo
// แปลว่าบอร์ดของทุกคนที่โหลดไปจะวิ่งไปหาเครื่องนั้นโดยเจ้าของไม่ได้เลือก
#ifndef PCH_RELAY_BOOTSTRAP
#define PCH_RELAY_BOOTSTRAP 0
#endif
#ifndef PCH_RELAY_HOST
#define PCH_RELAY_HOST "192.0.2.1"     // TEST-NET-1 — ต่อไม่ติดโดยตั้งใจ
#endif
#ifndef PCH_RELAY_PORT
#define PCH_RELAY_PORT 7333
#endif

// บัฟเฟอร์วาดของ LVGL: 1/10 ของจอสองก้อน (~15KB) ไม่ใช่ framebuffer เต็ม 150KB
// บอร์ดนี้ไม่มี PSRAM จึงไม่มีทางเลือกอื่นอยู่แล้ว
#define DRAW_LINES 24
#define DRAW_BUF_PX (PCH_SCREEN_WIDTH * DRAW_LINES)

static lv_color_t *s_buf1, *s_buf2;
static SemaphoreHandle_t s_lock;

// ของที่ BLE ฝากไว้ให้ลูปหลักหยิบไปใช้
static pch_snapshot_t s_pending;
static bool s_has_pending;
static bool s_link;
static bool s_link_changed = true;
static bool s_wifi_up;
static char s_ip[16];
static int s_pending_backlight = -1;

static uint32_t millis_cb(void) { return (uint32_t)(esp_timer_get_time() / 1000); }

static void flush_cb(lv_display_t *disp, const lv_area_t *area, uint8_t *px_map)
{
    size_t px = (size_t)(area->x2 - area->x1 + 1) * (area->y2 - area->y1 + 1);
    // LVGL เก็บ RGB565 แบบ little-endian ส่วนจอกินแบบ big-endian
    lv_draw_sw_rgb565_swap(px_map, px);
    pch_lcd_blit(area->x1, area->y1, area->x2, area->y2, px_map, px * 2);
    lv_display_flush_ready(disp);
}

// --- callback จาก NimBLE (คนละเธรดกับ LVGL) ---------------------------------
static void on_state(const char *json, int len)
{
    pch_snapshot_t parsed;
    if (!pch_model_parse(json, len, &parsed)) {
        ESP_LOGW(TAG, "snapshot was not valid json");
        return;
    }
    ESP_LOGI(TAG, "snapshot %s: %d sessions, %d cards", parsed.clock, parsed.session_count,
             parsed.card_count);
    xSemaphoreTake(s_lock, portMAX_DELAY);
    s_pending = parsed;
    s_has_pending = true;
    xSemaphoreGive(s_lock);
}

// กุญแจของทาง LAN เดินมาช่องเดียวกับรหัส WiFi ด้วยเหตุผลเดียวกัน (ต้องเข้ารหัส) แต่
// เจ้าของคนละโมดูล — แยกออกมาที่นี่แทนที่จะยัดเข้า `pch_wifi_command` เพื่อไม่ให้โมดูล
// WiFi ต้องรู้จักเรื่องการปิดผนึกเฟรม ซึ่งเป็นคนละชั้นกัน
static bool lan_command(const char *json, int len)
{
    cJSON *root = cJSON_ParseWithLength(json, len);
    if (!root) return false;
    const cJSON *cmd = cJSON_GetObjectItem(root, "c");
    const cJSON *key = cJSON_GetObjectItem(root, "k");
    bool mine = cJSON_IsString(cmd) && strcmp(cmd->valuestring, "key") == 0;
    if (mine && !pch_lan_set_key(cJSON_IsString(key) ? key->valuestring : NULL)) {
        ESP_LOGW(TAG, "lan key rejected");
    }
    // ที่อยู่ relay มาช่องเดียวกับกุญแจ ด้วยเหตุผลเดียวกัน: ช่องนี้บังคับเข้ารหัส BLE
    // อยู่แล้ว และทั้งสองอย่างเป็นการตั้งค่าของทางเดินเดียวกัน
    if (!mine && cJSON_IsString(cmd) && strcmp(cmd->valuestring, "relay") == 0) {
        const cJSON *host = cJSON_GetObjectItem(root, "h");
        const cJSON *port = cJSON_GetObjectItem(root, "p");
        pch_lan_set_relay(cJSON_IsString(host) ? host->valuestring : NULL,
                          cJSON_IsNumber(port) ? (uint16_t)port->valuedouble : 0);
        mine = true;
    }
    cJSON_Delete(root);
    // ตอบกลับด้วยสถานะเต็มใบ ไม่ใช่ ack เปล่า — Mac ต้องเห็นลายนิ้วมือใหม่เพื่อรู้ว่า
    // กุญแจที่มันเพิ่งส่งไปคือกุญแจที่บอร์ดถืออยู่จริง
    if (mine) pch_wifi_report();
    return mine;
}

static void on_config(const char *json, int len)
{
    // คำสั่ง WiFi มาทางเดียวกับความสว่าง แยกด้วยคีย์ "c" — ช่องนี้บังคับเข้ารหัสอยู่แล้ว
    // เพราะรหัส WiFi ต้องผ่านมันไป (pch_ble.h)
    if (lan_command(json, len)) return;
    if (pch_wifi_command(json, len)) return;

    // คอนฟิกที่เหลือมีค่าเดียว: {"b":0..100}
    const char *p = strstr(json, "\"b\"");
    if (!p) return;
    p = strchr(p, ':');
    if (!p) return;
    int value = atoi(p + 1);
    xSemaphoreTake(s_lock, portMAX_DELAY);
    s_pending_backlight = value;
    xSemaphoreGive(s_lock);
}

static void on_link(bool connected)
{
    xSemaphoreTake(s_lock, portMAX_DELAY);
    s_link = connected;
    s_link_changed = true;
    xSemaphoreGive(s_lock);
}

// --- callback จาก esp_wifi (คนละเธรดอีกใบ) -----------------------------------
// ประกอบ JSON ด้วย cJSON ไม่ใช่ snprintf: ชื่อเครือข่ายเป็นข้อความที่ผู้อื่นตั้ง และ
// SSID ที่มีเครื่องหมายคำพูดอยู่ข้างในจะทำให้ฝั่ง Mac แปลงไม่ผ่านทั้งรายการ
static void notify_json(cJSON *root)
{
    char *text = cJSON_PrintUnformatted(root);
    cJSON_Delete(root);
    if (!text) return;
    pch_ble_notify(text, (int)strlen(text));
    cJSON_free(text);
}

static void on_ap(const char *ssid, int8_t rssi, bool secured)
{
    cJSON *root = cJSON_CreateObject();
    if (!root) return;
    cJSON_AddStringToObject(root, "t", "ap");
    cJSON_AddStringToObject(root, "s", ssid);
    cJSON_AddNumberToObject(root, "r", rssi);
    cJSON_AddNumberToObject(root, "e", secured ? 1 : 0);
    notify_json(root);
}

static void on_ap_end(void)
{
    cJSON *root = cJSON_CreateObject();
    if (!root) return;
    cJSON_AddStringToObject(root, "t", "ap_end");
    notify_json(root);
}

static const char *wifi_state_name(pch_wifi_state_t st)
{
    switch (st) {
        case PCH_WIFI_CONNECTING: return "connecting";
        case PCH_WIFI_CONNECTED: return "connected";
        case PCH_WIFI_FAILED: return "failed";
        default: return "off";
    }
}

static void on_wifi_status(pch_wifi_state_t st, const char *ssid, const char *ip,
                           const char *err)
{
    bool up = (st == PCH_WIFI_CONNECTED);
    xSemaphoreTake(s_lock, portMAX_DELAY);
    s_wifi_up = up;
    snprintf(s_ip, sizeof(s_ip), "%s", up && ip ? ip : "");
    s_link_changed = true;
    xSemaphoreGive(s_lock);

    // server ขึ้นตามการมี IP ไม่ใช่ตามการมีกุญแจ — บอร์ดที่รับสายแล้วปฏิเสธทุกเฟรม
    // บอกฝั่ง Mac ได้ว่า "กุญแจไม่ตรง" ส่วนบอร์ดที่ไม่รับสายเลยแยกไม่ออกจากบอร์ดที่ตาย
    pch_lan_set_up(up, ip);

    cJSON *root = cJSON_CreateObject();
    if (!root) return;
    cJSON_AddStringToObject(root, "t", "wifi");
    cJSON_AddStringToObject(root, "st", wifi_state_name(st));
    cJSON_AddStringToObject(root, "s", ssid ? ssid : "");
    cJSON_AddStringToObject(root, "ip", ip ? ip : "");
    // ลายนิ้วมือกุญแจ LAN — ว่างแปลว่ายังไม่เคยตั้ง Mac จะได้รู้ว่าต้องส่งไปให้
    cJSON_AddStringToObject(root, "kf", pch_lan_key_fingerprint());
    // Mac ต้องรู้ id นี้เพื่อบอก relay ว่าจะคุยกับบอร์ดตัวไหน — บอร์ดเป็นคนสร้างเอง
    // ไม่ให้ Mac ตั้ง เพราะมันคือความลับที่กันคนอื่นมาเตะบอร์ดหลุด
    cJSON_AddStringToObject(root, "did", pch_lan_device_id());
    if (err && err[0]) cJSON_AddStringToObject(root, "er", err);

    // รายชื่อที่จำไว้เดินทางมากับสถานะ ไม่ใช่คำสั่งแยก — หน้าตั้งค่าต้องการทั้งคู่พร้อมกัน
    // เสมอ และสองข้อความที่มาไม่พร้อมกันแปลว่ามีจังหวะที่หน้าจอแสดงของครึ่งเดียว
    char saved[PCH_WIFI_MAX_NETS][PCH_WIFI_SSID_CAP];
    int n = pch_wifi_saved(saved, PCH_WIFI_MAX_NETS);
    cJSON *list = cJSON_AddArrayToObject(root, "nets");
    for (int i = 0; list && i < n; i++) {
        cJSON_AddItemToArray(list, cJSON_CreateString(saved[i]));
    }
    notify_json(root);
}

// --- ลูปหลัก -----------------------------------------------------------------

static void apply_pending(void)
{
    pch_snapshot_t snap;
    char ip[sizeof(s_ip)];
    bool got_snapshot = false, link = false, link_changed = false, wifi = false;
    int backlight = -1;

    xSemaphoreTake(s_lock, portMAX_DELAY);
    if (s_has_pending) {
        snap = s_pending;
        s_has_pending = false;
        got_snapshot = true;
    }
    link = s_link;
    wifi = s_wifi_up;
    memcpy(ip, s_ip, sizeof(ip));
    link_changed = s_link_changed;
    s_link_changed = false;
    backlight = s_pending_backlight;
    s_pending_backlight = -1;
    xSemaphoreGive(s_lock);

    // ทาง LAN ไม่มี callback บอกว่ามีใครต่อเข้ามา — ถามเอาตรงนี้ ลูปนี้เดินทุก 10 ms
    // อยู่แล้วและคำตอบคือการอ่านตัวแปรตัวเดียว ถูกกว่าการลากสัญญาณข้ามสองเธรด
    static bool last_lan = false;
    bool lan = pch_lan_client_connected();
    if (lan != last_lan) {
        last_lan = lan;
        link_changed = true;
    }

    if (link_changed) {
        // "สด" คือมีใครสักคนป้อน snapshot อยู่ ไม่ว่าจะทางไหน — จอที่ซ่อนการ์ดทิ้งทั้งที่
        // ข้อมูลกำลังไหลเข้ามาทาง LAN คือจอที่โกหกในทางกลับกัน
        pch_ui_set_connected(link || lan);
        pch_ui_set_link(link, wifi, ip);
    }
    if (got_snapshot) {
        // เวลาบนบอร์ดมาจาก snapshot ที่เดียว — บอร์ดไม่มีนาฬิกาจริงของตัวเอง
        // ต้องตั้งก่อนเรียกอย่างอื่น เพราะโหมดกลางคืนตัดสินจากมัน
        pch_night_set_clock(snap.clock);
        // ไฟอ่านสถานะรวมจาก snapshot เดียวกับที่จอวาด — ไม่ใช่แค่กะพริบตอนมีการเตือนใหม่
        // เพราะคำถามที่ไฟตอบคือ "ตอนนี้ต้องลุกไปทำอะไรไหม" ซึ่งเป็นสภาพต่อเนื่อง
        // ไม่ใช่เหตุการณ์ที่เกิดแล้วผ่านไป
        pch_led_apply(&snap, link || lan);
        pch_ui_set_snapshot(&snap);
    }
    if (backlight >= 0) pch_dim_set_user(backlight);
}

// กระจายสถานะกลางคืนไปให้ทุกคนที่ต้องรู้ — เรียกทุกรอบ แต่ละตัวกันซ้ำเอง
//
// อยู่ตรงนี้ไม่ใช่ใน pch_night เพราะ pch_night ตอบคำถามเดียวคือ "ตอนนี้กลางคืนไหม"
// ส่วนใครต้องทำอะไรกับคำตอบนั้นเป็นเรื่องของการต่อสาย ซึ่งเป็นงานของไฟล์นี้
static void apply_night(void)
{
    bool night = pch_night_active();
    pch_ui_set_night(night);
    pch_led_set_night(night);
    pch_dim_set_night(night);
}

// เปลี่ยนเป็น 1 แล้วแฟลช = จอกลายเป็นสีทึบเต็มพื้นที่ ไม่ทำอย่างอื่นเลย
//
// มีไว้วัดขอบจอเพื่อออกแบบกรอบกล่อง — ปัญหาคือ UI ปกติมีแถบบนสีเข้มซึ่งกลืนไปกับขอบดำ
// ของกระจก ทำให้แยกไม่ออกจากรูปถ่ายว่า "ขอบจอจบตรงไหน ภาพเริ่มตรงไหน" สีทึบสว่างเต็มจอ
// ทำให้เส้นแบ่งนั้นคมจนวัดจากรูปได้ตรงๆ
//
// วัดเสร็จเปลี่ยนกลับเป็น 0 แล้วแฟลชใหม่
#ifndef PCH_CALIBRATION
#define PCH_CALIBRATION 0
#endif

#if PCH_CALIBRATION
// ม่วงบานเย็น ไม่ใช่ขาว — ขาวล้นกล้องง่ายจนขอบฟุ้ง และสีนี้ไม่ไปซ้ำกับอะไรในฉากเลย
// (กล่องส้ม โต๊ะไม้ มือ) การคัดสีจากรูปจึงเหลือเป็นการเลือกช่วงสีเดียว
#define CAL_FILL 0xF81F
// แถบเขียวขอบบน 4 พิกเซล — บอกว่าด้านไหนคือด้านบน รูปที่ถ่ายมาเอียงหรือกลับหัวจะได้รู้
#define CAL_MARK 0x07E0
#define CAL_MARK_H 4

static void calibration_screen(void)
{
    // ไล่ทีละแถว ไม่ได้ทำทั้งจอทีเดียว — เต็มจอคือ 320*240*2 = 150 KB ซึ่งเกินแรมที่มี
    static uint8_t row[PCH_SCREEN_WIDTH * 2];
    for (int y = 0; y < PCH_SCREEN_HEIGHT; y++) {
        uint16_t c = (y < CAL_MARK_H) ? CAL_MARK : CAL_FILL;
        for (int x = 0; x < PCH_SCREEN_WIDTH; x++) {
            // สลับไบต์เอง เพราะทางปกติผ่าน lv_draw_sw_rgb565_swap() ก่อน blit
            // ตรงนี้ไม่ได้ผ่าน LVGL เลย ถ้าไม่สลับจะได้สีคนละสีโดยไม่มีอะไรฟ้อง
            row[x * 2] = (uint8_t)(c >> 8);
            row[x * 2 + 1] = (uint8_t)(c & 0xFF);
        }
        pch_lcd_blit(0, y, PCH_SCREEN_WIDTH - 1, y, row, sizeof(row));
    }
    pch_lcd_set_backlight(100);
    ESP_LOGW("cal", "โหมดสอบเทียบ: จอค้างเป็นสีทึบ แถบเขียวคือด้านบน");
}
#endif

void app_main(void)
{
    esp_err_t err = nvs_flash_init();
    if (err == ESP_ERR_NVS_NO_FREE_PAGES || err == ESP_ERR_NVS_NEW_VERSION_FOUND) {
        ESP_ERROR_CHECK(nvs_flash_erase());
        err = nvs_flash_init();
    }
    ESP_ERROR_CHECK(err);

    s_lock = xSemaphoreCreateMutex();
    pch_mascot_init();
    pch_lcd_init();
#if PCH_CALIBRATION
    // ออกก่อนทุกอย่าง — ไม่เปิด BLE ไม่เปิด WiFi ไม่มีอะไรมาวาดทับ
    calibration_screen();
    return;
#endif
    pch_led_init();
    pch_touch_init();
    pch_dim_init();

    lv_init();
    lv_tick_set_cb(millis_cb);

    s_buf1 = heap_caps_malloc(DRAW_BUF_PX * sizeof(lv_color_t), MALLOC_CAP_DMA);
    s_buf2 = heap_caps_malloc(DRAW_BUF_PX * sizeof(lv_color_t), MALLOC_CAP_DMA);
    assert(s_buf1 && s_buf2);

    lv_display_t *disp = lv_display_create(PCH_SCREEN_WIDTH, PCH_SCREEN_HEIGHT);
    lv_display_set_color_format(disp, LV_COLOR_FORMAT_RGB565);
    lv_display_set_flush_cb(disp, flush_cb);
    lv_display_set_buffers(disp, s_buf1, s_buf2, DRAW_BUF_PX * sizeof(lv_color_t),
                           LV_DISPLAY_RENDER_MODE_PARTIAL);

#if PCH_FACE
    // โหมดทดลองใบหน้า — ออกก่อนจะไปแตะ BLE/WiFi/LED ทั้งหมด เหมือนโหมด calibration
    // ไม่คืนค่า จอจะค้างอยู่ที่หน้าที่ขยับปากอย่างเดียว
    pch_lcd_set_backlight(100);
    pch_face_run();
#endif

    pch_ui_init();
    pch_ui_set_connected(false);
    pch_ui_set_link(false, false, NULL);

    pch_ble_cbs_t cbs = {
        .on_state = on_state,
        .on_config = on_config,
        .on_link = on_link,
    };
    pch_ble_init(&cbs);

    // WiFi ตามหลัง BLE เสมอ: ทางหลักต้องขึ้นก่อน และผลสแกนต้องมีปลายทางให้ส่งไปแล้ว
    pch_wifi_cbs_t wifi_cbs = {
        .on_ap = on_ap,
        .on_ap_end = on_ap_end,
        .on_status = on_wifi_status,
    };
    pch_wifi_init(&wifi_cbs);
    // snapshot ที่มาทาง LAN เข้าประตูเดียวกับที่มาทาง BLE — สองทางเดิน ปลายทางเดียว
    pch_lan_init(on_state);
#if PCH_RELAY_BOOTSTRAP
    pch_lan_set_relay(PCH_RELAY_HOST, PCH_RELAY_PORT);
#endif
#if PCH_RELAYTEST
    // วัด heap ตอนถือ outbound TCP — เริ่มหลังทุกอย่างขึ้นครบ เพื่อให้ตัวเลขสะท้อนของจริง
    void pch_relaytest_start(void);
    pch_relaytest_start();
#endif
    ESP_LOGI(TAG, "ready");

    const int step_ms = 10;
    int since_frame = 0;
    int since_heap = 0;
    while (1) {
        apply_pending();
        // อ่านการแตะทุกรอบ ไม่ใช่ทุกเฟรม — นิ้วที่แตะแล้วยกภายในเฟรมเดียวจะหายไป
        // ถ้ารอถึงจังหวะวาด และการอ่านขาหนึ่งขาถูกกว่าการวาดจอมาก
        if (pch_touch_tapped(step_ms)) {
            // นิ้วเดียวตอบทุกอย่างที่คนที่เพิ่งเดินมาถึงอยากได้พร้อมกัน:
            // เห็นจอชัด ออกจากโหมดกลางคืน และเห็นว่าโควตาเหลือเท่าไร
            pch_night_wake();
            pch_dim_wake();
            pch_ui_peek_usage();
        }
        pch_night_tick(step_ms);
        apply_night();
        pch_dim_tick(step_ms);
        since_frame += step_ms;
        if (since_frame >= 60) {  // ~16 เฟรมต่อวินาที พอสำหรับอนิเมชันบล็อกสี่เหลี่ยม
            pch_ui_tick();
            pch_led_tick(since_frame);
            since_frame = 0;
        }
        // DRAM static เหลือ ~24KB เท่านั้น (idf.py size) ทาง LAN กับ mDNS เป็นสองตัวที่กิน
        // เพิ่มล่าสุด — ที่รั่วช้าๆ จะไม่โผล่จนกว่าจะพังจริง นาทีละบรรทัดพอให้เห็นเทรนด์
        // จาก monitor ธรรมดาโดยไม่ต้องต่อเครื่องมืออะไร · min คือก้นที่เคยลงไปถึง
        since_heap += step_ms;
        if (since_heap >= 60000) {
            since_heap = 0;
            ESP_LOGI(TAG, "heap %u min %u", (unsigned)esp_get_free_heap_size(),
                     (unsigned)esp_get_minimum_free_heap_size());
        }
        lv_timer_handler();
        vTaskDelay(pdMS_TO_TICKS(step_ms));
    }
}

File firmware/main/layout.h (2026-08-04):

// สร้างอัตโนมัติจาก tools/layout.toml — ห้ามแก้ไฟล์นี้ด้วยมือ
// แก้ที่ layout.toml แล้วรัน: python3 tools/export_layout.py
#pragma once

#include <stdint.h>

#define PCH_SCREEN_WIDTH             320
#define PCH_SCREEN_HEIGHT            240

#define PCH_TOPBAR_HEIGHT            22
#define PCH_TOPBAR_LINK_ICON_W       11
#define PCH_TOPBAR_LINK_ICON_H       9
#define PCH_TOPBAR_LINK_ICON_GAP     6

#define PCH_SLOTS_COUNT              3
#define PCH_SLOTS_WIDTH              106
#define PCH_SLOTS_TOP                49
#define PCH_SLOTS_HEIGHT             90
#define PCH_SLOTS_UNIT_PX            4
#define PCH_SLOTS_BASELINE_PAD       19

#define PCH_CARD_TOP                 142
#define PCH_CARD_HEIGHT              98
#define PCH_CARD_PAD                 6
#define PCH_CARD_MAX                 2

#define PCH_USAGE_ROW_H              40
#define PCH_USAGE_GAP                4
#define PCH_USAGE_BAR_H              7
#define PCH_USAGE_COLS               2
#define PCH_USAGE_GUTTER             14
#define PCH_USAGE_ROWS               4
#define PCH_USAGE_SESSION_WINDOW     18000
#define PCH_USAGE_WEEKLY_WINDOW      604800
#define PCH_USAGE_WARN_PCT           60
#define PCH_USAGE_CRIT_PCT           85

#define PCH_WEATHER_DROPS            26
#define PCH_WEATHER_DROP_LEN         7
#define PCH_WEATHER_DROP_SLANT       2
#define PCH_WEATHER_DROP_SPEED_PX_S  150
#define PCH_WEATHER_OVERCAST_CLOUDS  7
#define PCH_WEATHER_FLASH_EVERY_S    9.0f
#define PCH_WEATHER_FLASH_HOLD_S     0.12f

#define PCH_STROLL_SPEED_PX_S        34
#define PCH_STROLL_PAUSE_S           2.5f
#define PCH_STROLL_PAD_PX            96

#define PCH_SKY_HORIZON              120
#define PCH_SKY_DAWN_HOUR            5
#define PCH_SKY_DAY_HOUR             7
#define PCH_SKY_DUSK_HOUR            17
#define PCH_SKY_NIGHT_HOUR           19
#define PCH_SKY_DISC_R               7
#define PCH_SKY_ARC_PEAK             82
#define PCH_SKY_ARC_PAD              0
#define PCH_SKY_TWINKLE_N            4
#define PCH_SKY_STAR_PX              1
#define PCH_SKY_STAR_PEAK_PX         3
#define PCH_SKY_LOW_STAR_N           6
#define PCH_SKY_CLOUD_SPEED_PX_S     4
#define PCH_SKY_CLOUD_PAD            60

#define PCH_SKY_STARS_COUNT          16
static const int16_t pch_sky_stars[PCH_SKY_STARS_COUNT][2] = {
    { 33,  63},
    {128,  67},
    {205,  88},
    {289,  48},
    { 76,  27},
    {247,  71},
    { 14,  33},
    { 58,  82},
    {103,  44},
    {171,  90},
    { 92,  99},
    {149,  37},
    {186,  52},
    {229,  30},
    {268, 101},
    {307,  80},
};

#define PCH_SKY_CLOUDS_COUNT         3
static const int16_t pch_sky_clouds[PCH_SKY_CLOUDS_COUNT][3] = {
    { 40,  44,  44},
    {150,  74,  36},
    {250,  32,  52},
};

#define PCH_SKY_GRASS_X_COUNT        24
static const int16_t pch_sky_grass_x[PCH_SKY_GRASS_X_COUNT] = {
      4,  13,  35,  41,  55,  62,  88,  99, 104, 123, 131, 155,
    168, 174, 191, 200, 228, 235, 247, 268, 273, 288, 298, 310,
};

#define PCH_MASCOT_GRID_W            16.5f
#define PCH_MASCOT_GRID_H            12
#define PCH_MASCOT_CORNER            0.25f

// กรอบวาดมาสคอตรวม prop (หน่วย unit) — มาจาก tools/gen/props.py
#define PCH_BOX_X0                    -0.5f
#define PCH_BOX_X1                    23.4f
#define PCH_BOX_Y0                    -5.6f
#define PCH_BOX_Y1                    12.0f

// จานสีเป็น RGB565 ตามที่แผงจอกินจริง
#define PCH_COL_BG                    0x1081
#define PCH_COL_BG_SLOT               0x18A2
#define PCH_COL_CLAY                  0xDBAA
#define PCH_COL_CLAY_DARK             0xAAA7
#define PCH_COL_CLAY_SLEEP            0x7A26
#define PCH_COL_GRAY                  0x5AEB
#define PCH_COL_GRAY_DARK             0x39E7
#define PCH_COL_INK                   0x10A1
#define PCH_COL_OUTLINE               0xFFFF
#define PCH_COL_TEXT                  0xEF1B
#define PCH_COL_TEXT_DIM              0x8C0F
#define PCH_COL_ACCENT                0xEDC9
#define PCH_COL_ACCENT_WARM           0xDCA4
#define PCH_COL_GLASS                 0xAEDD
#define PCH_COL_STEEL                 0x53B1
#define PCH_COL_ALERT                 0xDAA9
#define PCH_COL_GOOD                  0x5D4B
#define PCH_COL_SKY_OVERCAST          0x6BD0
#define PCH_COL_SKY_STORM             0x3A29
#define PCH_COL_RAIN                  0x9E3B
#define PCH_COL_LIGHTNING             0xFFBB
#define PCH_COL_FOG                   0x9D15
#define PCH_COL_CODEX                 0x4D58
#define PCH_COL_CODEX_DARK            0x33B1
#define PCH_COL_CODEX_SLEEP           0x2A6B
#define PCH_COL_CODEX_EYE             0xAF5E
#define PCH_COL_ANTIGRAV              0x8BFB
#define PCH_COL_ANTIGRAV_DARK         0x62B5
#define PCH_COL_ANTIGRAV_SLEEP        0x41CD
#define PCH_COL_SKY_NIGHT             0x0863
#define PCH_COL_SKY_DAWN              0x3A4F
#define PCH_COL_SKY_DAY               0xBEFE
#define PCH_COL_SKY_DUSK              0x696F
#define PCH_COL_GROUND_NIGHT          0x10C3
#define PCH_COL_GROUND_DAWN           0x1926
#define PCH_COL_GROUND_DAY            0x29C5
#define PCH_COL_GROUND_DUSK           0x20C5
#define PCH_COL_SUN                   0xF525
#define PCH_COL_SUN_LOW               0xEC09
#define PCH_COL_MOON                  0xCE7B
#define PCH_COL_STAR                  0xEF1B
#define PCH_COL_STAR_MID              0xA577
#define PCH_COL_STAR_DIM              0x6BD1
#define PCH_COL_CLOUD_DAY             0xF7DF
#define PCH_COL_CLOUD_DAWN            0x5B73
#define PCH_COL_CLOUD_DUSK            0xC352
#define PCH_COL_GRASS_NIGHT           0x2A07
#define PCH_COL_GRASS_DAWN            0x3287
#define PCH_COL_GRASS_DAY             0x6D4B
#define PCH_COL_GRASS_DUSK            0x5A87
#define PCH_COL_SHADOW_NIGHT          0x0862
#define PCH_COL_SHADOW_DAWN           0x10A3
#define PCH_COL_SHADOW_DAY            0x1923
#define PCH_COL_SHADOW_DUSK           0x1884

// visual state — daemon ส่งค่าพวกนี้มาบน BLE ห้ามเรียงใหม่
typedef enum {
    PCH_STATE_IDLE         = 0,
    PCH_STATE_READING      = 1,
    PCH_STATE_WRITING      = 2,
    PCH_STATE_BUILDING     = 3,
    PCH_STATE_SEARCHING    = 4,
    PCH_STATE_THINKING     = 5,
    PCH_STATE_WAITING      = 6,
    PCH_STATE_SLEEPING     = 7,
    PCH_STATE_ALERT        = 8,
    PCH_STATE_CELEBRATE    = 9,
    PCH_STATE_ERROR        = 10,
    PCH_STATE_ENTERING     = 11,
    PCH_STATE_LEAVING      = 12,
    PCH_STATE_CONDUCTING   = 13,
    PCH_STATE_BEACON       = 14,
    PCH_STATE_COUNT             = 15,
} pch_state_t;

static const char *const pch_state_names[PCH_STATE_COUNT] = {
    "idle",
    "reading",
    "writing",
    "building",
    "searching",
    "thinking",
    "waiting",
    "sleeping",
    "alert",
    "celebrate",
    "error",
    "entering",
    "leaving",
    "conducting",
    "beacon",
};

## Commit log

2026-08-03 feat: multi-agent — แยก Codex ออกจาก Claude ทั้งมาสคอตและโควตา
    จอเดิมสมมติว่ามีเอเจนต์เดียว: ชื่อใต้มาสคอตคือชื่อโฟลเดอร์ ซึ่งแยกไม่ออกเลย
    เมื่อ Claude กับ Codex ทำงานอยู่ในโฟลเดอร์เดียวกัน และแถบโควตาถูกตรึงไว้ที่
    สองหน้าต่างของ Claude
    host:
    - AgentKind (claude/codex/antigravity) เป็นแกนใหม่ใน HookEvent + SessionSnap
    ส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
2026-08-03 feat: สภาพอากาศบนท้องฟ้าที่มีอยู่แล้ว
    ฟ้าของจอนี้วาดเวลาของวันอยู่แล้ว (รุ่ง/วัน/เย็น/คืน + ดวง + ดาว + เมฆลอย)
    แต่แจ่มใสตลอดกาล อากาศจึงเข้าเป็น "อีกแกน" ของฉากเดิม ไม่ใช่แผงใหม่ที่แย่งพื้นที่
    - Open-Meteo เพราะไม่ต้องใช้ API key ตรงกับข้อตกลงของโปรเจกต์ที่ไม่ถือ cred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
2026-08-03 fix: ป้ายบอกไม่ได้ว่าทีมไหน + watcher อ่านทั้งไฟล์จนบล็อก daemon
    สองเรื่องที่เจอจากการใช้จริง
    1. ป้ายซ้ำกันจนแยกทีมไม่ออก
    ทุกทีมวางโครง <project>/agents/<role> เหมือนกัน ป้ายที่เป็นชื่อโฟลเดอร์สุดท้าย
    จึงซ้ำข้ามทีม วัดบนเครื่องจริง: orchestrator โผล่ 18 session, qa 13, ba 11
    ป้ายเลยตอบไม่ได้ว่า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
2026-08-03 fix: อักษรบนสายของ codex ชนกับ claude ทำให้มาสคอตสีไม่เคยเปลี่ยน
    AgentKind.wire ตอนแรก derive จากตัวแรกของชื่อ (String(rawValue.prefix(1)))
    ซึ่ง claude กับ codex ขึ้นต้นด้วย c เหมือนกัน host จึงส่ง "c" ให้ทั้งคู่ ส่วน
    firmware รอ 'x' สำหรับ codex การ map เลยตกไปเป็น claude ทุกครั้ง
    อาการที่เห็นบนจอ: แถบโควตาของ Codex ขึ้นถูกต้อง (ค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
2026-08-03 fix: อ่านหัวไฟล์ 8KB ไม่พอ cwd ของ Codex เลยหลุดทั้ง session
    ตอนเห็นไฟล์ rollout ครั้งแรกเราข้ามไปท้ายไฟล์ แต่ต้องแวะอ่าน session_meta
    ที่บรรทัดแรกก่อนเพราะ cwd อยู่ที่นั่นที่เดียว โค้ดเดิมอ่านหัวมาแบบตายตัว 8KB
    โดยสมมติว่าบรรทัดแรกสั้น
    บรรทัดแรกไม่สั้น — มันบรรจุ instructions/system prompt ทั้งก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
2026-08-03 fix: ข้อความเวลารีเซ็ตล้นไปทับ pill ในตาราง 2 คอลัมน์
    ตอนเปลี่ยนแผงโควตาจากแถวเต็มจอเป็นตาราง 2 คอลัมน์ ช่องแคบลงเหลือครึ่งเดียว
    แต่ข้อความยังเป็น "Resets in 5d 4h" (~90px) ทั้งที่เหลือที่ราว 30px หลังหักเลข %
    กับ pill ผลคือตัวหนังสือทับ pill และมีเศษตัวอักษรโผล่พ้นออกมา
    ตัดคำว่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
2026-08-03 feat: ป้ายบนแถบบนบอกสถานที่แทนชื่อบอร์ด
    ป้ายข้างไอคอนลิงก์เคยเขียนว่า "tamaclaude" ตอนต่อ BLE ติด ซึ่งตอบคำถามที่
    ไอคอนข้างๆ ตอบไปแล้ว พื้นที่ตรงนั้นจึงมีค่ากว่าถ้าบอกอย่างอื่น
    ชื่อสถานที่มาจากไฟล์ตั้งค่าเดิม (`lat,lon,ชื่อ`) ไม่ได้ reverse-geocode เพราะ
    นั่นต้องยิงไปอีกบริก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
2026-08-03 fix: อุณหภูมิถูกวางในพื้นที่ที่แผงโควตาทับอยู่เกือบตลอดเวลา
    เดิมต่อท้ายวันที่ใต้นาฬิกาใหญ่ แต่ตรงนั้นเป็นพื้นที่เดียวกับแผงโควตา ซึ่งโผล่
    อยู่แทบตลอด นาฬิกาใหญ่จะขึ้นก็ต่อเมื่อไม่มีทั้งการ์ดและโควตา อุณหภูมิจึงแทบ
    ไม่มีวันได้เห็นเลย — ฟีเจอร์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
2026-08-03 feat: ภาระเครื่อง (CPU/RAM) ในช่องที่ 4 ของตารางโควตา
    ตารางมี 4 ช่องแต่ daemon ส่งโควตามาแค่ 3 (Claude 5h, Claude weekly, Codex —
    Codex ไม่ส่งหน้าต่างที่สองมา) ช่องที่ 4 จึงว่างเป็นรูตลอด
    CPU/RAM เติมช่องนั้นได้และมีประโยชน์จริงกับเครื่องที่รันหลายเอเจนต์พร้อมกัน
    เวลาทุกอย่างช้าจะได้รู้ว่าเพร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
2026-08-03 fix: preview ฝั่ง Python ตามให้ตรงกับ firmware ที่เปลี่ยนไป
    repo นี้ตั้งข้อตกลงไว้ว่า preview กับ firmware อ่านค่าจากไฟล์เดียวกัน เพื่อให้
    "ภาพที่เห็นบน preview ต่างจากบนบอร์ด = บั๊ก renderer" เป็นจริง (export_layout.py)
    งานที่ผ่านมาแก้แต่ฝั่ง C ข้อตกลงนั้นจึงพังไปหลายรอบ
    ตามให้ครบทั้งชุด:
    - แผงโควตาเป็นต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
    [layout.h]
2026-08-03 fix: เทสต์ที่พังชี้ข้อผิดพลาดจริงสองอย่าง ไม่ใช่เทสต์ล้าสมัย
    UsageReader.read รับ url เป็นพารามิเตอร์เพื่อให้ทดสอบได้ แต่ตอนเพิ่มโควตา Codex
    ผมไปอ่าน ~/.codex แบบ hardcode ข้างใน ฟังก์ชันจึงไม่ hermetic อีกต่อไป — ผลเทสต์
    ขึ้นกับว่าเครื่องที่รันบังเอิญมีข้อมูล Codex อยู่ไหม แยก codexRoot ออกม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
2026-08-03 feat: ไฟบอกสถานะบน RGB LED ของบอร์ด (prototype)
    จอตอบว่า "เกิดอะไรขึ้นบ้าง" ซึ่งต้องหันไปอ่าน ส่วนไฟตอบคำถามเดียว: "ต้องลุกไป
    ทำอะไรไหม" ซึ่งต้องตอบได้โดยไม่ต้องหันหน้า
    - เปลี่ยนจากกะพริบครั้งเดียวตอนมีการเตือนใหม่ เป็นสถานะต่อเนื่องที่อ่านจาก snapshot
    เดียวกับที่จอว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
2026-08-03 fix: hook ต้องไม่ค้าง — เพดานเวลาให้ทุกกระบวนการลูก
    ตัวหาชื่อ tmux session fork `tmux` สองตัวต่อหนึ่ง hook แล้วรอด้วย `waitUntilExit()`
    เปล่าๆ ตัวเรียกคือ hook ที่ยิงทุกครั้งที่เอเจนต์ใช้เครื่องมือ คูณด้วยจำนวน session
    ที่เปิดอยู่ พอเครื่องเข้าใกล้เพดานจำนวนกระบวนการ `tmux` เองก็ fork ไม่ได้และค้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
2026-08-03 feat: ตั้งที่ตั้งพยากรณ์อากาศจากหน้าตั้งค่า ไม่ต้องแก้ไฟล์เอง
    พิกัดเคยอ่านจาก `~/.tamaclaude/location` อย่างเดียว ซึ่งแปลว่าฟีเจอร์นี้เปิดใช้ได้
    เฉพาะคนที่รู้ว่ามีไฟล์นั้นอยู่ — ในทางปฏิบัติคือคนที่เขียนมันเอง
    - ช่องค้นชื่อเมืองในแท็บ General พิมพ์ "Chiang Mai" แล้วเลือกจากร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
2026-08-03 fix: ข้อความเวลาไม่ทับ pill อีก — ล็อกความกว้าง ไม่ใช่ย่อคำแล้วหวัง
    ป้ายเวลาเกาะขอบขวาของเลข % ซึ่งกว้างไม่เท่ากันในแต่ละค่า ส่วน pill อยู่ชิดขอบขวา
    ของช่องตายตัว ระยะที่เหลือจึงเปลี่ยนไปตามข้อมูล — "resetting" ยาว ~54px ในที่ที่
    เหลือ ~42px จึงทับคำว่า Current
    นี่เป็นครั้งที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
2026-08-03 feat: หรี่ไฟหลังเองเมื่อไม่มีใครดู แตะจอเพื่อปลุก
    ไฟหลังกินไฟมากที่สุดบนบอร์ดนี้ บนสาย USB ไม่สำคัญ แต่บนแบตคือความต่างระหว่าง
    ใช้ได้ทั้งวันกับใช้ได้ครึ่งวัน — เตรียมไว้ให้กล่องแบต 18650 ที่กำลังจะมา
    แก้บั๊ก LEDC ที่ต้องแก้ก่อน (ของเดิมผมทำพังเองตอนใส่ไฟบ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
2026-08-03 fix: ปลุกตัวควบคุมสัมผัสก่อน ไม่งั้น PENIRQ ไม่มีวันมา + แตะเพื่อดูโควตา
    การแตะจอที่เพิ่งใส่ไปไม่ทำงานเลย เพราะออกแบบผิดตั้งแต่ต้น: เขียนไว้ว่า "ไม่ต้องคุย
    SPI อ่านแค่ขา PENIRQ" แต่ XPT2046 ไม่ได้ปล่อยสัญญาณนั้นมาตั้งแต่เปิดเครื่อง มันปล่อย
    เมื่ออยู่ในโหมด power-down ที่เป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
    [ct_touch.c, main.c]
2026-08-03 fix: ข้อความเวลาลดความละเอียดแทนที่จะโดนตัดตัวอักษร
    จุดไข่ปลาที่เพิ่งใส่ไปกันข้อความทับ pill ได้จริง แต่ไปตัดค่าปกติทิ้งด้วย: บนบอร์ดจริง
    "4d22h" กลายเป็น "4d…" ทั้งที่ไม่มีอะไรทับกันเลย เพราะผมกะความกว้างจากจำนวนตัวอักษร
    ซึ่งเดาผิด — ฟอนต์ไม่ได้กว้างเท่าก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
2026-08-03 fix: เอาการ fork ออกจาก hook — จากหลายพันครั้งต่อนาที เหลือสองครั้ง
    เครื่องของผู้ใช้หมดโควตากระบวนการสองครั้งในวันเดียว ทั้งสองครั้งมาจากไฟล์เดียวกัน
    ครั้งแรกแก้ที่อาการ (ใส่เพดานเวลาให้ tmux ที่ค้าง) ซึ่งไม่พอ เพราะปัญหาไม่ใช่บั๊ก
    ตัวใดตัวหนึ่ง แต่เป็นการ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
2026-08-03 feat: โหมดกลางคืน — จอเหลือแต่นาฬิกา ไฟดับ ไม่เตือนอะไรทั้งนั้น
    สำหรับเครื่องที่วางในห้องนอน ซึ่งเปลี่ยนความหมายของทุกอย่างบนจอ: ตอนกลางวันมันคือ
    แดชบอร์ดที่ควรเรียกร้องความสนใจเมื่อมีเรื่อง ตอนกลางคืนคนที่อยู่ในห้องไม่ได้จะลุกไป
    แก้อะไร การเตือ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
2026-08-03 test: ตรึงการย้ายงานแปล pane ออกจาก hook ไปที่ daemon
    การแก้ครั้งก่อนย้ายงานที่ fork ออกจากเส้นทางที่ร้อนที่สุด แต่ไม่มีอะไรจับได้เลยว่า
    ฝั่งที่รับงานไปทำได้จริง — ถ้า daemon แปลไม่ได้ ราคาที่จ่ายคือป้ายใต้มาสคอตหายเงียบๆ
    ซึ่งเห็นได้ทางเดียวคือคนไปมองจอ
    ทดสอบ mutation แล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
2026-08-03 fix: หน้าต่างโควตาที่ตายแล้วทับของปัจจุบันไม่ได้ · ลิงก์ที่หลุดถี่ต้องอุ้มทางสำรองไว้
    สองอาการที่โผล่พร้อมกันแต่ไม่เกี่ยวกันเลย พิสูจน์ด้วยการวัดพร้อมกัน: เสียบบอร์ดกลับ
    เข้าสาย USB แล้วตัวเลขยังเต้นต่อ ส่วน BLE ยังหลุดต่อ — คนละสาเหตุ
    ## 1. ตัวเลขบนแถบเ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
2026-08-04 fix: ให้ daemon เขียน cache คนเดียว — ตัดคิว rename() ที่ทำเครื่องล่ม
    เครื่องผู้ใช้เต็มโควตากระบวนการสี่ครั้งในสองวัน สองครั้งแรกผมสรุปสาเหตุผิด (แก้ที่
    tmux fork แล้วที่ exit deadlock) เพราะเดาจากอาการแทนที่จะวัด รอบนี้ไล่จนได้สแตกจริง:
    UsageWriter.write -> replaceItemAt -> _RenameURL -> rename() -> __rename
    ทุกกระบวนการท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
2026-08-04 rename: TamaClaude -> Perch
    โครงการเดินห่างจากต้นทางไปไกลจนชื่อเดิมอธิบายมันไม่ได้แล้ว — มันไม่ใช่การเลี้ยงสัตว์เลี้ยง
    เสมือนอีกต่อไป แต่เป็นจอบอกสถานะ นาฬิกาหัวเตียง และแผงอากาศ ที่รู้ว่า agent กำลังทำอะไร
    สี่ชื่อที่ต้องเปลี่ยนพร้อมกันทั้งสองฝั่ง ไม่งั้น Mac กับบอ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
2026-08-04 rename: คำนำหน้าในเฟิร์มแวร์ ct_ -> pch_
    แยกจากคอมมิตก่อนเพราะแตะ 593 จุดใน 28 ไฟล์ ถ้าบอร์ดไม่บูตจะได้รู้ทันทีว่าเป็นเพราะอันไหน
    ใช้ขอบเขตคำ (`[[:<:]]`) ไม่ใช่แทนสตริงตรงๆ — `ct_` ซ่อนอยู่กลางคำอื่นด้วย
    (`connect_dsc`, `connect_to`) การแทนแบบตาบอดจะทำ NimBLE พังโดยที่ชื่อยังดูถูกต้อง
    ยืนยันด้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
2026-08-04 feat: วาด Codex เป็นตัวของมันเอง — จอบนสองขา ไม่ใช่ Claude ทาสีฟ้า
    เดิมทุกเอเจนต์ใช้มาสคอตตัวเดียวกันแล้วทาสีทับทีหลัง (pch_agent_recolor) ซึ่งแยกกันได้
    ก็ต่อเมื่อสายตาอ่านสีทัน — แต่สิ่งที่อ่านออกก่อนสีคือซิลลูเอ็ต Codex จึงได้จำนวนขาของตัวเอง
    (2 ไม่ใช่ 4) และจอจมสีเข้มแทนหน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
2026-08-04 fix: ตัวติดตั้งต้องจำชื่อเดิมของโครงการได้ ไม่งั้นการอัปเกรดข้ามชื่อทิ้งของพังไว้สองอย่าง
    เจอบนเครื่องจริงตอนสลับจาก TamaClaude มาเป็น Perch ทั้งคู่ไม่มี error ให้เห็นสักบรรทัด
    1. hook งอกเป็นสองเท่า
    ตัวติดตั้งถามว่า "อันนี้ของเราไหม" ด้วยการหาคำว่า `perch` ในคำสั่ง ของ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
2026-08-04 docs: ใช้ลิงก์ affiliate ของเราสำหรับบอร์ด พร้อมบอกผู้อ่านว่าเป็นลิงก์แบบไหน
    ลิงก์ affiliate ที่ไม่บอกผู้อ่านคือสิ่งที่ควรบอก และการบอกว่าซื้อร้านไหนก็ได้ทำให้
    คำแนะนำยังเป็นคำแนะนำ ไม่ใช่การขายของที่แฝงมาในเอกสารติดตั้ง
    Claude-Session: https://claude.ai/cod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
2026-08-04 feat: ตรวจจับ session ของ Antigravity — ค่าที่ประกาศไว้แต่ไม่เคยมีใครผลิต
    `AgentKind.antigravity` มีมานานแล้วและทางเดินครบทั้งเส้น: บอร์ดถอด `'g'` เป็น
    PCH_AGENT_ANTIGRAVITY ได้ จานสีม่วงก็มี — แต่ไม่เคยมีใครผลิตค่านั้นออกมา
    มันจึงไม่เคยโผล่บนจอสักครั้ง Claude มาจาก hook (ซึ่งไม่เคยส่งช่อง agent จึงตกเป็น
    claud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
2026-08-04 feat: วาด Antigravity เป็นซุ้มโค้งตามโลโก้ของมัน — ตัวเดียวในสามที่มองทะลุได้
    ตัวสุดท้ายที่ยังเป็นมาสคอต Claude ทาสีทับ ตอนนี้มีรูปทรงของตัวเองแล้ว: ซุ้มโค้งที่มี
    ช่องว่างอยู่ใต้ตัว ตามรูปตัว "A" ในโลโก้ของ Antigravity
    ช่องโหว่คือตัวแยกที่แรงที่สุดในสามตัว — Claude กับ Codex เป็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
2026-08-04 docs: README บอกของที่มีอยู่จริง — สาม agent, โหมดกลางคืน, จอสัมผัส, อากาศ
    README ยังบรรยายอุปกรณ์ที่รองรับแค่ Claude ไม่มีจอสัมผัส ไม่มีโหมดกลางคืน ซึ่งเป็นของ
    เมื่อสองสัปดาห์ก่อน ตรวจแล้วพบว่าคำว่า Codex กับ Antigravity ไม่ปรากฏสักครั้งในทั้งสองภาษา
    ทั้งที่ทั้งคู่รองรับเต็มรู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
2026-08-09 feat: perch-relay — ท่อไบต์ให้บอร์ดกับ Mac เจอกันตอนอยู่คนละ NAT
    ปัญหาจาก issue #1: พอเอาบอร์ดออกนอกบ้าน มันกับ Mac อยู่หลัง NAT คนละตัว ไม่มีใคร
    รับสายใครได้ ทางแก้คือให้ *ทั้งคู่วิ่งออก* มาเจอกันตรงกลาง NAT จึงหมดความหมาย
    ทำไมไม่ใช่ MQTT: เราต้องการท่อระหว่างสองปลายที่รู้จักกัน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
2026-08-09 feat: บอร์ดวิ่งออกไปหา relay เอง — ใช้งานนอกบ้านได้โดยไม่ต้องพอร์ตฟอร์เวิร์ด
    ครึ่งบอร์ดของ issue #1 ต่อจากตัว relay ในคอมมิตก่อน บอร์ดเปิดสายออกไปหา relay
    พูด "B <device-id>" แล้วค้างสายไว้ ทาง LAN เดิม (mDNS + listener) ยังทำงานเหมือนเดิม
    ทุกอย่าง — relay เป็นทางเลือกท้ายสุด ไม่ใช่ทางแทน
    device-id บอ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
    [main.c]
2026-08-09 feat: ฝั่ง Mac ต่อผ่าน relay ได้ — และแก้บั๊กที่ทำให้ relay ไม่เคยถูกลอง
    ครึ่งสุดท้ายของ issue #1 Mac พูด "H <device-id>" ออกไปหา relay ตัวเดียวกับที่บอร์ด
    วิ่งไปหา ทั้งสองฝั่งวิ่งออก NAT จึงไม่เกี่ยวอีกต่อไป
    บั๊กที่เจอระหว่างทาง: การเลือกปลายทางเดิมเป็นแบบ "เอาตัวแรกที่มี" (manual > mDNS >
    ที่อย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
2026-08-09 fix: เซ็นแอปด้วยใบรับรองคงที่ — สิทธิ์ Bluetooth ไม่หลุดทุกครั้งที่บิลด์ใหม่
    อาการ: นาฬิกาบนบอร์ดค้าง ไม่มี error ที่ไหนเลย ไม่มี crash report ไม่มีบรรทัดใน log
    แอปเปิดอยู่ปกติ daemon ทำงานปกติ แค่ไม่มีอะไรไปถึงบอร์ด
    สาเหตุ: การเซ็นแบบ adhoc (--sign -) ทำให้ designated requirement ของแอปผูกกับ cdhash
    ซึ่งค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
2026-08-12 docs: รูปถ่ายจริงกับไฟล์ STL ของเคส — พร้อมเปิด repo สาธารณะ
    README เดิมมีแต่ภาพจากจอ (GIF ของหน้า UI) ซึ่งบอกว่าซอฟต์แวร์ทำอะไรได้ แต่ไม่ได้บอกว่า
    ของจริงหน้าตายังไงเมื่อวางบนโต๊ะ คนที่เจอ repo ครั้งแรกจึงตัดสินใจไม่ได้ว่าอยากได้ไหม
    รูปสี่ใบเลือกให้ตอบคนละคำถาม ไม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
    [back_cover.stl, front_case_v4_slot.stl]
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

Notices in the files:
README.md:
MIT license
